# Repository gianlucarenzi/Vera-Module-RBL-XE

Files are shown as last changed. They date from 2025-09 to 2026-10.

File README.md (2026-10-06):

# VERA Module RBL-XE

<div align="center">






*🌐 English | [🌐 Italiano](#vera-module-rbl-xe-italiano)*

</div>

---

<div style="background: #ffffff; border-radius: 16px; padding: 24px; margin: 24px 0; box-shadow: 0 4px 12px rgba(0,0,0,0.1); border: 1px solid #e0e0e0;">

## 📋 Table of Contents

- [🔍 Overview](#-overview)
- [✨ Features](#-features)
- [⚙️ Technical Specifications](#️-technical-specifications)
- [🔧 Hardware Components](#-hardware-components)
- [🖼️ Board Preview](#️-board-preview)
- [📐 PCB Layers](#-pcb-layers)
- [🔌 Connectors & Interfaces](#-connectors--interfaces)
- [⚡ Power Requirements](#-power-requirements)
- [🔨 Assembly Instructions](#-assembly-instructions)
- [📦 Bill of Materials](#-bill-of-materials)
- [💻 Programming & Configuration](#-programming--configuration)
- [📁 Project Structure](#-project-structure)
- [🤝 Contributing](#-contributing)
- [📄 License](#-license)

</div>

---

<div style="background: #ffffff; border-radius: 16px; padding: 24px; margin: 24px 0; box-shadow: 0 4px 12px rgba(0,0,0,0.1); border: 1px solid #e0e0e0;">

## 🔍 Overview

The **VERA Module RBL-XE** is a sophisticated FPGA-based audio and video 
expansion card designed specifically for **ATARI XE** computers. 
This module brings modern graphics and audio capabilities to classic ATARI systems 
through the **PBI (Parallel Bus Interface)** protocol connectors.

### What is VERA?

**VERA** (Video Enhanced Retro Adapter) is originally designed for the 
Commander X16 computer but has been adapted for ATARI systems. It provides:

- **Advanced Graphics**: Multiple video layers, sprites, and high-resolution modes
- **Enhanced Audio**: Multi-channel digital audio with PCM and PSG capabilities  
- **Modern Connectivity**: VGA output, SD card storage, and USB programming
- **Retro Compatibility**: Integration with ATARI software with simple drivers

</div>

---

<div style="background: #ffffff; border-radius: 16px; padding: 24px; margin: 24px 0; box-shadow: 0 4px 12px rgba(0,0,0,0.1); border: 1px solid #e0e0e0;">

## ✨ Features

### 🎨 Graphics Capabilities

#### Video Output
- **VGA Output**: 640x480 @ 60Hz with analog RGB signals
- **Multiple Layers**: Background, foreground, and sprite layers
- **Color Depth**: 256 colors from a palette of 4096
- **Sprites**: Hardware-accelerated sprite engine
- **Scrolling**: Smooth horizontal and vertical scrolling

#### Audio Features
- **Digital Audio**: High-quality PCM audio output
- **Multi-channel**: Stereo audio
- **Audio Codec**: WM8524 for professional audio quality
- **3.5mm Jack**: Standard audio output connector

### 🔗 System Integration

#### ATARI Compatibility
- **PBI Interface**: Direct connection to ATARI XE systems
- **Memory Mapping**: $D1XX-$DFXX address space
- **Bus Decoder**: Full software address decoding in ESP32 — A0–A15 sampled every PHI2 cycle, no external hardware decoder required
- **Power Management**: Efficient 5V to 3.3V/1.2V conversion

#### Storage & Programming
- **SD Card Slot**: Micro SD for data storage and ROM loading
- **SPI Flash**: 16Mbit W25Q16 for FPGA configuration
- **USB Programming**: CH340 USB-to-serial for easy updates
- **SPI**: Direct FPGA programming interface

</div>

---

<div style="background: #ffffff; border-radius: 16px; padding: 24px; margin: 24px 0; box-shadow: 0 4px 12px rgba(0,0,0,0.1); border: 1px solid #e0e0e0;">

## ⚙️ Technical Specifications

### Core Specifications

| Component | Specification |
|---|---|
| **FPGA** | Lattice ICE40UP5K-SG48ITR |
| **Microcontroller** | ESP32-S3FN8 |
| **Flash Memory** | W25Q16JVSNIQ (16Mbit) |
| **Audio Codec** | WM8524CGEDT |
| **USB Interface** | CH340T |
| **Power Regulators** | AMS1117-3.3V, AMS1117-1.2V, L7805 |
| **Crystal (VERA board)** | 25 MHz ECS-2033-250-BN (ICE40UP5K reference clock) |
| **Crystal (ESP32-S3)** | 40 MHz external — required; XTAL\_P (QFN56 pin 56) / XTAL\_N (pin 55) |
| **PCB Layers** | 4-layer (Signal/Power/GND/Signal) |
| **Board Size** | TBD mm x TBD mm |

### Electrical Characteristics

| Parameter | Min | Typ | Max | Unit |
|---|-----|-----|-----|---|
| **Supply Voltage** | 4.5 | 5.0 | 5.5 | V |
| **Current Consumption** | - | 800 | 1200 | mA |
| **Operating Temperature** | -10 | 25 | 70 | °C |
| **VGA Output Impedance** | - | 75 | - | Ω |
| **Audio Output Level** | - | 2.0 | - | Vrms |

</div>

---

<div style="background: #ffffff; border-radius: 16px; padding: 24px; margin: 24px 0; box-shadow: 0 4px 12px rgba(0,0,0,0.1); border: 1px solid #e0e0e0;">

## 🔧 Hardware Components

### Main Processing Units

#### FPGA - ICE40UP5K
- **Logic Elements**: 5,280 LUTs
- **Memory**: 120 Kbit BRAM, 1 Mbit SPRAM
- **I/O Pins**: 39 user I/O
- **Package**: QFN-48 (7x7mm)
- **Programming**: SPI configuration

#### ESP32-S3FN8
- **CPU**: Dual-core Xtensa LX7 @ 240 MHz
- **Memory**: 8 MB in-package Quad SPI flash, 512 KB SRAM
- **Connectivity**: Wi-Fi 802.11 b/g/n, Bluetooth 5 LE
- **GPIO**: 45 total (38 usable), all bidirectional
- **Package**: QFN-56 (7×7 mm)
- **Crystal**: requires an external **40 MHz crystal** on dedicated analog pins XTAL\_P (QFN56 pin 56) and XTAL\_N (pin 55) — mandatory for PLL startup; see PIN-MAPPING.md § 5
- **Role**: Full software 6502-bus controller — reads A0–A15, PHI2, R/W every cycle and drives EXTSEL\_N, DEV\_SEL\_N, MPD in real time; handles PBI ($D1xx) and CCTL ($D5xx) in a single unified firmware
- **Timing**: hot loop on Core 1 at max FreeRTOS priority; control signals asserted via **Dedicated GPIO** Xtensa TIE instructions (`ee.get_gpio_in` / `ee.wr_mask_gpio_out`, 1 CPU cycle) within the 279 ns PHI2-high window of the 1.79 MHz 6502 clock

### Interface Components

#### Audio System
- **Codec**: WM8524CGEDT (24-bit, 192kHz)
- **Interface**: From FPGA digital audio bus
- **Output**: 3.5mm stereo jack
- **SNR**: >100dB

#### Video System
- **Output**: 15-pin VGA connector
- **Resolution**: 640x480 @ 60Hz
- **Colors**: 8-bit RGB (256 colors)
- **Sync**: Separate H/V sync signals

</div>

---

<div style="background: #ffffff; border-radius: 16px; padding: 24px; margin: 24px 0; box-shadow: 0 4px 12px rgba(0,0,0,0.1); border: 1px solid #e0e0e0;">

## 🖼️ Board Preview

### 3D Renderings

#### Top View
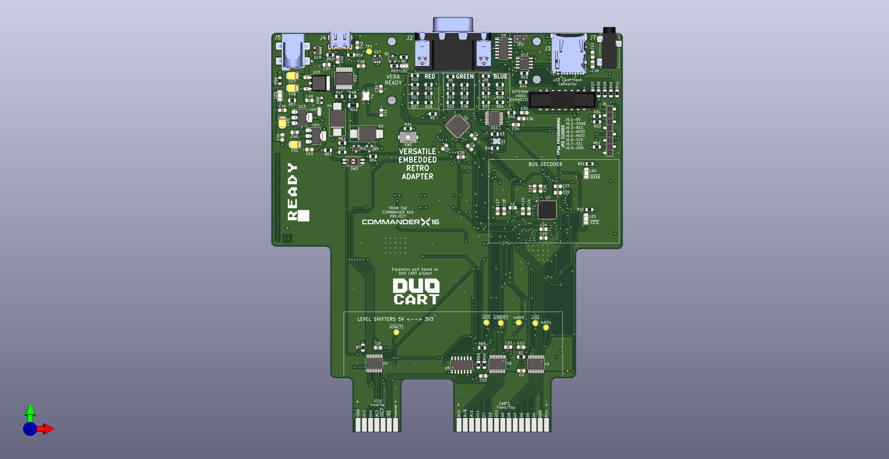
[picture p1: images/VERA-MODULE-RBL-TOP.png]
VERA Module Top

*Top side showing main components and connectors*

#### Bottom View  
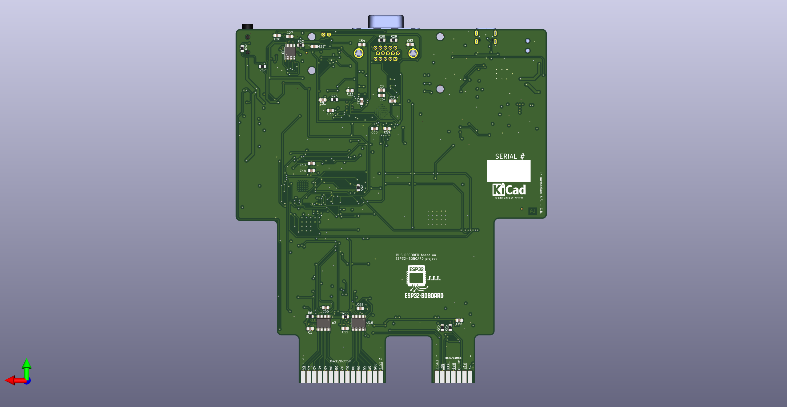
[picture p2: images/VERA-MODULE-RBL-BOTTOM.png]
VERA Module Bottom

*Bottom side with additional components*

#### Cartridge Adapter
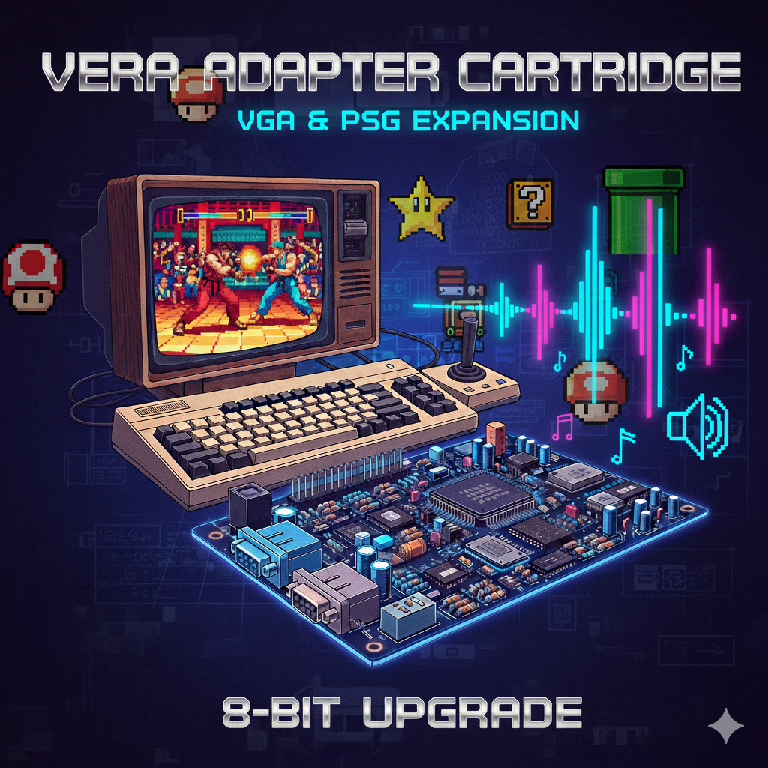
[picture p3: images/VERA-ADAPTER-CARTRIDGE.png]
VERA Cartridge Adapter

*Optional cartridge interface adapter*

### Board Dimensions

- **Length**: TBD mm
- **Width**: TBD mm  
- **Thickness**: 1.6mm (4-layer PCB)
- **Mounting**: Compatible with ATARI XE CART + ECI slots
- **Connectors**: Flat for space efficiency. It needs a custom 3D printed case

</div>

---

<div style="background: #ffffff; border-radius: 16px; padding: 24px; margin: 24px 0; box-shadow: 0 4px 12px rgba(0,0,0,0.1); border: 1px solid #e0e0e0;">

## 📐 PCB Layers

### Layer Stack-up

#### Layer 1 - Top Copper (F.Cu)
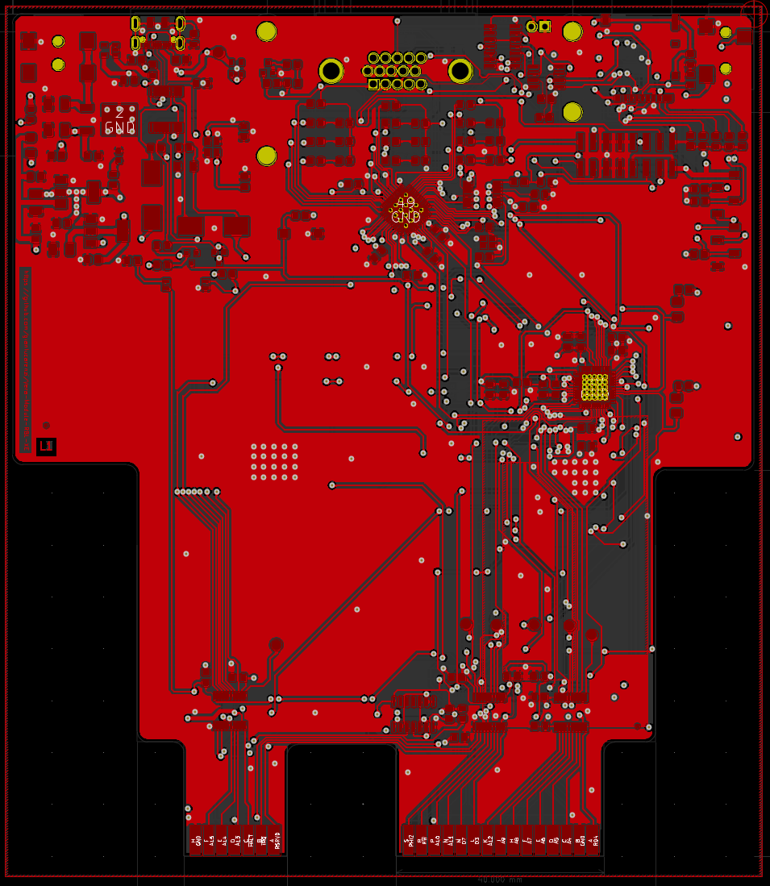
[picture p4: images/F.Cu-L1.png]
Top Copper Layer

*Component placement and signal routing*

#### Layer 2 - Power Plane (POWER)
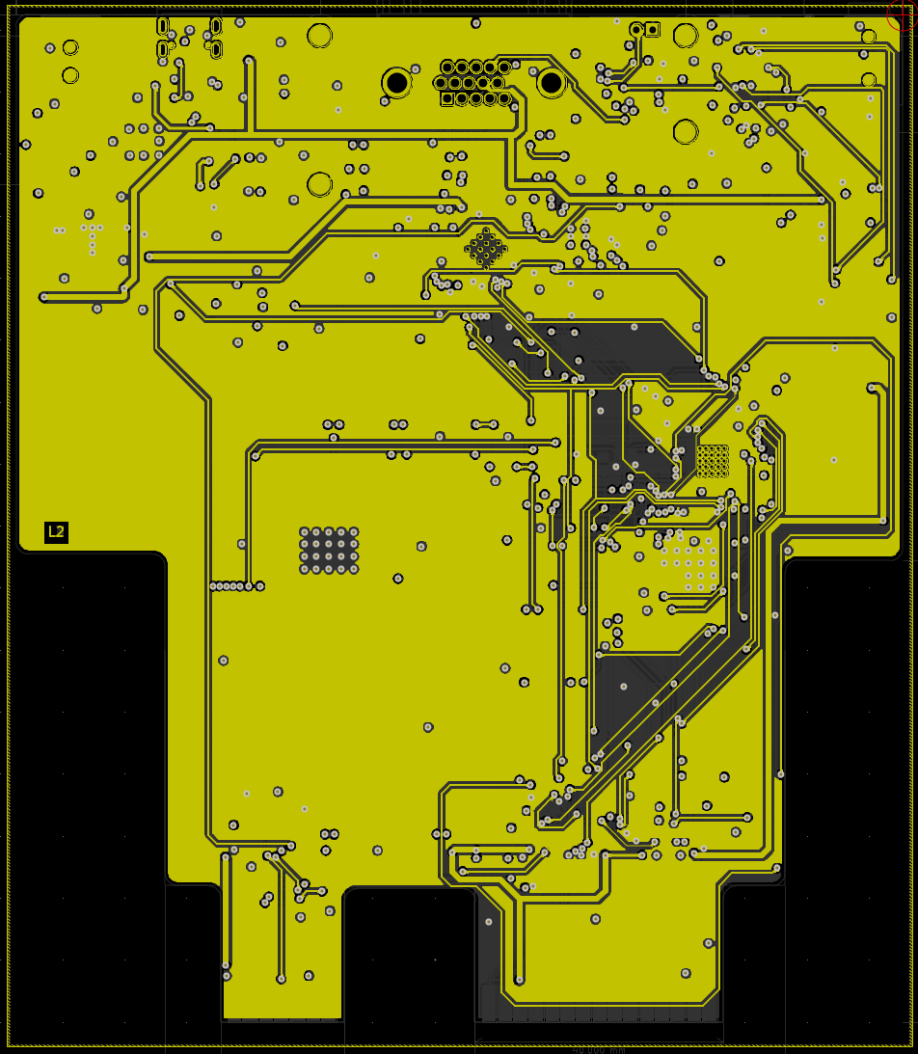
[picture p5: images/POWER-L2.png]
Power Layer

*5V, 3.3V, and 1.2V power distribution*

#### Layer 3 - Ground Plane (GND)
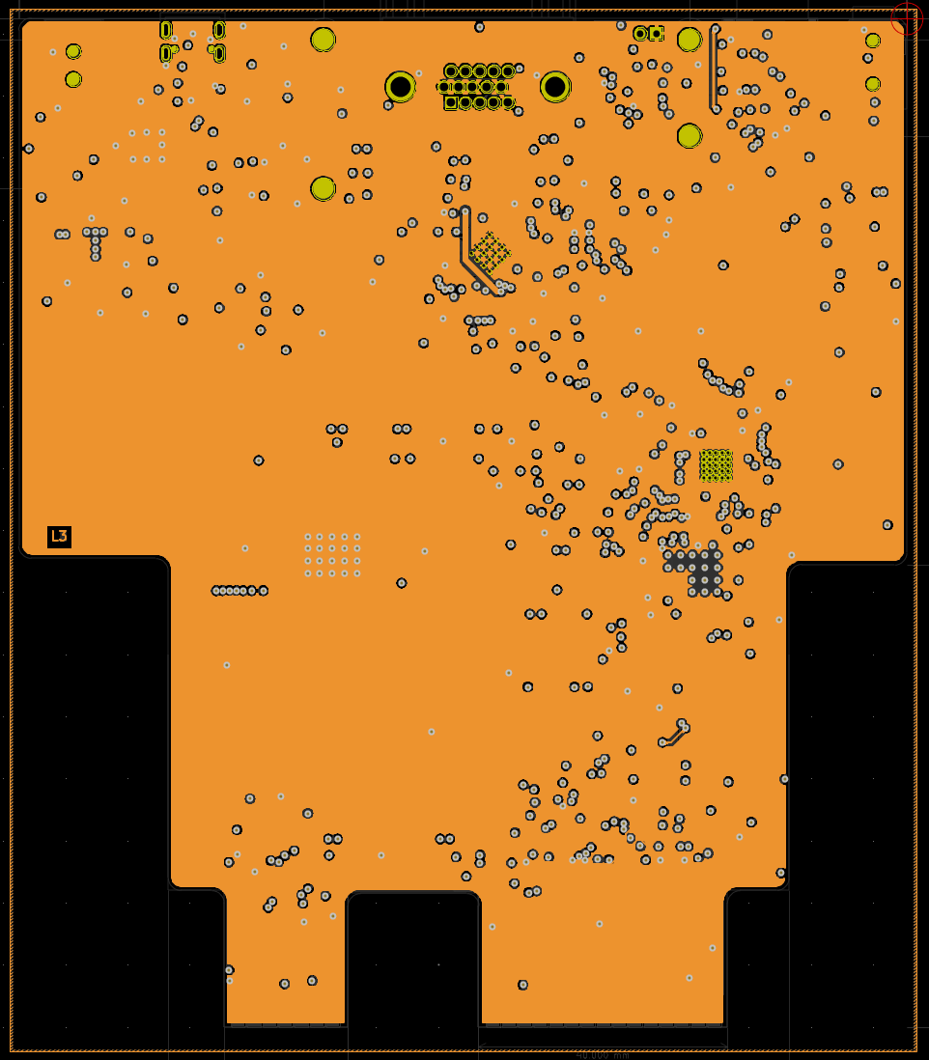
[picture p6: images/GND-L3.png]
Ground Layer

*Solid ground plane for signal integrity*

#### Layer 4 - Bottom Copper (B.Cu)
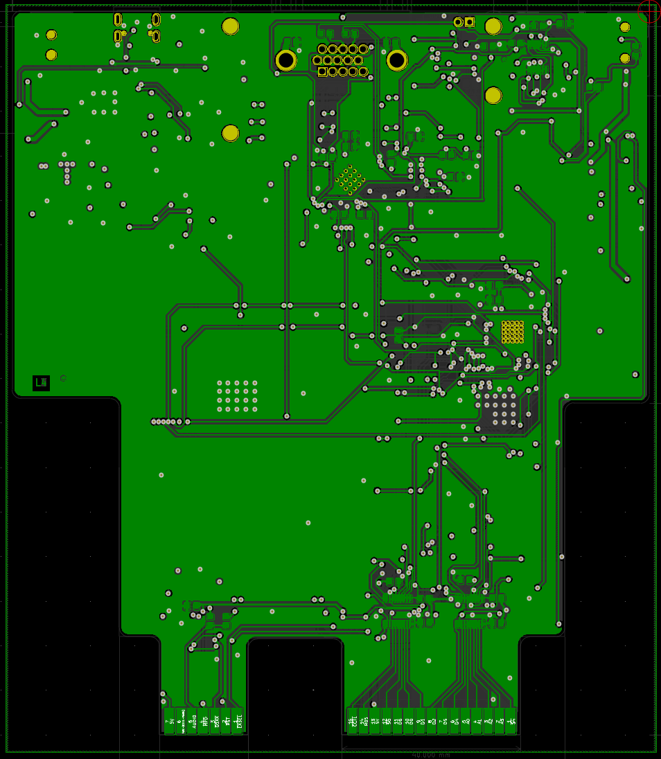
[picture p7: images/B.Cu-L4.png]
Bottom Copper Layer

*Additional signal routing and components*

</div>

---

<div style="background: #ffffff; border-radius: 16px; padding: 24px; margin: 24px 0; box-shadow: 0 4px 12px rgba(0,0,0,0.1); border: 1px solid #e0e0e0;">

## 🔌 Connectors & Interfaces

### External Connections

#### ATARI XE Interface
- **Cartridge Connector**: Classic Cartridge Edge Connector 30 pin 
- **ECI Slot**: Enhanced Cartridge Interface 14 pin 
- **Address Range**: $D1XX-$DFXX
- **Signals**: Data bus, address bus, control signals

#### Video Output (J2)
| Pin | Signal | Description |
|-----|---|---|
| 1-3 | RGB | Red, Green, Blue analog signals |
| 13-14 | H/V Sync | Horizontal/Vertical sync |
| 6-10 | GND | Ground connections |
| 11-12 | Audio L/R | Stereo audio output |

#### Storage Interfaces
- **SD Card Slot (J3)**: Micro SD card interface
- **SPI Flash**: On-board 16Mbit storage
- **USB Port (J4)**: Programming and data transfer

### Programming Interfaces

#### ICEPROG Connector (J6)
| Pin | Signal | Function |
|-----|---|---|
| 1 | 5V | Power supply |
| 2 | FPGA_CDONE/PULL-UP | FPGA Programmed |
| 3 | FPGA_RESET | FPGA Reset |
| 4 | MISO | SPI data in |
| 5 | MOSI | SPI data out |
| 6 | SCK | SPI clock |
| 7 | SS | SPI select |
| 8 | GND | Ground |

#### Reset & Control
- **Reset Button (SW1)**: ESP32 system reset
- **DIP Switch (SW2)**: Configuration options
- **Status LEDs**: Power, programming, activity indicators

</div>

---

<div style="background: #ffffff; border-radius: 16px; padding: 24px; margin: 24px 0; box-shadow: 0 4px 12px rgba(0,0,0,0.1); border: 1px solid #e0e0e0;">

## ⚡ Power Requirements

### Power Distribution

#### Power Rails
| Rail | Voltage | Current | Components |
|---|---|---|---|
| **5V** | 5.0V ± 5% | 200mA | Input from ATARI, USB |
| **3.3V** | 3.3V ± 3% | 400mA | ESP32, logic, interfaces |
| **1.2V** | 1.2V ± 3% | 300mA | FPGA core voltage |

#### Power Sources
1. **ATARI PBI**: Primary 5V supply from computer
2. **USB**: Alternative 5V for programming/testing
3. **External**: Optional external 5V supply (J5)

#### Power Protection
- **Schottky Diodes**: Reverse polarity protection
- **Ferrite Beads**: EMI filtering
- **Decoupling**: Extensive capacitor network
- **Current Limiting**: Overcurrent protection

</div>

---

<div style="background: #ffffff; border-radius: 16px; padding: 24px; margin: 24px 0; box-shadow: 0 4px 12px rgba(0,0,0,0.1); border: 1px solid #e0e0e0;">

## 🔨 Assembly Instructions

### Component Assembly

#### Assembly Order
1. **SMD Components**: Start with smallest components (0603, 0805)
2. **ICs**: Place all integrated circuits
3. **Connectors**: Install all external connectors
4. **Through-hole**: Add any remaining THT components
5. **Testing**: Verify power rails before first power-on

#### Special Considerations
- **FPGA**: Use proper ESD precautions
- **BGA Components**: Requires professional assembly
- **Thermal Management**: Ensure adequate cooling
- **Impedance Control**: Maintain 50Ω for high-speed signals

### Testing & Validation

#### Power-On Tests
1. **Visual Inspection**: Check for shorts, proper orientation
2. **Power Rails**: Verify all voltages within tolerance
3. **Clock Signals**: Confirm oscillator operation
4. **Communication**: Test SPI, I2C, UART interfaces

#### Functional Tests
1. **FPGA Programming**: Load test bitstream
2. **Video Output**: Verify VGA signal generation
3. **Audio Output**: Test audio codec functionality
4. **ATARI Interface**: Confirm PBI communication protocol

</div>

---

<div style="background: #ffffff; border-radius: 16px; padding: 24px; margin: 24px 0; box-shadow: 0 4px 12px rgba(0,0,0,0.1); border: 1px solid #e0e0e0;">

## 📦 Bill of Materials

### Component Categories

#### Major Components
- **1x** ICE40UP5K-SG48ITR FPGA
- **1x** ESP32-S3FN8 Microcontroller  
- **1x** W25Q16JVSNIQ SPI Flash
- **1x** WM8524CGEDT Audio Codec
- **1x** CH340T USB Interface

#### Passive Components
- **23x** 1µF Capacitors (1206)
- **20x** 100nF Capacitors (1206)
- **6x** 10µF Capacitors (1206)
- **Various** Resistors (0805/1206)
- **1x** 25 MHz Crystal Oscillator (VERA board — ICE40UP5K reference clock)
- **1x** 40 MHz Crystal + 2×10 pF load capacitors (ESP32-S3 — mandatory)

#### Connectors
- **1x** 15-pin VGA Connector
- **1x** Micro SD Card Slot
- **1x** USB Type-C Connector
- **1x** 3.5mm Audio Jack
- **1x** 8-pin Programming Header

### Cost Analysis

| Category | Estimated Cost | Percentage |
|---|---|---|
| **FPGA** | $15-20 | 35% |
| **ESP32** | $8-12 | 20% |
| **Connectors** | $5-8 | 15% |
| **Passives** | $3-5 | 10% |
| **PCB** | $8-12 | 20% |
| **Total** | **$39-57** | **100%** |

*Costs are estimates for small quantity production*

</div>

---

<div style="background: #ffffff; border-radius: 16px; padding: 24px; margin: 24px 0; box-shadow: 0 4px 12px rgba(0,0,0,0.1); border: 1px solid #e0e0e0;">

## 💻 Programming & Configuration

### FPGA Programming

#### Programming Methods
1. **USB/Serial**: Using FTDI 232H adapter interface with iceprog
2. **SPI Direct**: Direct SPI flash programming

#### Programming Steps
```bash
# Install icestorm toolchain
sudo apt install fpga-icestorm

# Program FPGA via USB (The FPGA bitstream is not provided!)
iceprog vera_module.bin

# Verify programming
iceprog -c
```

#### Development Tools
- **IceStorm**: Open-source FPGA toolchain
- **Yosys**: Verilog synthesis
- **NextPNR**: Place and route
- **KiCad**: PCB design and layout

### ESP32 Configuration

#### ESP32 Firmware
The ESP32-S3FN8 (Core 1 hot loop) handles:
- **Startup sync**: ARESET and CRESET asserted LOW immediately in `setup()` (before `Serial.begin`). `MonitorTask` releases CRESET, polls CDONE until the ICE40UP5K bitstream is loaded (< 100 ms typical, 5 s timeout), then releases ARESET — Atari starts with bus and FPGA already ready
- **Bus Decoding**: Full software decode of A0–A15 sampled on every PHI2 rising edge — no page ambiguity
- **Dedicated GPIO**: Control signals (EXTSEL\_N, DEV\_SEL\_N, MPD) asserted in a single Xtensa TIE instruction (`ee.wr_mask_gpio_out`, 1 CPU cycle) within the 279 ns PHI2-high window
- **Data Bus Drive** *(PBI mode only)*: D0–D7 driven via `GPIO.out` for ROM ($D800–$DFFF) and RAM ($D600–$D7FF) reads; FPGA drives the bus in CCTL mode
- **Debugging**: UART0 on GPIO43 (TX) / GPIO44 (RX), 115200 baud

The operating mode is selected at compile time via `VERA_BOARD_IS_PBI` in `main.cpp`:

| `VERA_BOARD_IS_PBI` | Mode | Active ranges | Selection latch |
|---|---|---|---|
| `1` (default) | PBI | $D100–$D1FF, $D600–$D7FF, $D800–$DFFF | write `0x80` to $D1FF |
| `0` | CCTL | $D500–$D5FF | write `0x80` to $D5FF |

The **RAMbo 256 KB** emulator is always compiled in and enabled at runtime via **GPIO 3**
(`PIN_RAMBO_EN`, QFN56 pin 8) — no recompilation needed:

| GPIO 3 at boot | Effect |
|---|---|
| Pull-up 10 kΩ → VCC (HIGH) | RAMbo enabled — 256 KB bank-switched at $4000–$7FFF; PORTB ($D301) bit 4 selects active/inactive |
| Pull-down 10 kΩ → GND (LOW) | RAMbo disabled — $4000–$7FFF not intercepted |

Works in both PBI and CCTL mode. The hot loop snoops both **PBCTL** (`$D303`) and
**PORTB** (`$D301`): writes to `$D301` update the bank-selection register **only when**
PBCTL bit 2 = 1 (output register selected). When bit 2 = 0, `$D301` addresses the PIA
6520 DDR and the write is ignored for bank-switching purposes. `PORTB` initialises to
`0xFF` (RAME = 1, RAMbo inactive); `PBCTL` to `0x00` (bit 2 = 0, DDR exposed).

**Passive snooping vs. active driving — no conflict with the physical 6520.** The real
6520 PIA chip remains fully active on the Atari motherboard and responds to `$D301`/`$D303`
normally. The ESP32 does **not** replace the 6520 — it only snoops those bus cycles
(observes without driving). It only actively drives the data bus and asserts EXTSEL\_N
for the `$4000–$7FFF` window, where the 6520 is not mapped. PBCTL tracking is necessary
precisely because the snooping is passive: from the bus, a DDR write and an Output Register
write to `$D301` are **indistinguishable** — PBCTL state is the only way to tell them apart.

#### Programming ESP32
The firmware is built with **PlatformIO** (install via `pip install platformio`):
```bash
# Build firmware (edit VERA_BOARD_IS_PBI in main.cpp before building)
pio run -e esp32s3fn8

# Flash firmware — connect UART adapter to GPIO43/44
pio run -e esp32s3fn8 --target upload
```

> **Note**: USB CDC is disabled because GPIO 19 (USB D−) and GPIO 20 (USB D+) are reused
> as address lines A7 and A8. Use an external UART adapter on GPIO 43/44.

</div>

---

<div style="background: #ffffff; border-radius: 16px; padding: 24px; margin: 24px 0; box-shadow: 0 4px 12px rgba(0,0,0,0.1); border: 1px solid #e0e0e0;">

## 📁 Project Structure

### Repository Organization

```
Vera-Module-RBL-XE/
├── 📄 README.md                    # This documentation
├── 📄 PIN-MAPPING.md               # ESP32-S3 / level-shifter pin mapping
├── 📄 VERA-ATARI-HW-REQUIREMENTS.md # Hardware requirements & bring-up plan (from driver/emulator work)
├── 📄 LICENSE                      # GPL v3 license
├── ⚙️ VERA-MODULE-RBL.pro         # KiCad project file
├── 📄 VERA-MODULE-RBL.sch         # Main schematic
├── 🔧 VERA-MODULE-RBL.kicad_pcb   # PCB layout
├── 📄 VERA-MODULE-RBL.csv         # Bill of materials
├── 🐍 jlcpcb-check-bom.py        # BOM processing script
├── 📁 images/                      # Board images and renders
│   ├── 🖼️ VERA-MODULE-RBL-TOP.png
│   ├── 🖼️ VERA-MODULE-RBL-BOTTOM.png
│   ├── 🖼️ F.Cu-L1.png            # PCB layer images
│   ├── 🖼️ POWER-L2.png
│   ├── 🖼️ GND-L3.png
│   └── 🖼️ B.Cu-L4.png
├── 📁 production/                  # Manufacturing files
│   ├── 📄 *.gbl, *.gtl            # Gerber files
│   ├── 📄 *.drl                   # Drill files
│   └── 📄 *.gbrjob                # Job files
├── 📁 ibom/                       # Interactive BOM
│   └── 🌐 ibom.html
└── 📁 schematics/                 # Individual schematics
    ├── 📄 vera-fpga.sch           # FPGA module
    ├── 📄 busdecoder.sch          # Bus decoder
    ├── 📄 cartridgeInterface.sch   # Cartridge interface
    ├── 📄 vera-fpga-flash.sch     # Flash memory
    └── 📄 powersupply.sch         # Power management
```

### Hardware notes (read before bring-up)

- [`VERA-ATARI-HW-REQUIREMENTS.md`](VERA-ATARI-HW-REQUIREMENTS.md) — what the VERA FPGA
  requires from the bus, open points on this board (U19 output enable, WR hold time,
  push-pull IRQ), the gating logic for the data-bus transceiver output enable,
  reset/configuration sequence and the bring-up test plan.

### Design Files

#### KiCad Files
- **Schematic**: Multi-sheet hierarchical design
- **PCB Layout**: 4-layer board with controlled impedance
- **3D Models**: Custom component models
- **Footprints**: Custom connector footprints

#### Manufacturing Files
- **Gerber Files**: Industry-standard PCB fabrication
- **Drill Files**: NC drill and via specifications  
- **Pick & Place**: SMT assembly coordinates
- **BOM**: Component specifications with LCSC part numbers

</div>

---

<div style="background: #ffffff; border-radius: 16px; padding: 24px; margin: 24px 0; box-shadow: 0 4px 12px rgba(0,0,0,0.1); border: 1px solid #e0e0e0;">

## 🤝 Contributing

### Development Guidelines

#### Contributing Process
1. **Fork** the repository
2. **Create** a feature branch
3. **Make** your changes
4. **Test** thoroughly
5. **Submit** a pull request

#### Contribution Areas
- **Hardware Design**: PCB layout improvements
- **Firmware**: ESP32 and FPGA code
- **Documentation**: User guides and tutorials
- **Testing**: Validation and verification
- **Software**: Host applications and tools

#### Design Goals
- **Compatibility**: Maintain ATARI XE compatibility
- **Performance**: Optimize for speed and efficiency
- **Reliability**: Ensure robust operation
- **Manufacturability**: Design for production
- **Cost**: Balance features with affordability

</div>

---

<div style="background: #ffffff; border-radius: 16px; padding: 24px; margin: 24px 0; box-shadow: 0 4px 12px rgba(0,0,0,0.1); border: 1px solid #e0e0e0;">

## 📄 License

This project is licensed under the **GNU General Public License v3.0**.

### License Details

#### Permissions
- ✅ Commercial use
- ✅ Modification
- ✅ Distribution
- ✅ Patent use
- ✅ Private use

#### Limitations
- ❌ Liability
- ❌ Warranty

#### Conditions
- 📄 License and copyright notice
- 📄 State changes
- 📄 Disclose source
- 📄 Same license

For the complete license text, see the [LICENSE](LICENSE) file.

</div>

---

<div style="background: linear-gradient(135deg, #1976d2, #42a5f5); color: white; border-radius: 16px; padding: 32px; margin: 32px 0; box-shadow: 0 8px 24px rgba(25,118,210,0.3); text-align: center;">

## 💙 Support the Project

If you find this project useful, please consider:

🌟 **Starring** the repository  
🐛 **Reporting** issues  
🔧 **Contributing** improvements  
📢 **Sharing** with the community  

---

**Made with ❤️ by RetroBit Lab**

*Bringing modern capabilities to classic computers*

</div>

---

# VERA Module RBL-XE (Italiano)

<div align="center">

*[🌐 English](#vera-module-rbl-xe) | 🌐 Italiano*

</div>

---

<div style="background: #ffffff; border-radius: 16px; padding: 24px; margin: 24px 0; box-shadow: 0 4px 12px rgba(0,0,0,0.1); border: 1px solid #e0e0e0;">

## 📋 Indice

- [🔍 Panoramica](#-panoramica)
- [✨ Caratteristiche](#-caratteristiche)
- [⚙️ Specifiche Tecniche](#️-specifiche-tecniche)
- [🔧 Componenti Hardware](#-componenti-hardware)
- [🖼️ Anteprima Scheda](#️-anteprima-scheda)
- [📐 Layer PCB](#-layer-pcb)
- [🔌 Connettori e Interfacce](#-connettori-e-interfacce)
- [⚡ Requisiti di Alimentazione](#-requisiti-di-alimentazione)
- [🔨 Istruzioni di Assemblaggio](#-istruzioni-di-assemblaggio)
- [📦 Distinta Materiali](#-distinta-materiali)
- [💻 Programmazione e Configurazione](#-programmazione-e-configurazione)
- [📁 Struttura Progetto](#-struttura-progetto)
- [🤝 Contribuire](#-contribuire)
- [📄 Licenza](#-licenza-1)

</div>

---

<div style="background: #ffffff; border-radius: 16px; padding: 24px; margin: 24px 0; box-shadow: 0 4px 12px rgba(0,0,0,0.1); border: 1px solid #e0e0e0;">

## 🔍 Panoramica

Il **VERA Module RBL-XE** è una sofisticata scheda di espansione audio e video 
basata su FPGA, progettata specificamente per i computer **ATARI XE**. 
Questo modulo porta capacità grafiche e audio moderne ai sistemi ATARI classici 
attraverso i connettori cartuccia ed ECI per il supporto del protocollo **PBI (Parallel Bus Interface)**.

### Cos'è VERA?

**VERA** (Video Enhanced Retro Adapter) è originariamente progettato per il 
computer Commander X16 ma è stato adattato per i sistemi ATARI. Fornisce:

- **Grafica Avanzata**: Livelli video multipli, sprite e modalità ad alta risoluzione
- **Audio Migliorato**: Audio digitale multicanale con capacità PCM e PSG
- **Connettività Moderna**: Uscita VGA, storage su scheda SD e programmazione USB
- **Compatibilità Retro**: Integrazione con il software ATARI classico tramite semplici drivers

</div>

---

<div style="background: #ffffff; border-radius: 16px; padding: 24px; margin: 24px 0; box-shadow: 0 4px 12px rgba(0,0,0,0.1); border: 1px solid #e0e0e0;">

## ✨ Caratteristiche

### 🎨 Capacità Grafiche

#### Uscita Video
- **Uscita VGA**: 640x480 @ 60Hz con segnali RGB analogici
- **Livelli Multipli**: Livelli di sfondo, primo piano e sprite
- **Profondità Colore**: 256 colori da una palette di 4096
- **Sprite**: Motore sprite accelerato hardware
- **Scrolling**: Scorrimento orizzontale e verticale fluido

#### Caratteristiche Audio
- **Audio Digitale**: Uscita audio PCM di alta qualità
- **Multicanale**: Audio stereo
- **Codec Audio**: WM8524 per qualità audio professionale
- **Jack 3.5mm**: Connettore uscita audio standard

### 🔗 Integrazione Sistema

#### Compatibilità ATARI
- **Interfaccia PBI**: Connessione diretta ai sistemi ATARI XE/XL
- **Mappatura Memoria**: Spazio indirizzi $D1XX-$DFXX
- **Decodificatore Bus**: Decodifica software completa degli indirizzi nell'ESP32 — A0–A15 campionati ad ogni ciclo PHI2, nessun hardware decoder esterno richiesto
- **Gestione Alimentazione**: Conversione efficiente da 5V a 3.3V/1.2V

#### Storage e Programmazione
- **Slot Scheda SD**: Micro SD per storage dati e caricamento ROM
- **Flash SPI**: 16Mbit W25Q16 per configurazione FPGA
- **Programmazione USB**: CH340 USB-to-serial per aggiornamenti facili
- **SPI**: Interfaccia programmazione FPGA diretta

</div>

---

<div style="background: #ffffff; border-radius: 16px; padding: 24px; margin: 24px 0; box-shadow: 0 4px 12px rgba(0,0,0,0.1); border: 1px solid #e0e0e0;">

## ⚙️ Specifiche Tecniche

### Specifiche Principali

| Componente | Specifica |
|---|---|
| **FPGA** | Lattice ICE40UP5K-SG48ITR |
| **Microcontrollore** | ESP32-S3FN8 |
| **Memoria Flash** | W25Q16JVSNIQ (16Mbit) |
| **Codec Audio** | WM8524CGEDT |
| **Interfaccia USB** | CH340T |
| **Regolatori Alimentazione** | AMS1117-3.3V, AMS1117-1.2V, L7805 |
| **Cristallo (scheda VERA)** | 25 MHz ECS-2033-250-BN (clock di riferimento ICE40UP5K) |
| **Cristallo (ESP32-S3)** | 40 MHz esterno — obbligatorio; XTAL\_P (QFN56 pin 56) / XTAL\_N (pin 55) |
| **Layer PCB** | 4 layer (Segnale/Alimentazione/GND/Segnale) |
| **Dimensioni Scheda** | TBD mm x TBD mm |

### Caratteristiche Elettriche

| Parametro | Min | Tip | Max | Unità |
|---|-----|-----|-----|---|
| **Tensione Alimentazione** | 4.5 | 5.0 | 5.5 | V |
| **Consumo Corrente** | - | 800 | 1200 | mA |
| **Temperatura Operativa** | -10 | 25 | 70 | °C |
| **Impedenza Uscita VGA** | - | 75 | - | Ω |
| **Livello Uscita Audio** | - | 2.0 | - | Vrms |

</div>

---

<div style="background: #ffffff; border-radius: 16px; padding: 24px; margin: 24px 0; box-shadow: 0 4px 12px rgba(0,0,0,0.1); border: 1px solid #e0e0e0;">

## 🔧 Componenti Hardware

### Unità di Elaborazione Principali

#### FPGA - ICE40UP5K
- **Elementi Logici**: 5,280 LUT
- **Memoria**: 120 Kbit BRAM, 1 Mbit SPRAM
- **Pin I/O**: 39 I/O utente
- **Package**: QFN-48 (7x7mm)
- **Programmazione**: Configurazione SPI

#### ESP32-S3FN8
- **CPU**: Dual-core Xtensa LX7 @ 240 MHz
- **Memoria**: 8 MB flash Quad SPI integrata, 512 KB SRAM
- **Connettività**: Wi-Fi 802.11 b/g/n, Bluetooth 5 LE
- **GPIO**: 45 totali (38 usabili), tutti bidirezionali
- **Package**: QFN-56 (7×7 mm)
- **Quarzo**: richiede un **quarzo esterno 40 MHz** sui pin analogici dedicati XTAL\_P (QFN56 pin 56) e XTAL\_N (pin 55) — obbligatorio per il PLL di avvio; vedere PIN-MAPPING.md § 5
- **Ruolo**: Controllore bus 6502 completamente software — campiona A0–A15, PHI2, R/W ad ogni ciclo e pilota EXTSEL\_N, DEV\_SEL\_N, MPD tramite istruzioni **Dedicated GPIO** Xtensa TIE (1 ciclo CPU) nella finestra PHI2-high di 279 ns; gestisce PBI ($D1xx) e CCTL ($D5xx) con un unico firmware unificato

### Componenti Interfaccia

#### Sistema Audio
- **Codec**: WM8524CGEDT (24-bit, 192kHz)
- **Interfaccia**: Audio digitale dalla FPGA con bus dedicato
- **Uscita**: Jack stereo 3.5mm
- **SNR**: >100dB

#### Sistema Video
- **Uscita**: Connettore VGA 15-pin
- **Risoluzione**: 640x480 @ 60Hz
- **Colori**: RGB 8-bit (256 colori)
- **Sync**: Segnali H/V sync separati

</div>

---

<div style="background: #ffffff; border-radius: 16px; padding: 24px; margin: 24px 0; box-shadow: 0 4px 12px rgba(0,0,0,0.1); border: 1px solid #e0e0e0;">

## 🖼️ Anteprima Scheda

### Rendering 3D

#### Vista Superiore
VERA Module Top
*Lato superiore mostrando componenti principali e connettori*

#### Vista Inferiore
VERA Module Bottom
*Lato inferiore con componenti aggiuntivi*

#### Adattatore Cartuccia
VERA Cartridge Adapter
*Adattatore interfaccia cartuccia opzionale*

### Dimensioni Scheda

- **Lunghezza**: TBD mm
- **Larghezza**: TBD mm  
- **Spessore**: 1.6mm (PCB 4-layer)
- **Montaggio**: Compatibile con slot ATARI XE CART + ECI
- **Connettori**: Piatti per efficienza spazio. Necessita di case stampato in 3D

</div>

---

<div style="background: #ffffff; border-radius: 16px; padding: 24px; margin: 24px 0; box-shadow: 0 4px 12px rgba(0,0,0,0.1); border: 1px solid #e0e0e0;">

## 📐 Layer PCB

### Stack-up Layer

#### Layer 1 - Rame Superiore (F.Cu)
Top Copper Layer
*Posizionamento componenti e routing segnali*

#### Layer 2 - Piano Alimentazione (POWER)
Power Layer
*Distribuzione alimentazione 5V, 3.3V e 1.2V*

#### Layer 3 - Piano Massa (GND)
Ground Layer
*Piano massa solido per integrità segnale*

#### Layer 4 - Rame Inferiore (B.Cu)
Bottom Copper Layer
*Routing segnali aggiuntivo e componenti*

</div>

---

<div style="background: #ffffff; border-radius: 16px; padding: 24px; margin: 24px 0; box-shadow: 0 4px 12px rgba(0,0,0,0.1); border: 1px solid #e0e0e0;">

## 🔌 Connettori e Interfacce

### Connessioni Esterne

#### Interfaccia ATARI
- **Connettore PBI**: Connettore edge 50-pin
- **Slot ECI**: Enhanced Cartridge Interface
- **Range Indirizzi**: $D1XX-$DFXX
- **Segnali**: Bus dati, bus indirizzi, segnali controllo

#### Uscita Video (J2)
| Pin | Segnale | Descrizione |
|-----|---|---|
| 1-3 | RGB | Segnali analogici Rosso, Verde, Blu |
| 13-14 | H/V Sync | Sync orizzontale/verticale |
| 6-10 | GND | Connessioni massa |
| 11-12 | Audio L/R | Uscita audio stereo |

#### Interfacce Storage
- **Slot Scheda SD (J3)**: Interfaccia scheda Micro SD
- **Flash SPI**: Storage on-board 16Mbit
- **Porta USB (J4)**: Programmazione e trasferimento dati

### Interfacce Programmazione

#### Connettore ICEPROG (J6)
| Pin | Segnale | Funzione |
|-----|---|---|
| 1 | 5V | Alimentazione |
| 2 | FPGA_CDONE/PULL-UP | FPGA Programmata |
| 3 | FPGA_RESET | FPGA Reset |
| 4 | MISO | Dati SPI in ingresso |
| 5 | MOSI | Dati SPI in uscita |
| 6 | SCK | Clock SPI |
| 7 | SS | Selezione SPI |
| 8 | GND | Ground |

#### Reset e Controllo
- **Pulsante Reset (SW1)**: Reset sistema ESP32
- **DIP Switch (SW2)**: Opzioni configurazione
- **LED di Stato**: Indicatori alimentazione, programmazione, attività

</div>

---

<div style="background: #ffffff; border-radius: 16px; padding: 24px; margin: 24px 0; box-shadow: 0 4px 12px rgba(0,0,0,0.1); border: 1px solid #e0e0e0;">

## ⚡ Requisiti di Alimentazione

### Distribuzione Alimentazione

#### Rail Alimentazione
| Rail | Tensione | Corrente | Componenti |
|---|---|---|---|
| **5V** | 5.0V ± 5% | 200mA | Ingresso da ATARI, USB |
| **3.3V** | 3.3V ± 3% | 400mA | ESP32, logica, interfacce |
| **1.2V** | 1.2V ± 3% | 300mA | Tensione core FPGA |

#### Sorgenti Alimentazione
1. **PBI ATARI**: Alimentazione 5V primaria dal computer
2. **USB**: 5V alternativo per programmazione/test
3. **Esterno**: Alimentazione 5V esterna opzionale (J5)

#### Protezione Alimentazione
- **Diodi Schottky**: Protezione polarità inversa
- **Perle di Ferrite**: Filtraggio EMI
- **Disaccoppiamento**: Rete estesa di condensatori
- **Limitazione Corrente**: Protezione sovracorrente

</div>

---

<div style="background: #ffffff; border-radius: 16px; padding: 24px; margin: 24px 0; box-shadow: 0 4px 12px rgba(0,0,0,0.1); border: 1px solid #e0e0e0;">

## 🔨 Istruzioni di Assemblaggio

### Assemblaggio Componenti

#### Ordine Assemblaggio
1. **Componenti SMD**: Iniziare con componenti più piccoli (0603, 0805)
2. **IC**: Posizionare tutti i circuiti integrati
3. **Connettori**: Installare tutti i connettori esterni
4. **Through-hole**: Aggiungere eventuali componenti THT rimanenti
5. **Test**: Verificare rail alimentazione prima della prima accensione

#### Considerazioni Speciali
- **FPGA**: Usare precauzioni ESD appropriate
- **Componenti BGA**: Richiede assemblaggio professionale
- **Gestione Termica**: Assicurare raffreddamento adeguato
- **Controllo Impedenza**: Mantenere 50Ω per segnali alta velocità

### Test e Validazione

#### Test Accensione
1. **Ispezione Visiva**: Controllare cortocircuiti, orientamento corretto
2. **Rail Alimentazione**: Verificare tutte le tensioni entro tolleranza
3. **Segnali Clock**: Confermare funzionamento oscillatore
4. **Comunicazione**: Testare interfacce SPI, I2C, UART

#### Test Funzionali
1. **Programmazione FPGA**: Caricare bitstream di test
2. **Uscita Video**: Verificare generazione segnale VGA
3. **Uscita Audio**: Testare funzionalità codec audio
4. **Interfaccia ATARI**: Confermare comunicazione con protocollo PBI

</div>

---

<div style="background: #ffffff; border-radius: 16px; padding: 24px; margin: 24px 0; box-shadow: 0 4px 12px rgba(0,0,0,0.1); border: 1px solid #e0e0e0;">

## 📦 Distinta Materiali

### Categorie Componenti

#### Componenti Principali
- **1x** ICE40UP5K-SG48ITR FPGA
- **1x** ESP32-S3FN8 Microcontrollore
- **1x** W25Q16JVSNIQ Flash SPI
- **1x** WM8524CGEDT Codec Audio
- **1x** CH340T Interfaccia USB

#### Componenti Passivi
- **23x** Condensatori 1µF (1206)
- **20x** Condensatori 100nF (1206)
- **6x** Condensatori 10µF (1206)
- **Vari** Resistori (0805/1206)
- **1x** Oscillatore Cristallo 25 MHz (scheda VERA — clock di riferimento ICE40UP5K)
- **1x** Quarzo 40 MHz + 2×10 pF condensatori di carico (ESP32-S3 — obbligatorio)

#### Connettori
- **1x** Connettore VGA 15-pin
- **1x** Slot Scheda Micro SD
- **1x** Connettore USB Type-C
- **1x** Jack Audio 3.5mm
- **1x** Header Programmazione 8-pin

### Analisi Costi

| Categoria | Costo Stimato | Percentuale |
|---|---|---|
| **FPGA** | $15-20 | 35% |
| **ESP32** | $8-12 | 20% |
| **Connettori** | $5-8 | 15% |
| **Passivi** | $3-5 | 10% |
| **PCB** | $8-12 | 20% |
| **Totale** | **$39-57** | **100%** |

*I costi sono stime per produzione piccole quantità*

</div>

---

<div style="background: #ffffff; border-radius: 16px; padding: 24px; margin: 24px 0; box-shadow: 0 4px 12px rgba(0,0,0,0.1); border: 1px solid #e0e0e0;">

## 💻 Programmazione e Configurazione

### Programmazione FPGA

#### Metodi Programmazione
1. **USB/Seriale**: Usando interfaccia FTDI 232H per SPI USB con iceprog
2. **SPI Diretto**: Programmazione flash SPI diretta

#### Passi Programmazione
```bash
# Installare toolchain icestorm
sudo apt install fpga-icestorm

# Programmare FPGA via USB (Il bitstream FPGA non e' fornito!)
iceprog vera_module.bin

# Verificare programmazione
iceprog -c
```

#### Strumenti Sviluppo
- **IceStorm**: Toolchain FPGA open-source
- **Yosys**: Sintesi Verilog
- **NextPNR**: Place and route
- **KiCad**: Design e layout PCB

### Configurazione ESP32

#### Firmware ESP32
L'ESP32-S3FN8 (hot loop sul Core 1) gestisce:
- **Sincronizzazione startup**: ARESET e CRESET abbassati subito in `setup()` (prima di `Serial.begin`). `MonitorTask` rilascia CRESET, attende CDONE = HIGH (bitstream ICE40UP5K caricato, tipicamente < 100 ms, timeout 5 s), poi rilascia ARESET — l'Atari parte con bus e FPGA già operativi
- **Decodifica Bus**: Decodifica software completa di A0–A15 campionati ad ogni fronte di salita di PHI2 — nessuna ambiguità di pagina, nessun hardware decoder esterno
- **Dedicated GPIO**: I segnali di controllo (EXTSEL\_N, DEV\_SEL\_N, MPD) vengono affermati in una singola istruzione Xtensa TIE (`ee.wr_mask_gpio_out`, 1 ciclo CPU) nella finestra PHI2-high di 279 ns
- **Bus Dati** *(solo modalità PBI)*: D0–D7 pilotati via `GPIO.out` per letture ROM ($D800–$DFFF) e RAM ($D600–$D7FF); in modalità CCTL è la FPGA a guidare il bus
- **Debug**: UART0 su GPIO43 (TX) / GPIO44 (RX), 115200 baud

La modalità operativa è scelta a **tempo di compilazione** tramite `VERA_BOARD_IS_PBI` in `main.cpp`:

| `VERA_BOARD_IS_PBI` | Modalità | Range attivi | Latch selezione |
|---|---|---|---|
| `1` (default) | PBI  | $D100–$D1FF, $D600–$D7FF, $D800–$DFFF | write `0x80` su $D1FF |
| `0` | CCTL | $D500–$D5FF | write `0x80` su $D5FF |

L'emulatore **RAMbo 256 KB** è sempre compilato nel firmware e abilitato a runtime tramite
**GPIO 3** (`PIN_RAMBO_EN`, QFN56 pin 8) — nessuna ricompilazione necessaria:

| GPIO 3 al boot | Effetto |
|---|---|
| Pull-up 10 kΩ → VCC (HIGH) | RAMbo abilitato — 256 KB bank-switched a $4000–$7FFF; bit 4 di PORTB ($D301) seleziona attivo/inattivo |
| Pull-down 10 kΩ → GND (LOW) | RAMbo disabilitato — $4000–$7FFF non intercettato |

Funziona in entrambe le modalità PBI e CCTL. Il hot loop snoopa sia **PBCTL** (`$D303`)
sia **PORTB** (`$D301`): le write a `$D301` aggiornano il registro di selezione banco
**solo se** PBCTL bit 2 = 1 (Output Register selezionato). Quando bit 2 = 0, `$D301`
indirizza il DDR della PIA 6520 e la write viene ignorata. `PORTB` si inizializza a
`0xFF` (RAME = 1, RAMbo inattivo); `PBCTL` a `0x00` (bit 2 = 0, DDR esposto).

**Snooping passivo vs. pilotaggio attivo — nessun conflitto col 6520 fisico.** Il chip
6520 PIA rimane pienamente attivo sulla scheda madre dell'Atari e risponde a `$D301`/`$D303`
normalmente. L'ESP32 **non sostituisce** il 6520: osserva passivamente quei cicli bus senza
mai pilotare il bus dati per quegli indirizzi. Pilota attivamente D0–D7 e asserisce
EXTSEL\_N solo per la finestra `$4000–$7FFF`, dove il 6520 non è mappato. Il tracciamento
di PBCTL è necessario proprio perché lo snooping è passivo: dal bus, una write al DDR e una
write all'Output Register su `$D301` sono **indistinguibili** — lo stato di PBCTL è l'unico
modo per differenziarle.

#### Programmazione ESP32
Il firmware viene compilato con **PlatformIO** (installare con `pip install platformio`):
```bash
# Compila firmware (modificare VERA_BOARD_IS_PBI in main.cpp prima di compilare)
pio run -e esp32s3fn8

# Carica firmware — adattatore UART su GPIO43/44
pio run -e esp32s3fn8 --target upload
```

> **Nota**: USB CDC è disabilitato perché GPIO 19 (USB D−) e GPIO 20 (USB D+) sono
> riutilizzati come linee indirizzo A7 e A8. Usare un adattatore UART esterno su GPIO 43/44.

</div>

---

<div style="background: #ffffff; border-radius: 16px; padding: 24px; margin: 24px 0; box-shadow: 0 4px 12px rgba(0,0,0,0.1); border: 1px solid #e0e0e0;">

## 📁 Struttura Progetto

### Organizzazione Repository

```
Vera-Module-RBL-XE/
├── 📄 README.md                    # Questa documentazione
├── 📄 LICENSE                      # Licenza GPL v3
├── ⚙️ VERA-MODULE-RBL.pro         # File progetto KiCad
├── 📄 VERA-MODULE-RBL.sch         # Schema principale
├── 🔧 VERA-MODULE-RBL.kicad_pcb   # Layout PCB
├── 📄 VERA-MODULE-RBL.csv         # Distinta materiali
├── 🐍 jlcpcb-check-bom.py        # Script elaborazione BOM
├── 📁 images/                      # Immagini scheda e render
│   ├── 🖼️ VERA-MODULE-RBL-TOP.png
│   ├── 🖼️ VERA-MODULE-RBL-BOTTOM.png
│   ├── 🖼️ F.Cu-L1.png            # Immagini layer PCB
│   ├── 🖼️ POWER-L2.png
│   ├── 🖼️ GND-L3.png
│   └── 🖼️ B.Cu-L4.png
├── 📁 production/                  # File produzione
│   ├── 📄 *.gbl, *.gtl            # File Gerber
│   ├── 📄 *.drl                   # File drill
│   └── 📄 *.gbrjob                # File job
├── 📁 ibom/                       # BOM interattiva
│   └── 🌐 ibom.html
└── 📁 schematics/                 # Schemi individuali
    ├── 📄 vera-fpga.sch           # Modulo FPGA
    ├── 📄 busdecoder.sch          # Decodificatore bus
    ├── 📄 cartridgeInterface.sch   # Interfaccia cartuccia
    ├── 📄 vera-fpga-flash.sch     # Memoria flash
    └── 📄 powersupply.sch         # Gestione alimentazione
```

### File Design

#### File KiCad
- **Schema**: Design gerarchico multi-foglio
- **Layout PCB**: Scheda 4-layer con impedenza controllata
- **Modelli 3D**: Modelli componenti personalizzati
- **Footprint**: Footprint connettori personalizzati

#### File Produzione
- **File Gerber**: Fabbricazione PCB standard industria
- **File Drill**: Specifiche drill NC e via
- **Pick & Place**: Coordinate assemblaggio SMT
- **BOM**: Specifiche componenti con codici LCSC

</div>

---

<div style="background: #ffffff; border-radius: 16px; padding: 24px; margin: 24px 0; box-shadow: 0 4px 12px rgba(0,0,0,0.1); border: 1px solid #e0e0e0;">

## 🤝 Contribuire

### Linee Guida Sviluppo

#### Processo Contribuzione
1. **Fork** del repository
2. **Creare** un branch feature
3. **Apportare** le modifiche
4. **Testare** accuratamente
5. **Inviare** una pull request

#### Aree Contribuzione
- **Design Hardware**: Miglioramenti layout PCB
- **Firmware**: Codice ESP32 e FPGA
- **Documentazione**: Guide utente e tutorial
- **Test**: Validazione e verifica
- **Software**: Applicazioni host e strumenti

#### Obiettivi Design
- **Compatibilità**: Mantenere compatibilità ATARI XE/XL
- **Performance**: Ottimizzare per velocità ed efficienza
- **Affidabilità**: Assicurare funzionamento robusto
- **Producibilità**: Design per produzione
- **Costo**: Bilanciare caratteristiche con convenienza

</div>

---

<div style="background: #ffffff; border-radius: 16px; padding: 24px; margin: 24px 0; box-shadow: 0 4px 12px rgba(0,0,0,0.1); border: 1px solid #e0e0e0;">

## 📄 Licenza

Questo progetto è licenziato sotto la **GNU General Public License v3.0**.

### Dettagli Licenza

#### Permessi
- ✅ Uso commerciale
- ✅ Modifica
- ✅ Distribuzione
- ✅ Uso brevetti
- ✅ Uso privato

#### Limitazioni
- ❌ Responsabilità
- ❌ Garanzia

#### Condizioni
- 📄 Avviso licenza e copyright
- 📄 Dichiarare modifiche
- 📄 Rivelare sorgente
- 📄 Stessa licenza

Per il testo completo della licenza, vedere il file [LICENSE](LICENSE).

</div>

---

<div style="background: linear-gradient(135deg, #1976d2, #42a5f5); color: white; border-radius: 16px; padding: 32px; margin: 32px 0; box-shadow: 0 8px 24px rgba(25,118,210,0.3); text-align: center;">

## 💙 Supporta il Progetto

Se trovi utile questo progetto, considera di:

🌟 **Mettere una stella** al repository  
🐛 **Segnalare** problemi  
🔧 **Contribuire** miglioramenti  
📢 **Condividere** con la community  

---

**Realizzato con ❤️ da RetroBit Lab**

*Portando capacità moderne ai computer classici*

</div>

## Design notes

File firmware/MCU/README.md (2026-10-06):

# Vera-Module-RBL-XE — Firmware MCU

## 1. Introduzione

Firmware per il microcontrollore **ESP32-S3FN8** (QFN-56, 8 MB flash integrata,
dual-core Xtensa LX7 @ 240 MHz) montato sul modulo Vera-Module-RBL-XE.

> **Requisito hardware:** il chip richiede un **quarzo esterno 40 MHz** collegato
> ai pin dedicati **XTAL\_P** (QFN56 pin 54) e **XTAL\_N** (QFN56 pin 53).
> Senza di esso il chip non si avvia. Vedere `PIN-MAPPING.md` § 5 per il
> circuito consigliato (condensatori di carico, resistenza serie, layout PCB).

Il modulo si collega al computer **ATARI XE** tramite il connettore **PBI**
(Parallel Bus Interface) oppure tramite il segnale **CCTL** (Cartridge Control).
La modalità operativa è selezionata a **tempo di compilazione** tramite la macro
`VERA_BOARD_IS_PBI` in `main.cpp`: `1` per PBI (default), `0` per CCTL.
L'emulatore RAMbo 256 KB è sempre compilato nel firmware e abilitato a **runtime**
tramite il pin hardware `PIN_RAMBO_EN` (GPIO 3, QFN56 pin 8): pull-up 10 kΩ verso
VCC = RAMbo presente, pull-down 10 kΩ verso GND = assente. Funziona
indipendentemente dalla modalità PBI/CCTL.
Il bus indirizzi A0–A15 è decodificato completamente via software in entrambe
le modalità.

---

## 2. Architettura del Firmware

### Sequenza di startup (prima del hot loop)

`setup()` abbassa **ARESET** e **CRESET** immediatamente dopo il reclaim dei pin
JTAG — prima ancora di `Serial.begin` — garantendo che Atari e FPGA VERA rimangano
in reset per tutta la durata dell'inizializzazione ESP32.

`MonitorTask` ha priorità massima su Core 1 e preempta `setup()` appena viene
creato. Prima di entrare nel hot loop esegue la sequenza di sincronizzazione:

1. **CRESET → HIGH** (`GPIO.out1_w1ts`): la FPGA VERA esce dal reset e inizia il
   caricamento del bitstream dalla flash SPI on-board.
2. **Poll CDONE** (GPIO 39): attesa con `vTaskDelay(1)` finché il pin va HIGH —
   ICE40UP5K tipicamente < 100 ms. Timeout 5 s con log di errore.
3. **Attesa `VERA_POST_CDONE_DELAY_US`** (default 1000 µs): copre il power-on reset
   interno della VERA, che parte solo dopo `CDONE`.
4. **ARESET → HIGH** (`GPIO.out1_w1ts`): l'Atari esce dal reset. Da questo momento
   il bus è live e il hot loop deve rispondere ad ogni ciclo PHI2.

### Hot loop (Core 1, priorità massima FreeRTOS)

Il task `MonitorTask()` gira sul Core 1 con priorità `configMAX_PRIORITIES - 1`.
Ad ogni ciclo di clock del 6502 (PHI2 @ 1,79 MHz, finestra utile ≈ 279 ns a
240 MHz di CPU):

1. Attende il fronte di salita di PHI2 tramite **Dedicated GPIO in**
   (`ee.get_gpio_in`, 1 ciclo CPU anziché ~6 cicli via APB).
2. Legge il bus indirizzi A0–A15 e la linea R/W dai registri `GPIO.in` /
   `GPIO.in1.val` (due letture APB sequenziali).
3. Decodifica l'indirizzo via software (`decode_addr()`) e determina il range
   attivo in base alla modalità selezionata.
4. Afferma in modo atomico i segnali di controllo attivi-LOW tramite
   **Dedicated GPIO out** (`ee.wr_mask_gpio_out`, 1 ciclo CPU — tutti i segnali
   in un'unica istruzione TIE).
5. **Solo PBI:** se l'accesso è in lettura verso la ROM ($D800–$DFFF) o la RAM
   ($D600–$D7FF), guida il bus dati D0–D7 con `bus_drive()` (2 scritture APB).
   In CCTL mode l'ESP32 non tocca mai il bus dati — è la FPGA a rispondere.
6. Attende il fronte di discesa di PHI2, rilascia il bus e de-afferma i
   segnali di controllo con un'altra `ee.wr_mask_gpio_out`.

### Dedicated GPIO (modulo ESP32-S3)

Il modulo Dedicated GPIO dell'ESP32-S3 assegna fino a 8 canali in ingresso e
8 in uscita per core. L'accesso avviene tramite le istruzioni Xtensa TIE:

| Istruzione TIE | Helper C (IDF ≤ 5.0) | Latenza |
|---|---|---|
| `ee.get_gpio_in` | `cpu_ll_read_dedic_gpio_in()` | 1 ciclo |
| `ee.wr_mask_gpio_out` | `cpu_ll_write_dedic_gpio_mask(mask, val)` | 1 ciclo |

I canali configurati nel firmware:

| Bundle  | Canale | GPIO | Segnale | Nota |
|---|---|---|---|---|
| Input | bit 0  | GPIO 1 (pin 6) | PHI2 | Clock 6502 |
| Output  | bit 0  | GPIO 40 (pin 45)| DEV\_SEL\_N | Chip-select VERA |
| Output  | bit 1  | GPIO 41 (pin 47)| EXTSEL\_N | Disabilita MMU ATARI  |
| Output  | bit 2  | GPIO 42 (pin 48)| MPD | Disabilita Math Pack  |

I pin GPIO 39–42 erano originariamente riservati a JTAG; vengono liberati in
`setup()` tramite `gpio_reset_pin()` prima della creazione del bundle.

### Mappatura del bus (riepilogo)

| Segnale | GPIO | QFN-56 pin | Note |
|---|---|---|---|
| PHI2 | 1 | 6 | Input dedicated |
| R/W | 2 | 7 | Input |
| D0–D7 | 4–11 | 9–16 | Bus dati bidirezionale |
| A0–A9 | 12–21 | 17–27 | GPIO 19=USB D−, 20=USB D+ (USB disabilitato) |
| A10 | 35 | 40 | Address bit 10 (via U3) |
| A11 | 36 | 41 | Address bit 11 (via U3) |
| A12 | 33 | 38 | Address bit 12 (via U4) |
| A13 | 34 | 39 | Address bit 13 (via U4) |
| A14 | 45 | 51 | Address bit 14 (via U4) |
| A15 | 46 | 52 | Address bit 15 (via U4) |
| ARESET | 37 | 42 | System reset ATARI (output) |
| BOOT0 | 0 | 5 | Pulsante BOOT / auto-reset (non usato dal firmware) |
| CRESET | 38 | 43 | Chip reset VERA (output) |
| CDONE | 39 | 44 | VERA programmata (input) |
| RAMBO\_EN | 3 | 8 | RAMbo hardware enable (input, pull esterno 10 kΩ) |
| DEV\_SEL\_N  | 40 | 45 | Chip-select VERA (output, dedicated) |
| EXTSEL\_N | 41 | 47 | Disabilita MMU (output, dedicated)|
| MPD | 42 | 48 | Disabilita Math Pack (dedicated)  |
| Debug TX | 43 | 49 | UART0 TX (Serial) |
| Debug RX | 44 | 50 | UART0 RX (Serial) |

`decode_addr()` restituisce un indirizzo **16 bit** completo: nessuna ambiguità di
pagina. I bit A12–A15 sono catturati nella stessa lettura `GPIO.in1.val` già
eseguita per A10–A11 — zero cicli APB aggiuntivi nel hot loop.

Per la mappatura completa GPIO→QFN-56 e lo schema level shifter U4 vedere
`PIN-MAPPING.md` nella root.

---

## 3. Struttura dei File

```
firmware/MCU/
├── platformio.ini               # Ambienti: esp32s3fn8, esp32s3fn8-cctl
├── pre_build_6502.py            # Script pre-build PlatformIO: esegue make in 6502/
├── include/
│   ├── pbi-driver.h             # Strutture dati e costanti del protocollo PBI
│   └── vera_pbi_handler.h       # ROM 6502 compilata come array C (generato da make)
├── src/
│   └── main.cpp                 # Sorgente principale del firmware ESP32
└── 6502/
    ├── Makefile                 # Compila il driver e genera vera_pbi_handler.h
    ├── pbi-driver.ld            # Script linker (indirizzo base $D800, 2 KB)
    ├── inc/
    │   ├── vera_common.inc      # Simboli condivisi VERA/PBI (registri, costanti)
    │   └── pbi-driver.h        # Header interfaccia driver
    └── src/
        └── vera_pbi_handler.s   # Driver ROM PBI per la scheda FPGA VERA (ca65)
```

---

## 4. Modalità di Build

Ambienti PlatformIO disponibili (`platformio.ini`):

| Ambiente | Modalità | Note |
|---|---|---|
| `esp32s3fn8` | PBI (`$D1FF`) | produzione, scheda senza modifiche |
| `esp32s3fn8-cctl` | CCTL (`$D5FF`) | slot cartuccia |

Opzioni di compilazione (`-D`):

| Macro | Default | Effetto |
|---|---|---|
| `VERA_BOARD_IS_PBI` | 1 | 1 = PBI, 0 = CCTL (impostata dall'ambiente) |
| `VERA_TRACE_REGS` | 0 | log di ogni accesso ai registri VERA. **Solo debug**: costa ~1 µs nel loop del bus e può lasciare `DEV_SEL_N` asserito nel ciclo seguente |

La modalità PBI/CCTL è scelta tramite la macro in `main.cpp`:

```cpp
#define VERA_BOARD_IS_PBI 0x01   /* 1 = PBI (default), 0 = CCTL */
```

L'abilitazione del RAMbo non richiede ricompilazione: è determinata dal livello
del pin **GPIO 3** (`PIN_RAMBO_EN`, QFN56 pin 8) letto una volta in `setup()`.

| GPIO 3 al boot | Effetto |
|---|---|
| Pull-up 10 kΩ → VCC (HIGH) | `rambo_hw_enabled = true` — RAMbo attivo, segue bit 4 di PORTB |
| Pull-down 10 kΩ → GND (LOW) | `rambo_hw_enabled = false` — $4000–$7FFF non intercettato |

### Modalità PBI (`VERA_BOARD_IS_PBI = 1`)

> **Registri sempre presenti.** I registri VERA (`$D100–$D11F`) rispondono anche con il latch a
> 0: l'OS deseleziona la scheda (`$D1FF` = 0) subito dopo l'`INIT` e il driver non la
> riseleziona mai (selezionarla mappa la ROM e disattiva il Math Pack). Solo `MPD`, `EXTSEL_N`
> per `$D600–$DFFF` e il servizio della ROM/RAM PBI dipendono dalla selezione.

| Range | Segnali affermati | Dati bus |
|---|---|---|
| $D100–$D11F | EXTSEL\_N + DEV\_SEL\_N (**sempre**, indipendente dal latch) | VERA FPGA risponde |
| $D120–$D1FE | EXTSEL\_N (se selezionato) | non decodificato |
| $D1FF | latch VCS — **scrittura**: D7 = 1 seleziona, D7 = 0 deseleziona (si usa solo il proprio bit). **Lettura**: non pilotata (l'identificazione IRQ via `$D1FF` non è realizzabile con `U19`, vedere `VERA-ATARI-HW-REQUIREMENTS.md` §2.4) | — |
| $D600–$D7FF | EXTSEL\_N (se selezionato) | ESP32 → `ram_pbi[]` |
| $D800–$DFFF | MPD (se selezionato) | ESP32 → `pbi_driver[]` |

`build_drive_lut()` precalcola al boot le bitmask per D0–D7, rendendo
`bus_drive()` una sola scrittura APB a `GPIO.out`. Viene chiamata in PBI mode, e
anche in CCTL mode se RAMbo è abilitato via `PIN_RAMBO_EN` (le letture RAMbo richiedono `bus_drive()`).

### Modalità CCTL (`VERA_BOARD_IS_PBI = 0`)

| Range | Segnali affermati | Dati bus |
|---|---|---|
| $D500–$D5FE | DEV\_SEL\_N (se selezionato) | VERA FPGA risponde |
| $D5FF | latch CCTL — write `0x80` per selezionare | — |

L'ESP32 non guida D0–D7 per i propri registri in CCTL mode; nessuna RAM
(`ram_pbi`) né ROM (`pbi_driver`) esposta al 6502. Se RAMbo è abilitato via
`PIN_RAMBO_EN`, `bus_drive()` viene comunque usata per la finestra RAMbo $4000–$7FFF.

### Emulatore RAMbo 256 KB (`PIN_RAMBO_EN`)

L'ESP32 emula una scheda **RAMbo 256 KB** bank-switched a $4000–$7FFF.
Funziona sia in PBI mode sia in CCTL mode — è indipendente da `VERA_BOARD_IS_PBI`.
Il codice è sempre compilato nel firmware; l'abilitazione è hardware tramite
`PIN_RAMBO_EN` (GPIO 3, QFN56 pin 8), letto una sola volta in `setup()`.
Il meccanismo è identico all'hardware originale. La PIA 6520 dell'Atari espone due
registri sovrapposti a `$D301` — Output Register e Data Direction Register (DDR) — la
scelta dipende da **PBCTL** (`$D303`) bit 2 (CRB-2):

| PBCTL bit 2 | Registro accessibile a $D301 |
|---|---|
| **0** | Data Direction Register (DDR) — write **ignorate** ai fini del bank-switching |
| **1** | Output Register = **PORTB** — write **catturate** come selezione banco |

| PORTB bit | Nome | Significato |
|---|---|---|
| 4 = **0** | **RAME** | RAMbo **attivo** — finestra $4000–$7FFF → banco selezionato; EXTSEL\_N asserito |
| 4 = **1** | RAME | RAMbo disabilitato — RAM interna Atari risponde normalmente |
| 6,5,3,2 | B3:B0 | Selezione banco (0–15): `bank = ((portb>>2)&0x03)\|((portb>>3)&0x0C)` |

Tabella dei 16 valori PORTB ($D301):

| Banco | PORTB (hex) | PORTB (bin) | Bit attivi |
|---|---|---|---|
| 0  | $83 | 10000011 | — |
| 1  | $87 | 10000111 | bit 2 |
| 2  | $8B | 10001011 | bit 3 |
| 3  | $8F | 10001111 | bit 2,3 |
| 4  | $A3 | 10100011 | bit 5 |
| 5  | $A7 | 10100111 | bit 2,5 |
| 6  | $AB | 10101011 | bit 3,5 |
| 7  | $AF | 10101111 | bit 2,3,5 |
| 8  | $C3 | 11000011 | bit 6 |
| 9  | $C7 | 11000111 | bit 2,6 |
| 10 | $CB | 11001011 | bit 3,6 |
| 11 | $CF | 11001111 | bit 2,3,6 |
| 12 | $E3 | 11100011 | bit 5,6 |
| 13 | $E7 | 11100111 | bit 2,5,6 |
| 14 | $EB | 11101011 | bit 3,5,6 |
| 15 | $EF | 11101111 | bit 2,3,5,6 |

Il firmware nel hot loop:
1. **Snoopa `$D303`** (PBCTL) ad ogni write e aggiorna `PBCTL`.
2. **Snoopa `$D301`** (PORTB) solo se `PBCTL` bit 2 = 1 — altrimenti è un write DDR e viene ignorato.
3. Quando `rambo_active` (RAME = 0 e hardware presente) e l'indirizzo è in $4000–$7FFF:
   - Asserisce **EXTSEL\_N** per silenziare la RAM interna dell'Atari.
   - **Lettura**: guida D0–D7 con il byte dal banco in `extended_rambo_256k`.
   - **Scrittura**: memorizza il dato nel banco corrispondente.

#### Snooping passivo vs. pilotaggio attivo — nessun conflitto col 6520 fisico

Il chip **6520 PIA è fisicamente presente** sulla scheda madre dell'Atari e risponde a `$D301`/`$D303` esattamente come farebbe senza il modulo. Il firmware **non emula** il 6520: lo **snoopa**.

| Range | Chi risponde | Ruolo dell'ESP32 |
|---|---|---|
| `$D301` / `$D303` | 6520 PIA (hardware reale) | Solo snooping passivo — non pilota mai D0–D7 |
| `$4000–$7FFF` (RAMbo window) | ESP32 | Attivo: asserisce EXTSEL\_N, pilota D0–D7 |

Quando il 6502 scrive a `$D301` o `$D303`, il 6520 riceve e processa normalmente la transazione; l'ESP32 legge gli stessi dati sul bus e aggiorna le proprie shadow copy (`PORTB`, `PBCTL`). Non c'è mai contesa sul bus perché l'ESP32 non tenta mai di guidare D0–D7 per quegli indirizzi.

Il motivo per cui il firmware deve tracciare PBCTL è proprio questo: essendo un osservatore passivo, non può interrogare il 6520 per sapere quale registro è esposto a `$D301`. Dal bus, una write DDR e una write all'Output Register sono **indistinguibili** — stesse linee, stesso ciclo. Solo tenendo traccia di quanto scritto a `$D303` è possibile qualificare correttamente le write a `$D301`.

```
CPU scrive $FF → $D301 con PBCTL=0x00:
  ├── 6520: aggiorna il DDR (tutti pin output)  ← hardware reale
  └── ESP32: PBCTL & 0x04 = 0 → ignora          ← snooping qualificato

CPU scrive $83 → $D301 con PBCTL=0x34:
  ├── 6520: aggiorna l'Output Register, porta Port B = $83  ← hardware reale
  └── ESP32: PBCTL & 0x04 = 1 → PORTB = $83, banco 0       ← catturato
```

Sequenza tipica di init del sistema operativo Atari:

| Step | Write | Effetto |
|---|---|---|
| 1 | `$00` → `$D303` | PBCTL bit 2 = 0 → DDR selezionato a $D301 |
| 2 | `$FF` → `$D301` | Write DDR (tutti output) — **ignorata** dal firmware |
| 3 | `$34` → `$D303` | PBCTL bit 2 = 1 → Output Register selezionato a $D301 |
| 4 | `$NN` → `$D301` | Selezione banco — **catturata** e salvata in `PORTB` |

`PORTB` è inizializzato a `0xFF` (RAME = 1 → RAMbo disabilitato);
`PBCTL` a `0x00` (bit 2 = 0 → DDR esposto a $D301).

### Area RAM PBI

`ram_pbi[512]` — esposta a $D600–$D7FF in PBI mode — è l'area di
scambio dati tra ESP32 e 6502.

`extended_rambo_256k[256 KB]` — in IRAM BSS (zero Flash cost) — sempre presente
nel firmware; attivato a runtime solo se `PIN_RAMBO_EN` è HIGH al boot.

### Pre-build automatico del driver 6502

`platformio.ini` dichiara `extra_scripts = pre:pre_build_6502.py`. Lo script
viene eseguito da PlatformIO **prima di qualsiasi compilazione**, garantendo che
`include/vera_pbi_handler.h` sia sempre aggiornato rispetto ai sorgenti 6502.
Il `make` è incrementale: se i sorgenti non sono cambiati non rigenera nulla.

---

## 5. Compilazione e Flashing

È necessario avere **PlatformIO Core** installato (`pip install platformio`).

```bash
# Compila (firmware unificato PBI + CCTL)
pio run -e esp32s3fn8

# Carica il firmware — UART0: GPIO43=TX, GPIO44=RX
pio run -e esp32s3fn8 --target upload

# Monitor seriale (115200 baud)
pio device monitor
```

> **Nota:** USB CDC è disabilitato (`ARDUINO_USB_CDC_ON_BOOT=0`) perché
> GPIO 19 (USB D−) e GPIO 20 (USB D+) sono riutilizzati come linee indirizzo
> A7 e A8. Usare un adattatore UART esterno collegato ai pin GPIO 43/44.

---

## 6. Driver 6502 per ATARI

Il driver ROM risiede in `6502/src/vera_pbi_handler.s` ed è scritto in
assembly 6502 per la toolchain **ca65/ld65** (suite `cc65`). Occupa
$D800–$DFFF (2 KB) quando la scheda è selezionata tramite il latch PBI $D1FF.

Il `Makefile` nella directory `6502/`:
1. Assembla `vera_pbi_handler.s` (con `vera_common.inc` come dipendenza)
2. Linka il binario a $D800 tramite `pbi-driver.ld`
3. Converte il `.bin` in un array C `vera_pbi_handler[]` e lo copia in
   `../include/vera_pbi_handler.h`, pronto per essere incluso nel firmware ESP32

```bash
cd 6502
make

# Pulizia degli artefatti intermedi
make clean
```

> **Dipendenze**: `ca65`, `ld65` (pacchetto `cc65`) e `hexdump` devono essere
> nel `PATH`.

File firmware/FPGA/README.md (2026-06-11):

# FPGA Firmware — iCE40UP5K

6502 bus controller for the VERA RBL-XE module (Rev 4).  Implements PBI RAM,
PBI ROM (BRAM), RAMbo 256 KB bank-switched memory via external SRAM, and all
associated control signals.  A VHDL boolean generic (`VERA_IS_PBI`) produces
two separate bitstreams: **PBI mode** (latch `$D1FF`, PBI RAM/ROM in BRAM) and
**CCTL mode** (latch `$D5FF`, D[7]=1 selects, 0 EBR — Yosys eliminates dead
code).

## Memory map

| Range | Size | Function | Implementation |
|---|---|---|---|
| `$4000–$7FFF` | 16 KB window | RAMbo (bank-switched, 256 KB total) | External SRAM |
| `$D1FF` | 1 B | VERA_CS latch (write only) | Register |
| `$D301` | 1 B | PIA PORTB snoop (bank select) | Register |
| `$D303` | 1 B | PIA PBCTL snoop (RAMbo enable) | Register |
| `$D600–$D7FF` | 512 B | PBI RAM | BRAM (1 EBR block) |
| `$D800–$DFFF` | 2 KB | PBI ROM (6502 driver) | BRAM (4 EBR blocks) |

**BRAM usage (PBI mode)**: 5 of 30 EBR blocks on the iCE40UP5K.
**BRAM usage (CCTL mode)**: 0 EBR — no PBI RAM/ROM (`$D5FF` latch uses a register only).

> In CCTL mode the VERA_CS latch address changes to `$D5FF`: write `$80`
> (D[7]=1) to select VERA, write `$00` to deselect.

## Hardware

### FPGA
**Lattice iCE40UP5K-SG48** (QFN-48, 39 user I/O, 5280 LUTs, 120 Kbit BRAM,
1 Mbit SPRAM).

### External SRAM — RAMbo 256 KB
Any **512K×8 asynchronous SRAM**, 55 ns or faster, 5 V tolerant.
Recommended: **AS6C4008-55SIN** (Alliance Memory, SOP-32).

| SRAM pin | Connection |
|---|---|
| A[13:0] | 6502 A[13:0] — **direct PCB net**, no FPGA I/O pin used |
| A[17:14] | FPGA `SRAM_A_BANK[3:0]` (bank register) |
| A18 | **GND** (use lower 256 KB of the 512 KB chip) |
| DQ[7:0] | 6502 D[7:0] — **direct PCB net**, shared with FPGA D[7:0] |
| CE# | FPGA `SRAM_CE_N` |
| OE# | FPGA `SRAM_OE_N` |
| WE# | FPGA `SRAM_WE_N` |

This wiring uses only **7 new FPGA pins** for the full 256 KB RAMbo.
The total design occupies all 39 user I/O pins of the SG48 package.

### SPI flash (FPGA configuration)
Any **SPI NOR flash** compatible with the iCE40 boot protocol, e.g.
Winbond W25Q16 (2 MB) or W25Q32 (4 MB).

The flash is shared between the FPGA (reads bitstream at power-up) and the
programmer (writes the bitstream).  During programming the FPGA is held in
reset via `CRESET_B`.

### Programmer hardware
Any of the following work with `openFPGALoader` or `iceprog`:

| Hardware | Interface | Tool |
|---|---|---|
| FTDI FT232H breakout | SPI bitbang | `iceprog`, `openFPGALoader` |
| FTDI FT2232H breakout | MPSSE SPI | `iceprog`, `openFPGALoader` |
| Tigard | JTAG/SPI | `openFPGALoader` |
| Raspberry Pi (GPIO) | SPI bitbang | `openFPGALoader` |
| dirtyJTAG (STM32F103) | JTAG | `openFPGALoader` |

Programmer SPI wiring to SPI flash and FPGA:

```
Programmer    iCE40UP5K     W25Qxx flash
MOSI  ──────── SPI_SI ────── DI
MISO  ──────── SPI_SO ────── DO
SCK   ──────── SPI_SCK ───── CLK
CS#   ─────────────────────── CS#
CRST# ──────── CRESET_B
CDONE ──────── CDONE
```

### Reset sequencer — 74LVC1G08

A single **74LVC1G08** (SOT-23-5, 2-input AND gate) sequences the
power-on boot without any MCU or firmware.

**Boot sequence:**

| Phase | FPGA\_CDONE | VERA\_CDONE | VERA\_RESET# | ATARI\_RESET# |
|---|---|---|---|---|
| Power-on / FPGA loading | 0 | 0 | 0 (reset) | 0 (reset) |
| FPGA ready, VERA loading | 1 | 0 | 1 (free) | 0 (reset) |
| System ready | 1 | 1 | 1 (free) | 1 (free) |

Logic equations:
- `VERA_RESET#  = FPGA_CDONE`
- `ATARI_RESET# = FPGA_CDONE AND VERA_CDONE`

Circuit:

```
VCC --[4k7]--+-------- FPGA_CDONE (open-drain)
             |
             +--[33R]- VERA_RESET#
             |
             +-- A -\
                     +--- 74LVC1G08 ---[33R]--- ATARI_RESET#
             +-- B -/
             |
VCC --[4k7]--+-------- VERA_CDONE (open-drain)
```

The natural SPI flash loading times provide all delays
(~50–100 ms for the FPGA, ~200–500 ms for VERA). No RC timer needed.

**Why 74LVC and not 74HC?** The 74LVC family has 5V-tolerant inputs at
3.3V VCC. The CDONE signals are at 3.3V; the Atari RESET line is 5V TTL.
The 74LVC 3.3V output is a valid HIGH for 5V TTL (V_IH = 2.0V).

BOM: 1× 74LVC1G08 SOT-23-5, 2× 4.7kΩ 0402 (CDONE pullups),
2× 33Ω 0402 (RESET series) — under 0.30 EUR total.

---

## Toolchain

### FPGA toolchain

The recommended way to set up the toolchain is using the **OSS CAD Suite**, as the packages available in Debian 11 repositories are outdated and do not include the necessary GHDL plugin for Yosys.

#### Installing OSS CAD Suite (Recommended for Debian 11)

1. Download the latest Linux x64 archive from [OSS CAD Suite Releases](https://github.com/YosysHQ/oss-cad-suite-build/releases/latest).
2. Extract the archive (e.g., to `$HOME/oss-cad-suite`).
3. Add the bin directory to your PATH:

```bash
export PATH="$HOME/oss-cad-suite/bin:$PATH"
```

This suite includes `yosys`, `nextpnr-ice40`, `icepack`, `iceprog`, and `ghdl` with the `ghdl-yosys-plugin` already integrated.

#### Alternative: Manual installation via apt (Debian 12+)

```bash
# Debian / Ubuntu
sudo apt install fpga-icestorm nextpnr-ice40 yosys ghdl
```

The `ghdl-yosys-plugin` is required for VHDL synthesis and is usually not
packaged — build it from source:

```bash
git clone https://github.com/ghdl/ghdl-yosys-plugin
cd ghdl-yosys-plugin && make && sudo make install
```

### Flash programming tools

On modern distributions (e.g. Debian 12+), `openFPGALoader` can be installed via package manager:

```bash
sudo apt install openFPGALoader
```

On older distributions like **Debian 11 (Bullseye)**, it must be built from source:

```bash
# Install dependencies
sudo apt install git cmake make g++ pkg-config libusb-1.0-0-dev \
                 libhidapi-dev libgpiod-dev libusbmuxd-dev

# Build and install
git clone https://github.com/trabucayre/openfpgaloader
cd openfpgaloader && mkdir build && cd build
cmake .. -DCMAKE_INSTALL_PREFIX=$HOME
make -j$(nproc)
make install
```

`iceprog` is already included in `fpga-icestorm`.

### Tool roles

| Tool | Input | Output | Purpose |
|---|---|---|---|
| `ghdl` | VHDL sources | RTLIL | VHDL elaboration (via Yosys plugin) |
| `yosys` | RTLIL | `.json` netlist | Synthesis for iCE40 |
| `nextpnr-ice40` | `.json` + `.pcf` | `.asc` | Place & route |
| `icepack` | `.asc` | `.bin` | Pack ASCII bitstream into binary |
| `openFPGALoader` / `iceprog` | `.bin` | SPI flash | Write bitstream to board |

---

## Build

### 1. Build the 6502 ROM driver and generate the VHDL package

The PBI ROM (`$D800–$DFFF`) is pre-loaded into BRAM at synthesis time.
Its content comes from the assembled 6502 driver binary.

```bash
cd firmware/MCU/6502
make            # assembles vera_pbi_handler.s and generates:
                #   vera_pbi_handler.bin
                #   ../include/vera_pbi_handler.h
                #   ../../FPGA/pbi_rom_pkg.vhd   <-- VHDL ROM package
```

To regenerate only the VHDL package (when the binary already exists):

```bash
make fpga-rom
```

### 2. Synthesise, place & route, pack bitstream

Two bitstreams are built from the same VHDL via the `VERA_IS_PBI` generic:

```bash
cd firmware/FPGA
make pbi    # builds C6502_Interface_PBI.bin  (PBI connector, $D1xx)
make cctl   # builds C6502_Interface_CCTL.bin (cartridge port, $D5xx)
make        # builds both (default)
```

PBI build step-by-step:

```bash
# Synthesis: VHDL -> JSON netlist  (VERA_IS_PBI=true)
yosys -m ghdl -p \
    "ghdl --std=08 -gVERA_IS_PBI=true \
          custom_types.vhd pbi_rom_pkg.vhd C6502_Interface.vhd \
          -e C6502_Interface; \
     synth_ice40 -top C6502_Interface -json C6502_Interface_PBI.json"

# Place & route: JSON + PCF -> ASCII bitstream
nextpnr-ice40 --up5k --package sg48 \
    --json C6502_Interface_PBI.json \
    --pcf board-pin-mapping.pcf \
    --asc C6502_Interface_PBI.asc

# Pack binary bitstream  <-- this is what gets flashed
icepack C6502_Interface_PBI.asc C6502_Interface_PBI.bin
```

CCTL follows the same three steps with `-gVERA_IS_PBI=false` and `_CCTL` filename suffix.

### 3. Flash the bitstream

```bash
# openFPGALoader (recommended)
make flash-pbi      # equivalent to: openFPGALoader -b ice40_generic C6502_Interface_PBI.bin
make flash-cctl     # equivalent to: openFPGALoader -b ice40_generic C6502_Interface_CCTL.bin

# iceprog (FTDI FT2232H)
make flash-pbi-iceprog    # equivalent to: iceprog C6502_Interface_PBI.bin
make flash-cctl-iceprog   # equivalent to: iceprog C6502_Interface_CCTL.bin
```

### 4. Clean

```bash
make clean      # removes .json, .asc, .bin and LaTeX intermediates
```

### Measured synthesis results

| Resource | PBI | CCTL | Available |
|---|-----|---|---|
| ICESTORM\_LC | 87 | 1 | 5280 |
| EBR (BRAM) | 5 | 0 | 30 |
| User I/O | 39 | 39 | 39 |
| Fmax (CLK) | **62.72 MHz** | — | target 25 MHz |
| Bitstream size | ~104 KB | ~104 KB | — |

In CCTL mode Yosys eliminates all PBI RAM/ROM dead code (0 EBR, 1 LC).

---

## Pin assignment

Edit `board-pin-mapping.pcf` to match your schematic before running
`nextpnr-ice40`.  All pin numbers in the file are **placeholders**.

The CLK signal must be assigned to a **Global Buffer (GB) input** pin.
Valid GB pins on the iCE40UP5K SG48 package: 20, 28, 31, 38, 41, 43, 48.

**Valid user I/O pin numbers for SG48** (39 total):
```
2 3 4 6 9 10 11 12 13 14 15 16 17 18 19 20 21
23 25 26 27 28 31 32 34 35 36 37 38 39
40 41 42 43 44 45 46 47 48
```
Pins 1, 5, 7, 8, 22, 24, 29, 30, 33 are power/ground or reserved —
nextpnr rejects them with an error.

**I/O budget:** the design uses all 39 available pins.  The mode (PBI vs CCTL)
is compiled into the bitstream via `VERA_IS_PBI`, freeing pins 27–28 for
dedicated hardware functions: `PBI_ID_SEL` and `RAMBO_EN`.

### Pin table

| Signal | Dir | PCF pin\* | Description |
|---|-----|---|---|
| `CLK` | In | 35 | 25 MHz system clock — must be on a GB pin |
| `A[0]` | In | 40 | 6502 address bit 0 |
| `A[1]` | In | 41 | 6502 address bit 1 |
| `A[2]` | In | 42 | 6502 address bit 2 |
| `A[3]` | In | 43 | 6502 address bit 3 |
| `A[4]` | In | 44 | 6502 address bit 4 |
| `A[5]` | In | 45 | 6502 address bit 5 |
| `A[6]` | In | 46 | 6502 address bit 6 |
| `A[7]` | In | 47 | 6502 address bit 7 |
| `A[8]` | In | 48 | 6502 address bit 8 |
| `A[9]` | In | 6 | 6502 address bit 9 |
| `A[10]` | In | 2 | 6502 address bit 10 |
| `A[11]` | In | 3 | 6502 address bit 11 |
| `A[12]` | In | 4 | 6502 address bit 12 |
| `A[13]` | In | 26 | 6502 address bit 13 — also wired to SRAM A[13] on PCB |
| `A[14]` | In | 9 | 6502 address bit 14 |
| `A[15]` | In | 10 | 6502 address bit 15 |
| `D[0]` | InOut | 11 | 6502 data bit 0 — shared net with SRAM DQ[0] |
| `D[1]` | InOut | 12 | 6502 data bit 1 — shared net with SRAM DQ[1] |
| `D[2]` | InOut | 13 | 6502 data bit 2 — shared net with SRAM DQ[2] |
| `D[3]` | InOut | 14 | 6502 data bit 3 — shared net with SRAM DQ[3] |
| `D[4]` | InOut | 15 | 6502 data bit 4 — shared net with SRAM DQ[4] |
| `D[5]` | InOut | 16 | 6502 data bit 5 — shared net with SRAM DQ[5] |
| `D[6]` | InOut | 17 | 6502 data bit 6 — shared net with SRAM DQ[6] |
| `D[7]` | InOut | 18 | 6502 data bit 7 — shared net with SRAM DQ[7] |
| `PHI2` | In | 34 | 6502 phase-2 clock — synchronised internally, not used as FPGA clock |
| `RNW` | In | 36 | Read/Not-Write: high = read, low = write |
| `VERA_CS` | Out | 32 | VERA chip-select latch (active low) |
| `MPD` | Out | 31 | Machine Program Data — blocks Atari from driving D bus for `$D800–$DFFF` reads |
| `EXTSEL` | Out | 37 | External Select — blocks Atari internal RAM for PBI RAM and RAMbo accesses |
| `PBI_ID_SEL` | In | 27 | Hardware jumper to one of D[0..7]; sampled at `$D1FF` write (PBI mode only); `1` selects VERA, `0` deselects. Ignored in CCTL build. |
| `RAMBO_EN` | In | 28 | Pullup (VCC) = RAMbo enabled (follows PBCTL[2]); pulldown (GND) = RAMbo disabled hardware override |
| `SRAM_A_BANK[0]` | Out | 19 | SRAM A[14] — bank bit 0 = PORTB[2] |
| `SRAM_A_BANK[1]` | Out | 20 | SRAM A[15] — bank bit 1 = PORTB[3] |
| `SRAM_A_BANK[2]` | Out | 21 | SRAM A[16] — bank bit 2 = PORTB[5] |
| `SRAM_A_BANK[3]` | Out | 38 | SRAM A[17] — bank bit 3 = PORTB[6] |
| `SRAM_CE_N` | Out | 23 | SRAM chip enable (active low) |
| `SRAM_OE_N` | Out | 39 | SRAM output enable (active low) — read cycles only |
| `SRAM_WE_N` | Out | 25 | SRAM write enable (active low) — write cycles only |

\* Placeholder numbers — replace with actual schematic pad numbers.

---

## Source files

| File | Description |
|---|---|
| `C6502_Interface.vhd` | Top-level entity (Rev 4); `VERA_IS_PBI` generic selects PBI or CCTL mode |
| `custom_types.vhd` | BRAM array type definitions |
| `pbi_rom_pkg.vhd` | PBI ROM contents as VHDL constant (**auto-generated**) |
| `gen_pbi_rom_pkg.py` | Script: converts `.bin` → `pbi_rom_pkg.vhd` |
| `board-pin-mapping.pcf` | Pin constraints for iCE40UP5K SG48 (edit before use) |
| `Makefile` | Build and flash targets |

---

## RAMbo bank formula

The FPGA snoops writes to the Atari PIA registers to track the active bank:

```
PORTB  at $D301  — bank bits
PBCTL  at $D303  — bit 2 enables RAMbo

bank[1:0] = PORTB[3:2]
bank[3:2] = PORTB[6:5]
→ SRAM A[17:14] = { PORTB[6], PORTB[5], PORTB[3], PORTB[2] }
```

RAMbo is active only when `RAMBO_EN` (pin 28, hardware pullup to VCC)
**and** `PBCTL[2] = 1` (software enable via Atari OS).

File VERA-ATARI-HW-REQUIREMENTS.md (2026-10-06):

# VERA RBL-XE — Requisiti e verifiche hardware (dal lavoro su driver ed emulatore)

Documento di passaggio dal progetto software (`VERA_ATARI_PBI`: handler PBI, driver
`VERA.SYS`, test, emulatore `atari800`) al progetto della scheda reale.
Data: 2026-10-06.

## 0. Fonti e limiti

| Fonte | Cosa ho usato |
|---|---|
| HDL VERA 47.0.2 (`VERA_ATARI_PBI/fpga-vera/47.0.2/.../fpga/source/top.v`) | protocollo del bus, reset, IRQ, mappa registri |
| `VERA_ATARI_PBI` (`vera_pbi_handler.s`, `vera_common.inc`, `vera-tests/`) | cosa il software si aspetta dall'hardware |
| `atari800/src/pbi_verax16.c`, `pbi.c` | modello di riferimento (ora allineato all'HDL) |
| Questo repo: `PIN-MAPPING.md`, `firmware/MCU/README.md`, netlist `VERA-MODULE-RBL.net` (2026-09-01) | stato della scheda |

**Limiti.** I punti della sezione 2 sono ricavati dalla *netlist*: nessuna simulazione elettrica
e nessuna misura. La netlist è del 2026-09-01 e l'ultimo commit del repo ("deleted all tracks and
imported from schematics") può averla resa non allineata. Ogni punto marcato **VERIFICA** va
controllato sullo schema aggiornato, sui datasheet e con l'oscilloscopio.

Il software è stato provato solo in emulazione. La scheda reale non è mai stata vista dal
driver.

---

## 1. Cosa fa la VERA sul bus (dall'HDL 48.0.1)

Firmware di riferimento: **48.0.1** (`VERA_ATARI_PBI/fpga-vera/48.0.1`). Rispetto alla 47.0.2 l'HDL
cambia solo in tre punti: l'indirizzo di scrittura è catturato direttamente all'inizio di WR (prima
passava da un registro intermedio), i byte di versione restituiscono anche minor e build, e le onde
sawtooth/triangle del PSG sono in XOR con `~pulsewidth`. I requisiti per la scheda non cambiano.

Questi sono i vincoli che l'hardware deve rispettare, indipendentemente dal progetto.

| Aspetto | Comportamento reale (`top.v`) | Conseguenza per la scheda |
|---|---|---|
| Strobe | `bus_read = !cs_n && wr_n && !rd_n`, `bus_write = !cs_n && !wr_n` | servono RD_n e WR_n **distinti**; `rd_n` è ignorato se `wr_n` è basso |
| Scrittura | l'indirizzo è campionato sul fronte di **salita** di `bus_write` (inizio); il **dato** sul fronte di **discesa** (`negedge bus_write`, cioè fine scrittura) | il dato deve restare stabile fino **dopo** la salita di WR_n / CS_n (hold) |
| Lettura | `extbus_d` pilotato solo mentre `bus_read`; effetti collaterali (autoincremento, prefetch) sul fronte di discesa di `bus_read`, dopo 3 cicli di `clk25` (~120 ns) | un'attivazione di RD_n = un evento di lettura. Cicli doppi (RMW, dummy read) li duplicano |
| Reset | solo POR interno (`por_cnt_r`, 128 cicli di `clk25`); **nessun pin di reset** | il RESET Atari non resetta la VERA |
| CTRL bit 7 (`$D105`) | `fpga_reconfigure` → ricarica l'intero bitstream: VRAM persa, bus morto ~100 ms | scrittura distruttiva; vedi §3 |
| IRQ | `extbus_irq_n = (irq_status & irq_enable) == 0`: **push-pull**, a livello | non può pilotare direttamente una linea IRQ condivisa |
| Registri FX | in sola scrittura (la lettura di `$D109-$D10C` con DCSEL≥2 restituisce i byte di identità del firmware, `'V',48,0,1` sulla 48.0.1, tranne FX_CTRL e POLY_FILL_L/H) | niente read-back di FX |

---

## 2. Verifiche e modifiche sulla scheda attuale

Priorità: **A** = da risolvere prima del primo test sul bus, **B** = da risolvere prima del
rilascio, **C** = da decidere.

### 2.1 [A] Il bus dati può fare contesa su letture non destinate alla scheda — VERIFICA

Dalla netlist:
- `U19` (74LVC4245, bus dati): `~OE_` (pin 22) è collegato **solo** a `NOT(PHI2)` (`U23` pin 3→4);
  `DIR` (pin 2) è `NOT(R/W)` (`U23` pin 1→2).
- Quindi `U19` è abilitato in **ogni** ciclo con PHI2 alto, qualunque sia l'indirizzo.

In un ciclo di lettura (R/W = 1) `DIR` = 0, cioè verso l'Atari (nella netlist `VCCA` è a 5 V,
quindi il lato A di `U19` è quello Atari e il lato B quello 3,3 V della scheda). In un ciclo di
lettura di **altra** memoria (RAM, ROM OS, cartuccia) `U19` pilota comunque il bus dati
dell'Atari dal lato scheda, dove i GPIO dell'ESP32 e le uscite dell'FPGA sono Hi-Z e non
pilotati. Un 74LVC4245 non ha bus-hold, quindi la contesa con RAM/ROM sul bus è probabile,
con possibili errori di lettura in tutto il sistema.

Richiesta: `~OE_` di `U19` deve essere attivo **solo** quando la scheda risponde in lettura
(registri VERA, RAM `$D600-$D7FF`, ROM `$D800-$DFFF`, finestra RAMbo), oppure in scrittura
(Atari→scheda, dove `U19` pilota solo il lato scheda). **Non** va collegato a `CDONE`: quello
segnala solo la configurazione dell'FPGA ed è già usato per rilasciare `ARESET`. Il gating è
ciclo per ciclo.

I segnali che indicano "la scheda risponde" esistono già: il firmware abbassa `DEV_SEL_N` (registri
VERA), `EXTSEL_N` (RAM `$D6xx`, RAMbo) e `MPD` (ROM `$D800`) quando la scheda risponde, e li rialza a
fine ciclo. Quindi:

```
~OE_ = NOT( PHI2 AND ( NOT R/W   OR   ~DEV_SEL_N OR ~EXTSEL_N OR ~MPD ) )
```

Con porte a 3,3 V:

```
A    = AND3(DEV_SEL_N, EXTSEL_N, MPD)    ; 1 quando nessuno risponde
B    = NAND(R/W, A)                       ; 1 se scrittura oppure la scheda risponde
~OE_ = NAND(PHI2, B)                      ; verso U19 pin 22 (al posto di NOT(PHI2))
```

Parti: un `74LVC11` (AND a tre ingressi) e due NAND. Una NAND è la quarta porta libera di `U5`
(pin 12 e 13, oggi a GND) se `U5` diventa un 74LVC00 come richiesto in §2.2; l'altra può essere un
`74LVC1G00`. `NOT R/W` esiste già (`U23` pin 2, che pilota `DIR`); `DIR` resta invariato.
Il pin 22 non deve più essere collegato a `U23` pin 4.

Da controllare:
- **Tempi.** `DEV_SEL_N`, `EXTSEL_N` e `MPD` vengono asseriti dall'ESP32 dopo la salita di PHI2
  (latenza del firmware più i ritardi di porta): `~OE_` si abbassa in ritardo. Il dato in
  lettura deve comunque essere valido alla CPU prima della discesa di PHI2 meno il suo tempo di
  setup. Da misurare con l'oscilloscopio.
- **`$D1FF` in lettura non abilita `U19`** (nessun segnale di risposta è asserito): è voluto, vedere §2.4.
- **Scritture.** `U19` resta abilitato in ogni scrittura: l'ESP32 deve vedere tutte le scritture
  (`$D301`, `$D303`, latch `$D1FF`, finestra RAMbo).

### 2.2 [A] Hold del dato sul fronte di salita di WR_n — VERIFICA

- `~mWE` e `~mRE` sono generati da `U5` (74HC00): `~mRE = NAND(PHI2, R/W)`,
  `~mWE = NAND(PHI2, NOT R/W)` (la negazione è un'altra porta NAND di `U5`).
- La VERA campiona il dato in scrittura alla **salita di WR_n**, cioè circa un ritardo di
  porta dopo la discesa di PHI2.
- Lo stesso evento (discesa di PHI2) disabilita `U19` tramite `U23` (inverter HCT04) e il
  buffer: il dato verso la VERA può diventare non valido più o meno nello stesso istante in cui
  WR_n sale. In più il 6502C mantiene il dato per un tempo minimo dopo PHI2 (verificare il valore sul
  datasheet SALLY/6502C).

Richieste:
1. Usare una porta più veloce di 74HC00 a 3,3 V (per esempio 74LVC00 / 74AHC00).
2. Rendere il rilascio di `U19` **più lento** della salita di WR_n (per esempio ritardare `~OE_`),
   oppure usare un solo percorso di ritardo per strobe e dato, così che il margine di hold sia
   positivo.
3. Verificare con analizzatore logico/oscilloscopio: dato stabile ≥ 5 ns dopo la salita di
   `~mWE` e `~mVCS0` al pin FPGA.

### 2.3 [A] Linea IRQ push-pull verso il bus Atari — VERIFICA

- `~mVIRQ` (FPGA, pin 32) va a `U16` pin 18 → `~IRQ` (`U16` pin 6) → `ECI1` pin B. C'è un
  pull-up `R65` sulla rete `~mVIRQ`.
- L'uscita VERA è push-pull (§1). Il bus Atari ha una linea IRQ **open-collector** condivisa
  con POKEY, PIA e altri device: un'uscita push-pull in alto contro un altro device che tira
  in basso crea contesa.

Richiesta: tra FPGA e ECI usare uno stadio open-drain/open-collector con uscita tollerante a
5 V. Una linea IRQ open-collector è un OR cablato: ogni device può solo **tirarla in basso**,
mai in alto; il livello alto lo dà l'unico pull-up sul computer. Aggiungere un proprio stadio
open-drain dà esattamente questo comportamento con POKEY, PIA e gli altri device.

**Soluzione consigliata (un componente).** `74LVC1G07` (buffer non invertente open-drain, SOT-23-5
o SC-70-5), alimentato a 3,3 V:

```
 3V3 ──┬── Vcc (pin 5)
       └── 100 nF ── GND
 ~mVIRQ (FPGA, 3,3 V, attivo basso) ──► A (pin 2)      GND (pin 3)
 Y (pin 4, open-drain) ──► ECI1 pin B (~IRQ, 5 V)   [nessun pull-up proprio verso 5 V]
```

- Uscita bassa quando l'FPGA chiede IRQ, alta impedenza altrimenti: non invertente, quindi la
  polarità resta quella di `~mVIRQ` (basso = IRQ).
- L'uscita open-drain dell'LVC1G07 tollera 5,5 V (Ioff), quindi il pull-up da 5 V sul computer non
  la danneggia, anche con la scheda spenta.
- VOL tipico < 0,4 V a qualche mA: la corrente tipica del pull-up IRQ Atari (circa 1-1,5 mA con
  3,3-4,7 kΩ, **verificare sul computer di prova**) è ampiamente entro i limiti.
- **Modifica sulla scheda attuale:** (1) staccare `U16` pin 6 dalla rete `~IRQ` (altrimenti resta
  l'uscita push-pull in parallelo); (2) collegare `Y` a `ECI1` pin B; (3) lasciare l'ingresso di
  `U16` pin 18 collegato a `~mVIRQ` (innocuo, uscita non utilizzata). `R65` (10 kΩ sul lato
  3,3 V) può restare come pull-up dell'ingresso dello stadio.

**Alternative.** (a) `BSS138`/`2N7002` con gate pilotato da `NOT(~mVIRQ)`, per esempio da un
`74LVC1G04`: due componenti; (b) diodo Schottky (BAT54) con anodo su `~IRQ` e catodo su
`~mVIRQ`: funziona come OR cablato, ma il livello basso risulta VOL(FPGA) + Vf (circa 0,6-0,7 V)
vicino al limite TTL di 0,8 V, quindi sconsigliato.

**Gestione dell'IRQ.** Con lo stadio open-drain basta un gancio software sul vettore IRQ (vedere §2.4):
non serve nessun collegamento aggiuntivo all'ESP32.

**Cosa NON fare.** Non lasciare l'uscita push-pull verso il bus, non aggiungere un pull-up a
5 V sulla scheda (la linea ha già il suo) e non usare un 74LVC4245 per questo segnale: non ha
uscite open-drain.

### 2.4 [A] Identificazione dell'IRQ: via software, non tramite `$D1FF`

**Perché non tramite `$D1FF`.** Il PBI prevede che ogni device pilota il proprio bit (la VERA: D7) in
lettura di `$D1FF`, con gli altri bit Hi-Z, e che l'OS legga `$D1FF & PDIMSK` per scegliere la ROM da
chiamare. Con la scheda attuale non è realizzabile:
- `U19` è un 74LVC4245: abilita **tutti e otto** i canali o nessuno. Pilotare solo D7 dal lato ESP32
  lascerebbe D0-D6 del lato scheda non pilotati, e `U19` li porterebbe sul bus Atari a un livello
  casuale, in contesa con i bit di eventuali altri device PBI. Con la regola di §2.1 `U19` non viene
  nemmeno abilitato per `$D1FF`.
- Tutti i GPIO dell'ESP32 sono assegnati (`PIN-MAPPING.md` §7): `~mVIRQ` non arriva all'ESP32, salvo
  un filo su GPIO0 (rete `BOOT0`, pin di strapping), che richiederebbe comunque un buffer tri-state
  separato per D7. Per questo il filo `~mVIRQ`→GPIO0 e l'opzione firmware `VERA_HAS_VIRQ_SENSE` sono
  stati **eliminati** (il documento `HW-MOD-GPIO0-VIRQ.md` non esiste più).

**Soluzione adottata: gancio software sul vettore IRQ.** I registri VERA sono sempre leggibili
(§2.5b). Un programma che usa gli IRQ della VERA aggancia `VIMIRQ` (`$0216`): legge `ISR` e `IEN`,
se `ISR & IEN` ha bit attivi conferma VSYNC/LINE/SPRCOL scrivendo 1 in `ISR` e maschera AFLOW in
`IEN`, altrimenti passa il controllo al gestore precedente. Serve solo lo stadio open-drain di §2.3 sulla
linea IRQ. L'OS **non** viene più usato per smistare l'IRQ: `PDIMSK` (`$0249`) resta a 0 e
`IRQVECTOR` della ROM PBI (`$D808`) non verrà chiamato.

Stato: **scritto e provato in emulatore**. Il gancio è in `VERA_ATARI_PBI/vera-tests/vera_irq.s`
(interfaccia C in `vera_irq.h`: `vera_irq_install`, `vera_irq_enable`, `vera_irq_disable`,
`vera_irq_take`, `vera_irq_set_line`, `vera_irq_set_callback`, `vera_irq_remove`). Il test
`TESTIRQ.COM` verifica VSYNC (circa 59,94 Hz anche con Atari PAL), LINE, il mascheramento di AFLOW,
la catena verso l'OS e la rimozione: 13 PASS, 0 FAIL in NTSC e in PAL. Sulla scheda reale va
provato dopo il montaggio dello stadio open-drain. Guida d'uso: `VERA_ATARI_PBI/Documentation/VERA-IRQ.md`.

### 2.5 [B] Scrittura `$D1FF`: solo il proprio bit — **corretto nel firmware**

Il latch di selezione deve usare solo **D7** (bit del device): con D7 = 1 la scheda si seleziona,
con D7 = 0 si deseleziona, qualunque sia il valore degli altri bit. L'emulatore si comporta
così (`byte & mask`) e ora anche `main.cpp` (`(data & PBI_DEV_ID) != 0`, prima `== 0x80`), sia in
modalità PBI sia CCTL.

### 2.5b [A] I registri VERA devono rispondere anche con il latch a 0 — **corretto nel firmware**

Il firmware asseriva `DEV_SEL_N` per `$D100-$D11F` **solo con la scheda selezionata** (latch
`$D1FF` = `0x80`). Ma l'OS deseleziona la scheda (`$D1FF` = 0) subito dopo l'`INIT`, e il driver
non la riseleziona mai: selezionarla mappa la ROM e disattiva il Math Pack (`MPD`), cosa che rompe
la virgola mobile del BASIC. Risultato: dopo il boot i registri VERA non sarebbero più
raggiungibili (il banner di boot compare perché l'`INIT` gira a scheda selezionata).

Ora `DEV_SEL_N` ed `EXTSEL_N` vengono asseriti per `$D100-$D11F` **sempre** (come
nell'emulatore e come presuppone il software); `MPD` e `EXTSEL_N` per `$D600-$DFFF` restano
legati alla selezione.

### 2.5c [A] Il log dei registri nel loop del bus faceva perdere cicli — **corretto nel firmware**

Per ogni accesso ai registri VERA il loop chiamava `log_send()` (`xQueueSend` + `esp_timer_get_time`,
circa 1 µs) mentre `DEV_SEL_N` era ancora asserito. Con un ciclo 6502 di 558 ns si poteva
superare la fine di PHI2: `DEV_SEL_N` restava basso nel ciclo successivo (accessi spuri alla
VERA con l'indirizzo sbagliato) oppure si perdeva il ciclo seguente. Ora il log dei registri è
compilato solo con `-DVERA_TRACE_REGS=1` (debug, mai in produzione); resta attivo il log dei
cambi di latch (rari).

### 2.6 [B] Header ROM PBI — **ROM allineata**

La ROM `vera_pbi_handler.rom` (2 KB, assemblata da `vera_pbi_handler.s`) ha l'header:
`$D803 = $80`, `$D80B = $91`, `$D80C = 'V'`, vettori `$D805` (SIO, restituisce C=0 = non
gestito) e `$D808` (IRQ). Il contenuto deve essere esattamente quello servito dalla scheda a
`$D800-$DFFF`. La copia in `firmware/MCU/6502/src/vera_pbi_handler.s` (+ `inc/vera_common.inc`) è stata
sostituita con l'handler corrente di `VERA_ATARI_PBI` e rigenerata con `make -C 6502`
(`vera_pbi_handler.bin`, `include/vera_pbi_handler.h`, `FPGA/pbi_rom_pkg.vhd`): il binario è identico
a `vera_pbi_handler.rom` di `VERA_ATARI_PBI`. Contiene il nuovo `IRQVECTOR` e l'attesa lunga di
`WAIT_VERA`.

---

## 3. Reset e configurazione FPGA

| # | Requisito | Stato nel firmware attuale |
|---|---|---|
| 1 | Tenere l'Atari in reset (`ARESET` basso) fino a CONFIG_DONE della VERA | **già così**: `ARESET`, `CRESET` bassi in `setup()`; `CRESET` alto, attesa `CDONE`, poi `ARESET` alto |
| 2 | Il blocco vale **solo al power-on** | la sequenza è eseguita una volta: **non** deve essere rieseguita se `CDONE` scende dopo una riconfigurazione (CTRL bit 7) |
| 3 | Ritardo dopo `CDONE` prima di rilasciare `ARESET` (~1 ms) | **fatto**: `delayMicroseconds(VERA_POST_CDONE_DELAY_US)`, default 1000 µs (la VERA ha un POR interno di 128 cicli di `clk25`, ~5 µs, più `reset_sync`) |
| 4 | `ARESET` open-drain con pull-up | il tasto RESET Atari deve continuare a funzionare; mai pilotare la linea in alto |
| 5 | Timeout se `CDONE` non arriva (oggi 5 s, solo log) | decidere: rilasciare comunque `ARESET`? Il software ha un timeout di ~0,7 s in `WAIT_VERA`: prosegue senza VERA ed emette **tre beep** dall'altoparlante della console (un colore sullo schermo ANTIC non resta: l'OS reimposta i colori dopo l'`INIT` PBI) |
| 6 | Scrittura di `$80` in CTRL (`$D105`) | **protezione consigliata**: far mascherare al firmware/glue il bit 7 delle scritture a `$D105`, perché la riconfigurazione distrugge VRAM e blocca il bus ~100 ms. In alternativa il software non deve mai scriverlo (i test già non lo fanno). **Non implementato nel firmware ESP32**: il dato è valido solo a metà di PHI2, quindi `DEV_SEL_N` andrebbe asserito in ritardo solo per `$D105`; ritirarlo dopo la lettura non basta, perché la VERA registra la scrittura alla fine di `bus_write` comunque. Senza hardware per misurarlo, un errore di temporizzazione farebbe perdere scritture legittime a CTRL (cambi di DCSEL): rischio peggiore del problema |

Durante una riconfigurazione il bus VERA non è pilotato: le letture danno valori casuali.
L'emulatore la simula con 100 ms di bus morto (`-verax16-config-ms`, 0 = RESET tenuto fino a
CDONE).

---

## 4. Livelli, alimentazioni e temporizzazioni

- **Livelli.** VERA, ESP32 e FPGA sono a 3,3 V; il bus Atari è a 5 V TTL. Tutti i segnali verso
  l'Atari passano da 74LVC4245. Controllare che le uscite 3,3 V rispettino VIH dei ricevitori
  sul bus (TTL ≥ 2,0 V) e che gli ingressi sul lato 5 V non superino i limiti dell'FPGA.
- **Alimentazioni.** Nella netlist `U16` e `U19` hanno `VCCA` (pin 1) a **5 V**, mentre
  `PIN-MAPPING.md` descrive il lato A come 3,3 V (ESP32). Le due descrizioni non coincidono:
  verificare il lato corretto per ogni chip (per `U16` e `U19` il lato A risulta quello
  dell'Atari).
- **Tempo di risposta in lettura.** In lettura la VERA risponde da registri e dati già pronti
  (prefetch): alla scheda basta il tempo di propagazione attraverso `U4/U3`, FPGA e `U19`
  (circa 30-50 ns stimati, da misurare). Per la ROM/RAM `$D600-$DFFF` servite dall'ESP32 il
  margine è molto più stretto (fetch di istruzioni: tutti i cicli): il firmware ha ~279 ns per
  ciclo, vedi `Vera_Module_Analisys.ITA.tex`.
- **Frequenza di quadro.** La VERA gira a 59,94 Hz fisso, asincrona rispetto al VBI Atari. Non
  è un problema hardware, ma il software non può assumere sincronismo fra i due.

---

## 5. Regole software da rispettare con l'hardware reale

Il driver e i test già le seguono, ma valgono per qualunque programma futuro:

1. **Mai** `inc`, `dec`, `asl`, `lsr`, `rol`, `ror` su `$D100-$D11F`: le istruzioni RMW fanno
   due accessi e duplicano l'evento (autoincremento due volte su `DATA0/DATA1`).
2. **Mai** indirizzamento indicizzato su `$D100-$D11F` (una dummy read al cambio di pagina
   colpisce `DATA0/DATA1`), né `sta abs,x` / `sta (zp),y` con base nella pagina `$D1`.
3. Non scrivere `$80` in `$D105` (riconfigurazione dell'FPGA).
4. Non leggere i registri FX: sono in sola scrittura (restituiscono i byte di identità del firmware, `'V',48,0,1` sulla 48.0.1).
5. Niente sincronismo supposto con il VBI Atari.
6. Gli IRQ della VERA si gestiscono agganciando `VIMIRQ` (`$0216`), non via `$D1FF`/`PDIMSK` (§2.4).
7. Dopo il reset Atari la VERA mantiene tutto lo stato: l'handler `INIT` ne riscrive solo una
   parte. Un programma che lascia FX o IEN attivi lascia lo stato anche al riavvio.

---

## 6. Piano di bring-up consigliato

1. **Senza Atari**: alimentare la scheda, verificare `CDONE`, la sequenza `CRESET`→`ARESET`
   (tempi) e i livelli sul bus con `ARESET` scollegato.
2. **Con l'Atari, scheda scollegata dal bus dati** (`U19` disabilitato): verificare che
   l'Atari parta normalmente con `ARESET` rilasciato dalla scheda.
3. **Con `U19` abilitato**: controllare con l'oscilloscopio che non ci sia contesa nelle letture
   di RAM/ROM (§2.1) e il margine di hold sulle scritture (§2.2).
4. **Rilevamento**: dal DOS, `vera_detect()` (CTRL=`$7E`, `$D109`=`'V'`, `$D10A`=47) via
   un programma minimo; poi `$D1FF`/ROM (`$D803=$80`, `$D80B=$91`).
5. **Test funzionali** in questo ordine: da `disk3-standalone.atr` `TESTFX.COM` (atteso
   **PASS: 36, FAIL: 0**, e la riga `VERA firmware 48.0.1`); da `disk2-veratests-*.atr` `TEST8.COM`, `TESTGS8.COM`, `TESTMAZ8.COM`,
   `TESTMTX8.COM` (ESC per uscire); da `disk3-standalone.atr` `TESTPLR.COM`; poi `RUNCPM.COM`
   (`disk1-runcpm.atr`) con FujiNet.
6. **IRQ** solo quando §2.3 (stadio open-drain) è montato: `TESTIRQ.COM` da `disk3-standalone.atr` (atteso PASS 13, FAIL 0).
7. Ogni anomalia va riprodotta in emulatore con `-verax16-config-ms` (0 e 100) per separare
   problemi software da problemi di scheda.

---

## 7. Punti aperti da decidere

- Architettura: la documentazione descrive **due** soluzioni per RAM/ROM PBI: servite
  dall'ESP32 (`PIN-MAPPING.md`, `firmware/MCU`) oppure dalla BRAM di un'FPGA di interfaccia
  (`firmware/FPGA`, `C6502_Interface.vhd`). Va stabilita quale è quella attuale e allineata la
  documentazione.
- Presenza o meno di una decodifica hardware (`addressdecoder.sch`: 74LVC138, `~dD1XX`,
  `~dROMSEL`, `~dRAMSEL`) accanto alla decodifica software dell'ESP32.
- Compatibilità ECI del 130XE: confermare che l'ECI porti `MPD`, `EXTSEL`, `IRQ` e `D1XX`, e che
  l'OS XE esegua la scansione PBI (`$D1FF`, `$D803`, `$D80B`) come l'OS XL.

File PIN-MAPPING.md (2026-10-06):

# Pin Mapping: VERA Module RBL-XE (ESP32-S3FN8)

Target MCU: **ESP32-S3FN8** — QFN56 package, 45 GPIOs, 8 MB in-package Quad SPI flash,
512 KB SRAM, dual-core Xtensa LX7 @ 240 MHz.

> **Documenti collegati:** requisiti e verifiche hardware emersi dal lavoro su driver ed emulatore
> in [`VERA-ATARI-HW-REQUIREMENTS.md`](VERA-ATARI-HW-REQUIREMENTS.md).
>
> **Nota sui riferimenti:** nella netlist (2026-09-01) `U6` è il transceiver Atari→scheda
> (PHI2, R/W, D1XX, S4, S5, CCTL, REFRESH) e `U16` quello scheda→Atari (EXTSEL, MPD, RESET,
> HALT, RD4, RD5, IRQ). Le versioni precedenti di questo file li avevano scambiati.

---

## ⚠ Critical Boot-Time Warnings

| GPIO | QFN56 pin | Signal | Risk |
|---|---|---|---|
| **GPIO 0** | 5 | BOOT0 | Strapping pin (boot mode) — **non è NC**: rete `BOOT0` con `R33` 4,7 kΩ → 3V3, pulsante `SW3`, `C61` 100 nF e `R54` 220 Ω verso `Q4` (auto-reset del programmatore). LOW al reset = modalità download. |
| **GPIO 3** | 8 | RAMBO\_EN | Strapping pin (JTAG source, no internal pull) — usato come **RAMbo hardware enable**: pull-up 10 kΩ → VCC = RAMbo presente; pull-down 10 kΩ → GND = assente. Letto una volta in `setup()`. |
| **GPIO 26–32** | 28, 30–35 | — | Hard-wired to in-package Quad SPI flash (FN8 variant). **Never connect externally**. |
| **GPIO 45** | 51 | A14 | Strapping pin (VDD_SPI select) — internal weak pull-down (~5 kΩ). Connesso ad A14 via 74LVC4245APW_118 U3. Al power-on il 6502 è in reset → A14 alta impedenza → U3 flotta → pull-down → **LOW → VDD_SPI da LDO interno (~1.8 V)**. Sicuro per variante FN8 (flash on-package). |
| **GPIO 46** | 52 | A15 | Strapping pin (ROM messages on UART0) — internal weak pull-down (~5 kΩ). Connesso ad A15 via 74LVC4245APW_118 U3. Stesso scenario di GPIO 45 → **LOW → messaggi ROM disabilitati** (corretto per produzione). |

> **JTAG pins reclaimed (GPIO 39–42):** il firmware chiama `gpio_reset_pin()` su GPIO 39, 40,
> 41, 42 per de-registrarli dal controller JTAG e utilizzarli come GPIO normali.

> **GPIO 19–20 (pin 25–26, USB D−/D+):** USB CDC disabilitato nel firmware
> (`ARDUINO_USB_CDC_ON_BOOT=0`). Questi pin sono usati come A7 e A8 sul bus indirizzi.

> **GPIO 15–16 (pin 21–22, XTAL\_32K\_P/N):** nessun quarzo da 32 kHz presente.
> Utilizzati come normali GPIO (A3 e A4 sul bus indirizzi).

---

## 1. Data Bus D0–D7  (bidirectional, Bank 0 bits 4–11)

Tutti via level shifter **74LVC4245APW_118 U19** (B side = Atari 5 V, A side = ESP32 3.3 V) —
unico canale realmente **bidirezionale** del progetto: la direzione (pin DIR) è commutata
dinamicamente da due invertitori **SN74HCT04DR U23**, pilotati da R/W\_ e PHI2, invece
dell'auto-sensing analogico del vecchio TXS0108E. Vedere § 6.

| Atari signal | GPIO | QFN56 pin | IO MUX | Bank-0 bit | Notes |
|---|---|---|---|---|---|
| D0 | 4  | 9  | GPIO4  | 4  | 60 µs LOW glitch al power-up |
| D1 | 5  | 10 | GPIO5  | 5  | |
| D2 | 6  | 11 | GPIO6  | 6  | |
| D3 | 7  | 12 | GPIO7  | 7  | |
| D4 | 8  | 13 | GPIO8  | 8  | |
| D5 | 9  | 14 | GPIO9  | 9  | |
| D6 | 10 | 15 | GPIO10 | 10 | |
| D7 | 11 | 16 | GPIO11 | 11 | |

Firmware bitmask: `DBUS_MASK = 0x00000FF0`
Firmware data decode: `data = (GPIO.in >> 4) & 0xFF`

---

## 2. Address Bus A0–A15

### A0–A7 (Bank 0, GPIO 12–19, via 74LVC4245APW_118 U4)

| Atari signal | GPIO | QFN56 pin | IO MUX | Bank-0 bit | Notes |
|---|---|---|---|---|---|
| A0 | 12 | 17 | GPIO12 | 12 | |
| A1 | 13 | 18 | GPIO13 | 13 | |
| A2 | 14 | 19 | GPIO14 | 14 | |
| A3 | 15 | 21 | XTAL\_32K\_P  | 15 | Pad RTC usato come GPIO; pin 20 = VDD3P3\_RTC |
| A4 | 16 | 22 | XTAL\_32K\_N  | 16 | Pad RTC usato come GPIO |
| A5 | 17 | 23 | GPIO17 | 17 | |
| A6 | 18 | 24 | GPIO18 | 18 | |
| A7 | 19 | 25 | USB\_D− | 19 | USB disabilitato; pin condiviso con USB D− |

### A8–A15 (Bank 0/1, GPIO 20–21, 35–36, 33–34, 45–46, via 74LVC4245APW_118 U3)

> **Hardware:** un solo chip **U3** (8 canali) copre l'intero bus indirizzi alto A8–A15,
> unificando quello che nella revisione TXS0108E era diviso su due package separati.
> GPIO 33/34 (pin 38–39) e GPIO 45/46 (pin 51–52) restano su lati opposti del QFN56.
> **Routing PCB:** applicare *length matching* — tutte le tracce di A12–A15 portate alla
> lunghezza della traccia più lunga (A14 o A15) tramite serpentine, per eliminare lo skew
> di propagazione tra i quattro bit.

| Atari signal | GPIO | QFN56 pin | IO MUX | Bank bit | Notes |
|---|---|---|---|---|---|
| A8  | 20 | 26 | USB\_D+ | Bank 0 bit 20 | USB disabilitato; pin condiviso con USB D+ |
| A9  | 21 | 27 | GPIO21  | Bank 0 bit 21 | |
| A10 | 35 | 40 | GPIO35  | Bank 1 bit 3  | |
| A11 | 36 | 41 | GPIO36  | Bank 1 bit 4  | |
| A12 | 33 | 38 | GPIO33  | Bank 1 bit 1  | Ex-spare CONN / libre |
| A13 | 34 | 39 | GPIO34  | Bank 1 bit 2  | Ex-spare CONN / libre |
| A14 | 45 | 51 | GPIO45  | Bank 1 bit 13 | Strapping pin (VDD_SPI); pull-down → LOW al boot (sicuro FN8) |
| A15 | 46 | 52 | GPIO46  | Bank 1 bit 14 | Strapping pin (ROM msgs); pull-down → LOW al boot (corretto) |

### Firmware: decode indirizzo completo (16 bit)

```c
/* decode_addr(g_lo, g_hi) — restituisce A0-A15 (16 bit): */
uint16_t a = (g_lo >> 12) & 0x3FF;               /* A0-A9  — Bank 0 bits 12-21 */
a |= ((g_hi >> (35 - 32)) & 1u) << 10;           /* A10    — Bank 1 bit  3     */
a |= ((g_hi >> (36 - 32)) & 1u) << 11;           /* A11    — Bank 1 bit  4     */
a |= ((g_hi >> (33 - 32)) & 1u) << 12;           /* A12    — Bank 1 bit  1     */
a |= ((g_hi >> (34 - 32)) & 1u) << 13;           /* A13    — Bank 1 bit  2     */
a |= ((g_hi >> (45 - 32)) & 1u) << 14;           /* A14    — Bank 1 bit 13     */
a |= ((g_hi >> (46 - 32)) & 1u) << 15;           /* A15    — Bank 1 bit 14     */
```

La modalità operativa è selezionata a compile time tramite `VERA_BOARD_IS_PBI` in `main.cpp`:

| `VERA_BOARD_IS_PBI` | Modalità | Range attivi | Latch selezione |
|---|---|---|---|
| `1` (default) | **PBI**  | $D100–$D1FF, $D600–$D7FF, $D800–$DFFF | write `0x80` → $D1FF |
| `0` | **CCTL** | $D500–$D5FF | write `0x80` → $D5FF |

```c
/* Confronti indirizzi — PBI mode (VERA_BOARD_IS_PBI = 1): */
/* VERA regs  $D100-$D11F   32 B  →  EXTSEL_N + DEV_SEL_N (se selezionato) */
/* PBI latch  $D1FF              →  write 0x80 = seleziona scheda           */
/* RAM        $D600-$D7FF  512 B  →  ram_pbi[addr & 0x1FF]  (ESP32 drive)   */
/* ROM        $D800-$DFFF 2048 B  →  pbi_driver[addr & 0x7FF] (ESP32 drive) */

/* Confronti indirizzi — CCTL mode (VERA_BOARD_IS_PBI = 0): */
/* CCTL range $D500-$D5FE       →  DEV_SEL_N (se selezionato, FPGA drive)  */
/* CCTL latch $D5FF             →  write 0x80 = seleziona scheda            */
```

---

## 3. Control Signals

Il firmware decodifica tutti gli indirizzi **interamente in software**: non esistono segnali
decodificati hardware (D1XX\_N, ROM\_SEL\_N, RAM\_SEL\_N) come ingressi ESP32.
L'ESP32 legge A0–A15, PHI2, R/W\_ ogni ciclo e asserisce i segnali di uscita di conseguenza
tramite il **Dedicated GPIO** (istruzioni TIE Xtensa `ee.get_gpio_in` / `ee.wr_mask_gpio_out`).
Con A0–A15 completi il decode è esatto: nessuna ambiguità di pagina.

> **Perché non i chip-select hardware:** sull'ESP32-S3FN8 non ci sono GPIO liberi da
> dedicare a ingressi per i chip-select hardware disponibili sui connettori Atari
> (`/D1XX`, `/S4`, `/S5`, `/CCTL` — vedere § 7, tutti i GPIO non riservati sono già
> assegnati). Inoltre l'emulazione RAMbo 256 KB richiede comunque di leggere l'intero
> bus indirizzi A0–A15 (per decodificare la finestra $4000–$7FFF) e di intercettare le
> scritture su PORTB ($D301), quindi anche con GPIO disponibili i chip-select hardware
> non risparmierebbero pin sul bus indirizzi: la decodifica software è l'unica strada.

La modalità operativa (PBI o CCTL) è selezionata a compile time con `VERA_BOARD_IS_PBI`
(vedere sezione 2). In PBI mode tutti e tre i segnali (EXTSEL\_N, DEV\_SEL\_N, MPD) sono
attivi; in CCTL mode solo DEV\_SEL\_N è usato. Il RAMbo 256 KB è abilitato a runtime
tramite `RAMBO_EN` (GPIO 3, vedere sezione 2).

| Signal | GPIO | QFN56 pin | IO MUX | Direction | Active | Level shift | Description |
|---|---|---|---|---|---|---|---|
| PHI2 | 1 | 6 | GPIO1 | Input | HIGH | via U6 | Clock fase 2 CPU 6502 — 1.79 MHz |
| R/W\_ | 2 | 7 | GPIO2 | Input | HIGH=read | via U6 | Read / Not-Write |
| RAMBO\_EN | 3 | 8 | GPIO3 | Input | HIGH | **direct** | RAMbo 256 KB enable — pull-up 10 kΩ→VCC = presente; pull-down 10 kΩ→GND = assente. Letto in `setup()`. |
| EXTSEL\_N | 41 | 47 | MTDI | **Output** | LOW | via U16 | Disabilita MMU/Freddie per $D1xx, $D6xx e finestra RAMbo $4000–$7FFF. **Solo PBI mode** per VERA; RAMbo in entrambe le modalità. Ex-JTAG, reclaimed. |
| DEV\_SEL\_N | 40 | 45 | MTDO | **Output** | LOW | **direct** | VERA chip select (3.3 V); PBI: VERA regs $D1xx; CCTL: range $D5xx. Ex-JTAG, reclaimed. |
| MPD | 42 | 48 | MTMS | **Output** | LOW | via U16 | Math Pack Disable — disabilita ROM Atari $D800–$DFFF — **solo PBI mode**. Ex-JTAG, reclaimed. |
| ARESET | 37 | 42 | GPIO37 | **Output** | LOW | via U16 | Atari System Reset — pilota /RESET bus Atari (open-drain + pull-up consigliati). |
| CRESET | 38 | 43 | GPIO38 | **Output** | LOW | **direct** | VERA FPGA Reset — 3.3 V, diretto al chip FPGA. |
| CDONE | 39 | 44 | MTCK | Input | HIGH | **direct** | VERA FPGA configured status — HIGH = configurazione completata. Ex-JTAG, reclaimed. |

### Dedicated GPIO — canali usati

| Pool | Ch | GPIO | QFN56 pin | Segnale |
|---|----|---|---|---|
| Input  | 0 | 1  | 6  | PHI2 |
| Output | 0 | 40 | 45 | DEV\_SEL\_N |
| Output | 1 | 41 | 47 | EXTSEL\_N |
| Output | 2 | 42 | 48 | MPD |

I pool input e output Dedicated GPIO sono **indipendenti** su ESP32-S3: il canale 0 in lettura
e il canale 0 in scrittura puntano a pin fisici diversi.

---

## 4. Debug / Programming

| Function | GPIO | QFN56 pin | IO MUX | Notes |
|---|---|---|---|---|
| UART TX | 43 | 49 | U0TXD | Serial debug output — UART0 hardware pin |
| UART RX | 44 | 50 | U0RXD | Serial debug input  — UART0 hardware pin |

---

## 5. Crystal Oscillator (40 MHz)

The ESP32-S3FN8 requires an external **40 MHz crystal** to generate the
internal PLL reference that drives the CPU at 240 MHz, the Flash interface,
and the UART baud-rate dividers. Without it the chip does not boot.
The pins are **dedicated analog** — not GPIO, not software-configurable.

| QFN56 pin | Signal  | Notes |
|---|---|---|
| 53 | XTAL\_N | Crystal − terminal (oscillator amplifier output) |
| 54 | XTAL\_P | Crystal + terminal (oscillator amplifier input)  |

### Schematic

```
           C1 (10 pF)
XTAL_P (54) ──┤├── GND
      │
    [X1  40 MHz]   ← Rs 0–33 Ω optional, in series with crystal
      │
XTAL_N (53) ──┤├── GND
           C2 (10 pF)
```

| Component | Value | Notes |
|---|---|---|
| X1 — crystal | 40 MHz, SMD 3225 or 2016 | ±10 ppm or better; note C\_L in datasheet |
| C1, C2 — load caps | 10 pF 0402 ±5 % | C\_ext = 2 × C\_L − C\_stray ; C\_stray ≈ 3–5 pF |
| Rs — series resistor | 0–33 Ω (optional) | Limits oscillator drive level; omit if crystal oscillates cleanly |

**PCB layout:**
- Keep XTAL\_P / XTAL\_N traces as short as possible (< 5 mm).
- Place C1 and C2 **at the chip pins**, not near the crystal body.
- Do not route other signals under or parallel to crystal traces.
- Solid ground plane under the entire crystal area.
- Keep away from PHI2 (1.79 MHz), the 240 MHz CPU clock distribution, and D0–D7.

---

## 6. Level Shifting (74LVC4245APW_118 + SN74HCT04DR)

I tre TXS0108E (auto-sensing, 8 canali ciascuno) sono stati sostituiti da **cinque
74LVC4245APW,118** (NXP, dual-supply octal bus transceiver, TSSOP-24, LCSC C6091) più
due unità di un **SN74HCT04DR** (hex inverter) usate solo per generare la direzione
dinamica del bus dati. A differenza del TXS0108E, il 74LVC4245 **non ha auto-sensing**:
richiede che DIR e ~OE\_ siano pilotati esplicitamente.

**Pinout 74LVC4245APW,118 (TSSOP-24):**

| Pin | Nome | Funzione |
|---|---|---|
| 1 | VCCA | Alimentazione lato A — 3.3 V (ESP32-S3) |
| 2 | DIR | Direzione: A→B oppure B→A a seconda del verso cablato |
| 3–10 | A0–A7 | Canali lato A (3.3 V) |
| 11, 12, 13 | GND | Massa |
| 14–21 | B7–B0 | Canali lato B (5 V, ordine invertito rispetto ad A0–A7) |
| 22 | ~OE\_ | Output enable, attivo basso |
| 23, 24 | VCCB | Alimentazione lato B — 5 V (Atari) |

100 nF ceramico su VCCA→GND e VCCB→GND per ciascun chip. Sui bus a **direzione fissa**
(indirizzi, metà dei segnali di controllo) DIR e ~OE\_ sono cablati staticamente al verso
corretto; sul bus dati **bidirezionale** (U19) DIR è invece pilotato dinamicamente.

### U4 — Address bus A0–A7 (fisso, 6502 → MCU)

| Canale | Lato A (3.3 V, ESP32-S3) | Lato B (5 V, Atari) |
|---|---|---|
| A0/B0 | GPIO 12 (pin 17) — A0 | Atari A0 |
| A1/B1 | GPIO 13 (pin 18) — A1 | Atari A1 |
| A2/B2 | GPIO 14 (pin 19) — A2 | Atari A2 |
| A3/B3 | GPIO 15 (pin 21) — A3 | Atari A3 |
| A4/B4 | GPIO 16 (pin 22) — A4 | Atari A4 |
| A5/B5 | GPIO 17 (pin 23) — A5 | Atari A5 |
| A6/B6 | GPIO 18 (pin 24) — A6 | Atari A6 |
| A7/B7 | GPIO 19 (pin 25) — A7 | Atari A7 (pin condiviso USB D−) |

### U3 — Address bus A8–A15 (fisso, 6502 → MCU)

> **Nota PCB:** tutte le tracce A12–A15 sono portate alla lunghezza della
> traccia più lunga (*length matching* con serpentine) per eliminare lo skew.
> Un solo package copre l'intero bus alto, a differenza della vecchia coppia
> di TXS0108E U3/U4.

| Canale | Lato A (3.3 V, ESP32-S3) | Lato B (5 V, Atari) |
|---|---|---|
| A0/B0 | GPIO 20 (pin 26) — A8  | Atari A8 (pin condiviso USB D+) |
| A1/B1 | GPIO 21 (pin 27) — A9  | Atari A9  |
| A2/B2 | GPIO 35 (pin 40) — A10 | Atari A10 |
| A3/B3 | GPIO 36 (pin 41) — A11 | Atari A11 |
| A4/B4 | GPIO 33 (pin 38) — A12 | Atari A12 |
| A5/B5 | GPIO 34 (pin 39) — A13 | Atari A13 |
| A6/B6 | GPIO 45 (pin 51) — A14 | Atari A14 |
| A7/B7 | GPIO 46 (pin 52) — A15 | Atari A15 |

### U6 — Control signals, 6502 → MCU (fisso, input)

| Canale | Lato A (3.3 V, ESP32-S3) | Lato B (5 V, Atari) | Note |
|---|---|---|---|
| — | GPIO 1 (pin 6) — PHI2 | Atari PHI2 | Clock fase 2, 1.79 MHz |
| — | GPIO 2 (pin 7) — R/W\_ | Atari R/W\_ | Read / Not-Write |
| — | — | D1XX\_N, S4\_N, S5\_N, CCTL\_N, REFRESH | Canali liberi, portati a test point — **non collegati a un GPIO in questo progetto** |

### U16 — Control signals, MCU → 6502 (fisso, output)

| Canale | Lato A (3.3 V, ESP32-S3) | Lato B (5 V, Atari) | Note |
|---|---|---|---|
| — | GPIO 41 (pin 47) — EXTSEL\_N | Atari EXTSEL | Output, active LOW |
| — | GPIO 42 (pin 48) — MPD | Atari ECI MPD | Output, active LOW |
| — | GPIO 37 (pin 42) — ARESET | Atari /RESET | Output, active LOW |
| — | — | RD4, RD5, HALT | Canali liberi, portati a test point — **non collegati a un GPIO in questo progetto** |
| — | `~mVIRQ` (FPGA, pin 18 lato 3,3 V) | Atari IRQ (`ECI1` pin B) | Uscita FPGA **push-pull** direttamente sul bus: da sostituire con uno stadio open-drain (74LVC1G07), vedere `VERA-ATARI-HW-REQUIREMENTS.md` §2.3 |

### U19 — Data bus D0–D7 (bidirezionale, direzione dinamica)

DIR è pilotato da due invertitori **SN74HCT04DR U23** a partire da R/W\_ e PHI2 (stessa
logica di un transceiver dati 6502 classico: direzione verso l'Atari durante i cicli di
lettura del 6502, verso l'ESP32 durante i cicli di scrittura), non più dall'auto-sensing
del TXS0108E.

> **`~OE_` (pin 22): da modificare.** Oggi è `NOT(PHI2)` (via `U23`), quindi `U19` pilota il bus Atari in
> ogni lettura, anche di memorie non della scheda. Deve diventare
> `~OE_ = NAND(PHI2, NAND(R/W, AND3(DEV_SEL_N, EXTSEL_N, MPD)))`: attivo in scrittura e nelle
> sole letture a cui la scheda risponde (non va collegato a `CDONE`). Dettaglio, parti e tempi in
> `VERA-ATARI-HW-REQUIREMENTS.md` §2.1. Nella netlist `VCCA` (pin 1) di `U19` è a 5 V: il lato "A" di
> questa tabella (3,3 V) e il lato "B" (5 V) vanno **verificati** sullo schema.

| Canale | Lato A (3.3 V, ESP32-S3) | Lato B (5 V, Atari) |
|---|---|---|
| A0/B0 | GPIO 4  (pin  9) — D0 | Atari D0 |
| A1/B1 | GPIO 5  (pin 10) — D1 | Atari D1 |
| A2/B2 | GPIO 6  (pin 11) — D2 | Atari D2 |
| A3/B3 | GPIO 7  (pin 12) — D3 | Atari D3 |
| A4/B4 | GPIO 8  (pin 13) — D4 | Atari D4 |
| A5/B5 | GPIO 9  (pin 14) — D5 | Atari D5 |
| A6/B6 | GPIO 10 (pin 15) — D6 | Atari D6 |
| A7/B7 | GPIO 11 (pin 16) — D7 | Atari D7 |

**Connessioni dirette (senza level shifter):**

| Signal | GPIO | QFN56 pin | Collegato a |
|---|---|---|---|
| DEV\_SEL\_N | 40 | 45 | VERA FPGA pin /CS (3.3 V) |
| CRESET | 38 | 43 | VERA FPGA pin /RESET (3.3 V) |
| CDONE | 39 | 44 | VERA FPGA pin CDONE (3.3 V) |

---

## 7. GPIO disponibili (ESP32-S3FN8 QFN56)

Pin non assegnati al progetto, esclusi strapping e flash in-package.

| GPIO | QFN56 pin | IO MUX | Note |
|---|---|---|---|
| 22–25 | — | — | Non esistono su ESP32-S3 |

> Tutti i GPIO non riservati sono ora assegnati: GPIO 3 = RAMBO\_EN; GPIO 33, 34, 45, 46 = A12–A15.

**Pin esclusi (non utilizzabili):**

| GPIO / Funzione | QFN56 pin | Motivo |
|---|---|---|
| GPIO 26–32 | 28, 30–35 | Flash in-package — mai connettere esternamente |
| XTAL\_N / XTAL\_P | 53, 54 | Dedicated analog — quarzo 40 MHz. Vedere § 5. |
| VDDA1 / VDDA2 | 55, 56 | Alimentazione analogica — non GPIO, non connettere a segnali digitali |

---

## 8. QFN56 — Pinout completo

Riferimento rapido ESP32-S3FN8 QFN56 (56 pin segnale + pad GND centrale).

| Pin | GPIO / Funzione | Uso in questo progetto |
|-----|---|---|
| 1 | GND | GND |
| 2 | 3V3 | 3.3 V |
| 3 | EN (CHIP\_EN) | Pull-up 10 kΩ a 3.3 V |
| 4 | — | (riservato / NC) |
| 5 | GPIO 0 | BOOT0 (pulsante BOOT / auto-reset, pull-up `R33`) — strapping |
| 6 | GPIO 1 | PHI2 input (via U6) |
| 7 | GPIO 2 | R/W\_ input (via U6) |
| 8 | GPIO 3 | RAMBO\_EN — pull-up 10 kΩ → VCC = RAMbo presente; pull-down 10 kΩ → GND = assente |
| 9 | GPIO 4 | D0 (via U19) |
| 10  | GPIO 5 | D1 (via U19) |
| 11  | GPIO 6 | D2 (via U19) |
| 12  | GPIO 7 | D3 (via U19) |
| 13  | GPIO 8 | D4 (via U19) |
| 14  | GPIO 9 | D5 (via U19) |
| 15  | GPIO 10 | D6 (via U19) |
| 16  | GPIO 11 | D7 (via U19) |
| 17  | GPIO 12 | A0 (via U4) |
| 18  | GPIO 13 | A1 (via U4) |
| 19  | GPIO 14 | A2 (via U4) |
| 20  | VDD3P3\_RTC | Alimentazione RTC — **non GPIO** |
| 21  | GPIO 15 / XTAL\_32K\_P | A3 (via U4) — nessun quarzo 32 kHz |
| 22  | GPIO 16 / XTAL\_32K\_N | A4 (via U4) — nessun quarzo 32 kHz |
| 23  | GPIO 17 | A5 (via U4) |
| 24  | GPIO 18 | A6 (via U4) |
| 25  | GPIO 19 / USB\_D− | A7 (via U4) — USB disabilitato |
| 26  | GPIO 20 / USB\_D+ | A8 (via U3) — USB disabilitato |
| 27  | GPIO 21 | A9 (via U3) |
| 28  | GPIO 26 (FLASH SPICS0) | **Flash in-package — NC esterno** |
| 29  | VDD\_SPI | Alimentazione flash — **non GPIO** |
| 30  | GPIO 27 (FLASH SPIQ)  | **Flash in-package — NC esterno** |
| 31  | GPIO 28 (FLASH SPIWP) | **Flash in-package — NC esterno** |
| 32  | GPIO 29 (FLASH SPICLK)| **Flash in-package — NC esterno** |
| 33  | GPIO 30 (FLASH SPID)  | **Flash in-package — NC esterno** |
| 34  | GPIO 31 (FLASH SPIHD) | **Flash in-package — NC esterno** |
| 35  | GPIO 32 (FLASH SPICS1)| **Flash in-package — NC esterno** |
| 36  | — | (riservato / NC) |
| 37  | — | (riservato / NC) |
| 38  | GPIO 33 | A12 (via U3) |
| 39  | GPIO 34 | A13 (via U3) |
| 40  | GPIO 35 | A10 (via U3) |
| 41  | GPIO 36 | A11 (via U3) |
| 42  | GPIO 37 | ARESET output (via U16) |
| 43  | GPIO 38 | CRESET output (diretto VERA) |
| 44  | GPIO 39 / MTCK | CDONE input (diretto VERA) — ex-JTAG |
| 45  | GPIO 40 / MTDO | DEV\_SEL\_N output (diretto VERA) — ex-JTAG |
| 46  | VDD3P3\_CPU | Alimentazione CPU — **non GPIO** |
| 47  | GPIO 41 / MTDI | EXTSEL\_N output (via U16) — ex-JTAG |
| 48  | GPIO 42 / MTMS | MPD output (via U16) — ex-JTAG |
| 49  | GPIO 43 / U0TXD | UART0 TX — debug seriale |
| 50  | GPIO 44 / U0RXD | UART0 RX — debug seriale |
| 51  | GPIO 45 | A14 (via U3) — strapping VDD\_SPI; pull-down → LOW al boot (FN8 safe) |
| 52  | GPIO 46 | A15 (via U3) — strapping ROM msgs; pull-down → LOW al boot |
| 53  | XTAL\_N | Quarzo principale 40 MHz — dedicated analog |
| 54  | XTAL\_P | Quarzo principale 40 MHz — dedicated analog |
| 55  | VDDA1 | Alimentazione analogica — non GPIO |
| 56  | VDDA2 | Alimentazione analogica — non GPIO |
| EP  | GND (pad centrale) | GND |

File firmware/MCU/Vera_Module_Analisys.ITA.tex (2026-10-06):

\documentclass[12pt, a4paper]{article}

% --- PACHETTI ---
\usepackage[utf8]{inputenc}
\usepackage[T1]{fontenc}
\usepackage{lmodern} % Font più moderno rispetto al default
\usepackage[italian]{babel}
\usepackage{geometry}
\usepackage{graphicx}
\usepackage{amsmath}
\usepackage{amssymb}
\usepackage{xcolor}
\usepackage{hyperref}
\usepackage{listings}
\usepackage{tikz}
\usepackage{tikz-timing}
\usepackage{verbatim} % Aggiunto per commentare blocchi
\usepackage{fancyvrb} % BVerbatim per ASCII art centrata
\usepackage{float}
\usepackage{booktabs}
\usepackage{array}

% --- CONFIGURAZIONE GEOMETRIA PAGINA ---
\geometry{a4paper, top=3cm, bottom=3cm, left=2.5cm, right=2.5cm}

% --- CONFIGURAZIONE HYPERREF ---
\hypersetup{
    colorlinks=true,
    linkcolor=blue!50!black,
    urlcolor=blue!80!black,
    citecolor=green!50!black,
    pdftitle={Analisi Progetto Vera-Module-RBL-XE},
    pdfauthor={RetroBit Lab},
}

% --- CONFIGURAZIONE TIKZ ---
\usetikzlibrary{shapes.geometric, arrows, positioning, chains, shapes.misc}

% --- CONFIGURAZIONE LISTINGS (per il codice) ---
\definecolor{codegreen}{rgb}{0,0.6,0}
\definecolor{codegray}{rgb}{0.5,0.5,0.5}
\definecolor{codepurple}{rgb}{0.58,0,0.82}
\definecolor{backcolour}{rgb}{0.98,0.98,0.98}

\lstdefinestyle{cppstyle}{
    backgroundcolor=\color{backcolour},
    commentstyle=\color{codegreen},
    keywordstyle=\color{magenta},
    numberstyle=\tiny\color{codegray},
    stringstyle=\color{codepurple},
    basicstyle=\footnotesize\ttfamily,
    breakatwhitespace=false,
    breaklines=true,
    captionpos=b,
    keepspaces=true,
    numbers=left,
    numbersep=5pt,
    showspaces=false,
    showstringspaces=false,
    showtabs=false,
    tabsize=2,
    language=C++
}

% --- TITOLO ---
\title{
    \vspace{2cm}
    \hrule
    \vspace{0.5cm}
    {\Huge \bfseries Analisi Tecnica del Firmware}\\
    \vspace{0.2cm}
    {\Large Progetto \textit{Vera-Module-RBL-XE}}\\
    \vspace{0.5cm}
    \hrule
}
\author{Analisi del progetto a cura di RetroBit Lab}
\date{\today}

% --- INIZIO DOCUMENTO ---
\begin{document}

\maketitle
\thispagestyle{empty}

\newpage
\tableofcontents
\thispagestyle{empty}

\newpage
\setcounter{page}{1}

% --- SEZIONE 1: INTRODUZIONE ---
\section{Introduzione}
Questo documento presenta un'analisi tecnica del firmware per il progetto \textit{Vera-Module-RBL-XE}. L'obiettivo del firmware, eseguito su un microcontrollore ESP32, è di interfacciarsi con il bus di un processore 6502 per emulare un dispositivo PBI (Parallel Bus Interface) o CCTL (Cartridge Control Line) per computer ATARI della serie XL/XE.

Il progetto supporta la MCU target ESP32-S3 e due modalità operative, per un totale di due varianti di compilazione distinte. L'analisi si concentra sulla fattibilità temporale (timing) dell'interazione tra la MCU moderna e la CPU vintage, illustrando la logica di funzionamento tramite diagrammi di flusso e temporali.

% --- SEZIONE 2: ARCHITETTURA DEL SISTEMA ---
\section{Architettura del Sistema}
Il sistema si basa sull'interazione di due componenti principali.

\subsection{Componenti Chiave}
\begin{itemize}
    \item {\bfseries CPU 6502 (MOS/SALLY):} Il processore centrale dell'Atari, operante a una frequenza di clock di \textbf{1.7897 MHz} (NTSC).
    \item {\bfseries MCU:} Il microcontrollore moderno responsabile del monitoraggio del bus e dell'emulazione della periferica. Il target è:
    \begin{itemize}
        \item \textbf{ESP32-S3FN8} (QFN56, 7$\times$7\,mm) — Dual-core Xtensa LX7 @ 240\,MHz, 512\,KB SRAM, 8\,MB flash in-package Quad SPI, 45 GPIO bidirezionali.
    \end{itemize}
\end{itemize}

\subsection{Modalità operative (VERA\_BOARD\_IS\_PBI)}
Il firmware supporta due modalità operative, selezionate a compile-time tramite la macro \texttt{VERA\_BOARD\_IS\_PBI} in \texttt{main.cpp}:

\begin{itemize}
    \item \textbf{PBI mode (\texttt{VERA\_BOARD\_IS\_PBI=1}, default):} Il modulo si collega al connettore ECI della serie XL/XE.
    \begin{itemize}
        \item \textbf{VCS latch (\$D1FF):} in scrittura il dispositivo usa solo il \emph{proprio} bit dati (D7): D7\,=\,1 seleziona, D7\,=\,0 deseleziona (\texttt{data \& 0x80}). In lettura \$D1FF non è pilotato: l'identificazione dell'IRQ via \$D1FF non è realizzabile con \texttt{U19} (vedere sezione~\ref{sec:hwverif}).
        \item \textbf{ROM \$D800--\$DFFF (2\,KB, 11 bit A0--A10):} \texttt{MPD} (Math Pack Disable, GPIO42) viene asserito basso per ogni ciclo ROM con device selezionato, disabilitando la ROM Math Pack interna all'Atari.
        \item \textbf{RAM \$D600--\$D7FF (512\,B, 9 bit A0--A8):} buffer IRAM esposto al 6502. \texttt{EXTSEL\_N} viene asserito per-ciclo.
        \item \textbf{Registri VERA \$D100--\$D11F} (32 registri): \texttt{DEV\_SEL\_N} e \texttt{EXTSEL\_N} affermati \emph{sempre}, indipendentemente dal latch; la FPGA VERA guida il bus dati. L'OS deseleziona la scheda (\$D1FF\,=\,0) subito dopo l'\texttt{INIT} e il driver non la riseleziona mai (selezionarla mapperebbe la ROM e disattiverebbe il Math Pack, rompendo la virgola mobile del BASIC): i registri devono quindi restare raggiungibili con il latch a 0.
        \item \textbf{Intervallo \$D120--\$D1FE}: \texttt{EXTSEL\_N} asserito solo con scheda selezionata; nessun dato guidato dall'ESP32 (non implementato nel firmware corrente).
        \item \textbf{EXTSEL\_N (GPIO41):} segnale \emph{per-ciclo} che disabilita MMU/Freddie dell'Atari per accessi D1xx e D6xx. Non è un segnale persistente.
    \end{itemize}
    \item \textbf{CCTL mode (\texttt{VERA\_BOARD\_IS\_PBI=0}):} Il modulo si collega alla porta cartuccia. Il firmware decodifica l'indirizzo completo a 16\,bit e intercetta \$D500--\$D5FF: \texttt{DEV\_SEL\_N} affermato per \$D500--\$D5FE (FPGA guida il bus dati), latch di selezione a \$D5FF (scrittura di \$80 seleziona la scheda).
\end{itemize}

\subsection{Ambiente di build PlatformIO}
Il file \texttt{platformio.ini} definisce tre ambienti:

\begin{center}
\begin{tabular}{lll}
\toprule
\textbf{Ambiente} & \textbf{Modalità} & \textbf{Note} \\
\midrule
\texttt{esp32s3fn8}      & PBI (\$D1FF)  & produzione, scheda senza modifiche \\
\texttt{esp32s3fn8-cctl} & CCTL (\$D5FF) & slot cartuccia \\
\bottomrule
\end{tabular}
\end{center}

Opzioni di compilazione (\texttt{-D}):

\begin{center}
\begin{tabular}{lcp{8cm}}
\toprule
\textbf{Macro} & \textbf{Default} & \textbf{Effetto} \\
\midrule
\texttt{VERA\_BOARD\_IS\_PBI}  & 1 & 1 = PBI, 0 = CCTL (impostata dall'ambiente) \\
\texttt{VERA\_TRACE\_REGS}     & 0 & log di ogni accesso ai registri VERA. \textbf{Solo debug}: costa $\approx$1\,\textmu s nel loop del bus (un ciclo 6502 dura 559\,ns) e può lasciare \texttt{DEV\_SEL\_N} asserito nel ciclo successivo con accessi spuri alla VERA \\
\bottomrule
\end{tabular}
\end{center}

\subsection{Interfacciamento Bus}
L'ESP32 legge il bus indirizzi completo \textbf{A0--A15} e i segnali \texttt{PHI2} e \texttt{R/W\_} direttamente dai propri GPIO ad ogni ciclo di clock. \textbf{Non esiste alcuna logica esterna di pre-decodifica degli indirizzi}: i segnali \texttt{D1XX\_N}, \texttt{ROM\_SEL\_N} e \texttt{RAM\_SEL\_N} del progetto precedente sono stati eliminati. La decodifica è interamente software in \texttt{decode\_addr()}, che restituisce un indirizzo a 16\,bit senza ambiguità di pagina.

\begin{sloppypar}
L'adattamento di livello 5\,V\,$\leftrightarrow$\,3.3\,V è affidato a cinque \textbf{74LVC4245} (lato A = Atari 5\,V, lato B = scheda 3.3\,V; direzione cablata, tranne \texttt{U19}) e a due porte \textbf{SN74HCT04} (\texttt{U23}). I TXS0108E delle revisioni precedenti sono stati eliminati (il 74LVC4245 non ha auto-sensing). Riferimenti secondo la netlist del 2026-09-01; dettaglio in \texttt{PIN-MAPPING.md}:
\end{sloppypar}

\begin{itemize}
    \item {\bfseries U19 — Bus Dati D0--D7 (GPIO\,4--11):} bidirezionale. \texttt{DIR} = NOT R/W\_ e \texttt{\textasciitilde OE\_} = NOT PHI2, entrambi tramite \texttt{U23}. Il firmware abilita le uscite ESP32 con \texttt{GPIO.enable\_w1ts} solo nei cicli che richiedono risposta dell'ESP32 (ROM \$D800--\$DFFF, RAM \$D600--\$D7FF, RAMbo \$4000--\$7FFF). \textbf{\texttt{\textasciitilde OE\_} oggi è NOT(PHI2) e va sostituito con il gating di sezione~\ref{sec:hwverif}.}
    \item {\bfseries U4 — Bus Indirizzi A0--A7 (GPIO\,12--19):} ingressi Atari$\rightarrow$ESP32. GPIO\,19 condivide il pad USB D-; USB CDC è disabilitato nel firmware.
    \item {\bfseries U3 — Bus Indirizzi A8--A15 (GPIO\,20--21, 35--36, 33--34, 45--46):} ingressi. Applicare \emph{length matching} (serpentine alla traccia più lunga) ad A12--A15; GPIO\,33--34 e GPIO\,45--46 sono su lati opposti del QFN56.
    \item {\bfseries U6 — PHI2, R/W\_ (GPIO\,1, 2), più D1XX, S4, S5, CCTL, REFRESH:} ingressi Atari$\rightarrow$scheda. I cinque segnali pre-decodificati sono portati a test point e \emph{non} collegati a GPIO.
    \item {\bfseries U16 — EXTSEL\_N, MPD, ARESET (GPIO\,41, 42, 37), \texttt{\textasciitilde mVIRQ} della FPGA, più HALT, RD4, RD5:} uscite scheda$\rightarrow$Atari. HALT, RD4 e RD5 sono a test point. \textbf{L'IRQ della VERA è attualmente un'uscita push-pull sul bus} (vedere sezione~\ref{sec:hwverif}). I GPIO\,39--42 erano riservati a JTAG: \texttt{setup()} li de-registra con \texttt{gpio\_reset\_pin()} prima di creare il Dedicated GPIO bundle.
    \item {\bfseries U5 (74HC00) — strobe VERA:} \texttt{\textasciitilde mRE} = NAND(PHI2, R/W\_), \texttt{\textasciitilde mWE} = NAND(PHI2, NOT R/W\_) verso la FPGA VERA, che richiede RD\_n e WR\_n distinti.
    \item {\bfseries Connessioni dirette (senza level shifter, 3.3\,V):} \texttt{DEV\_SEL\_N} (GPIO\,40) $\rightarrow$ \texttt{\textasciitilde mVCS0} (VERA /CS); \texttt{CRESET} (GPIO\,38) $\rightarrow$ reset VERA; \texttt{CDONE} (GPIO\,39) $\leftarrow$ VERA CDONE.
\end{itemize}

I segnali \texttt{DEV\_SEL\_N}, \texttt{EXTSEL\_N} e \texttt{MPD} sono raggruppati nel \textbf{Dedicated GPIO output bundle} (Core 1, canali 0--2): vengono asseriti e de-asseriti in un'unica istruzione TIE Xtensa (\texttt{ee.wr\_mask\_gpio\_out}, $\approx$1\,ciclo CPU), anziché con tre scritture APB separate ($\approx$18\,cicli totali). Il segnale \texttt{PHI2} è nel bundle di ingresso (canale 0): il polling avviene via \texttt{ee.get\_gpio\_in} (1\,ciclo CPU).

% --- SEZIONE 3: MAPPING DEI PIN ---
\section{Mapping dei Pin (ESP32-S3FN8, QFN56)}

I pin fisici del package QFN56 sono numerati 1--56 (più il pad GND centrale). La tabella seguente riporta i segnali del progetto con il numero GPIO logico \textbf{e} il numero di pad fisico del QFN56 (da Table~2-1 del datasheet ESP32-S3 v2.2).

\textbf{Nota importante:} il MCU \emph{richiede} un \textbf{quarzo esterno a 40\,MHz} collegato ai pin dedicati analogici \textbf{XTAL\_P} (pin\,54) e \textbf{XTAL\_N} (pin\,53). L'oscillatore RC interno è limitato al dominio RTC e non è in grado di pilotare il PLL della CPU a 240\,MHz; senza quarzo il chip non si avvia. Vedere la sezione~\ref{sec:xtal} per il circuito consigliato.

\begin{center}
\resizebox{\linewidth}{!}{%
\begin{tabular}{lcclll}
\toprule
\textbf{Segnale} & \textbf{GPIO} & \textbf{Pin QFN56} & \textbf{IO MUX} & \textbf{Dir.} & \textbf{Note} \\
\midrule
\multicolumn{6}{l}{\textit{Bus dati D0--D7 — bidirezionale via 74LVC4245 U19 (Bank-0 bit 4--11)}} \\
D0 & 4  &  9 & GPIO4  & I/O & glitch LOW 60\,µs al power-up \\
D1 & 5  & 10 & GPIO5  & I/O & \\
D2 & 6  & 11 & GPIO6  & I/O & \\
D3 & 7  & 12 & GPIO7  & I/O & \\
D4 & 8  & 13 & GPIO8  & I/O & \\
D5 & 9  & 14 & GPIO9  & I/O & \\
D6 & 10 & 15 & GPIO10 & I/O & \\
D7 & 11 & 16 & GPIO11 & I/O & \\
\midrule
\multicolumn{6}{l}{\textit{Bus indirizzi A0--A7 — input via 74LVC4245 U4 (Bank-0 bit 12--19)}} \\
A0 & 12 & 17 & GPIO12       & IN & \\
A1 & 13 & 18 & GPIO13       & IN & \\
A2 & 14 & 19 & GPIO14       & IN & \\
A3 & 15 & 21 & XTAL\_32K\_P & IN & pad RTC usato come GPIO; pin\,20 = VDD3P3\_RTC \\
A4 & 16 & 22 & XTAL\_32K\_N & IN & pad RTC usato come GPIO \\
A5 & 17 & 23 & GPIO17       & IN & \\
A6 & 18 & 24 & GPIO18       & IN & \\
A7 & 19 & 25 & USB\_D$-$    & IN & USB CDC disabilitato \\
\midrule
\multicolumn{6}{l}{\textit{Bus indirizzi A8--A11 (U3) e controllo (U6: PHI2, R/W\_; U16: EXTSEL\_N, MPD, ARESET)}} \\
A8  & 20 & 26 & USB\_D$+$ & IN  & USB CDC disabilitato \\
A9  & 21 & 27 & GPIO21    & IN  & \\
A10 & 35 & 40 & GPIO35    & IN  & Bank-1 bit\,3 \\
A11 & 36 & 41 & GPIO36    & IN  & Bank-1 bit\,4 \\
PHI2     &  1 &  6 & GPIO1  & IN  & Dedicated GPIO input ch\,0; 1.79\,MHz \\
R/W\_    &  2 &  7 & GPIO2  & IN  & HIGH = lettura \\
EXTSEL\_N & 41 & 47 & MTDI  & OUT & Dedicated GPIO output ch\,1; ex-JTAG, reclaimed \\
MPD       & 42 & 48 & MTMS  & OUT & Dedicated GPIO output ch\,2; ex-JTAG, reclaimed \\
ARESET   & 37 & 42 & GPIO37 & OUT & Reset sistema Atari (LOW asserito) \\
\midrule
\multicolumn{6}{l}{\textit{Bus indirizzi A12--A15 — input via 74LVC4245 U3 (Bank-1)}} \\
A12 & 33 & 38 & GPIO33  & IN & Bank-1 bit\,1; length matching con A13--A15 \\
A13 & 34 & 39 & GPIO34  & IN & Bank-1 bit\,2 \\
A14 & 45 & 51 & GPIO45  & IN & Bank-1 bit\,13; pin di strapping, usato come A14 \\
A15 & 46 & 52 & GPIO46  & IN & Bank-1 bit\,14; pin di strapping, usato come A15 \\
\midrule
\multicolumn{6}{l}{\textit{Segnali diretti (senza level shifter, 3.3\,V)}} \\
DEV\_SEL\_N & 40 & 45 & MTDO  & OUT & VERA /CS; Dedicated GPIO output ch\,0; ex-JTAG \\
CRESET     & 38 & 43 & GPIO38 & OUT & VERA /RESET \\
CDONE      & 39 & 44 & MTCK  & IN  & VERA configurata (HIGH = OK); ex-JTAG \\
RAMBO\_EN  &  3 &  8 & GPIO3  & IN  & RAMbo enable: pull-up 10\,k$\Omega$→VCC = presente \\
BOOT0 & 0 & 5 & GPIO0 & IN & pulsante BOOT / auto-reset (rete \texttt{BOOT0}); non usato dal firmware \\
\midrule
\multicolumn{6}{l}{\textit{Debug}} \\
UART TX & 43 & 49 & U0TXD & OUT & Serial debug @ 115200 baud \\
UART RX & 44 & 50 & U0RXD & IN  & non utilizzato in firmware \\
\bottomrule
\end{tabular}%
}
\end{center}

\subsection*{Decodifica indirizzo (16 bit)}

\texttt{decode\_addr()} restituisce l'indirizzo completo A0--A15 (16\,bit), catturato in due letture APB (\texttt{GPIO.in} per A0--A9 e \texttt{GPIO.in1.val} per A10--A15) già eseguite per il campionamento di PHI2. Le maschere di accesso ai buffer IRAM sono:
\[
\text{ROM } \$\text{D800--\$DFFF}: \quad \texttt{pbi\_driver[addr \& 0x7FF]} \quad (2048\,\text{B},\; 11\,\text{bit A0--A10})
\]
\[
\text{RAM } \$\text{D600--\$D7FF}: \quad \texttt{ram\_pbi[addr \& 0x1FF]} \quad (512\,\text{B},\; 9\,\text{bit A0--A8})
\]
\begin{multline*}
\text{RAMbo } \$\text{4000--\$7FFF}: \\
\quad\texttt{extended\_rambo\_256k[(bank} \ll 14) \mid \text{(addr \& 0x3FFF)]}
\quad (256\,\text{KB},\; 16\,\text{banchi})
\end{multline*}

\subsection*{GPIO disponibili}

Con A12--A15 aggiunti e \texttt{RAMBO\_EN} (GPIO\,3), tutti i GPIO utilizzabili sono ora assegnati. Non rimangono GPIO liberi per usi futuri.

\noindent\textbf{Attenzione:} I pin QFN56 28 e 30--35 (GPIO\,26--32) sono collegati internamente alla flash Quad SPI in-package (variante FN8) e non devono mai essere connessi esternamente. GPIO\,45 (pin\,51) e GPIO\,46 (pin\,52) sono pin di strapping del chip: vengono usati come ingressi A14 e A15 (vedere sezione~\ref{sec:strapping}). I pin\,53 (\texttt{XTAL\_N}) e\,54 (\texttt{XTAL\_P}) sono pad analogici dedicati al quarzo 40\,MHz: riservati, non usabili come GPIO (vedere sezione~\ref{sec:xtal}).

\subsection{Pin di strapping — comportamento al boot con bus ATARI connesso}
\label{sec:strapping}

L'ESP32-S3 campiona quattro pin di strapping durante la finestra di reset al power-on,
\emph{prima che qualsiasi codice venga eseguito}. I livelli campionati configurano la
modalità di boot e alcune opzioni di sistema.

\paragraph{Considerazione temporale critica.}
\texttt{PIN\_ARESET} (GPIO\,37) viene configurato come \texttt{OUTPUT} soltanto all'interno
di \texttt{setup()}. Al momento del campionamento dei pin di strapping GPIO\,37 è ancora
in alta impedenza: l'ESP32 \textbf{non ha ancora asserito} la linea di reset dell'Atari.
È la circuiteria di power-on reset dell'Atari stessa (rete RC di MMU/POKEY) che mantiene
il pin \texttt{RESET\#} del 6502 basso, mettendo il bus indirizzi in alta impedenza.
I transceiver 74LVC4245, con gli ingressi lato Atari flottanti, \emph{non} garantiscono
uscite in alta impedenza (non hanno auto-sensing né bus-hold): per A14 e A15 il livello
campionato dipende dal pull-down interno dell'ESP32 contro un nodo non pilotato.
\textbf{Da verificare sulla scheda}; se necessario aggiungere un pull-down da 10\,k$\Omega$
lato ESP32 su GPIO\,45 e GPIO\,46.

\begin{itemize}

  \item \textbf{GPIO\,0 — Pin\,5 \quad|\quad Boot mode \quad|\quad Pull-UP interno
        $\approx$45\,k$\Omega$}\\
    Rete \texttt{BOOT0}: \texttt{R33} 4.7\,k$\Omega$ verso 3V3, pulsante \texttt{SW3}, \texttt{C61}
    100\,nF e \texttt{R54} 220\,$\Omega$ verso \texttt{Q4} (auto-reset del programmatore).
    Non connesso al bus ATARI. Il pull-up mantiene GPIO\,0 HIGH per tutta la
    finestra di campionamento.
    Valore campionato: \textbf{HIGH $\rightarrow$ SPI boot dalla flash integrata}
    (comportamento corretto per il normale funzionamento).
    Il valore LOW avvierebbe la modalità download UART/JTAG, bloccando il sistema.

  \item \textbf{GPIO\,3 — Pin\,8 \quad|\quad JTAG source \quad|\quad Nessun pull interno
        (floating)}\\
    Connesso a \texttt{RAMBO\_EN} tramite resistore esterno 10\,k$\Omega$ verso VCC o GND.
    Il resistore esterno determina il livello prima del campionamento:
    \begin{itemize}
      \item Pull-up (RAMbo presente) $\rightarrow$ \textbf{HIGH} $\rightarrow$ sorgente JTAG
        hardware selezionata (GPIO\,39--42). \emph{Ininfluente:} \texttt{gpio\_reset\_pin()}
        reclaima tutti i pin JTAG in \texttt{setup()} prima della creazione del bundle
        Dedicated GPIO.
      \item Pull-down (RAMbo assente) $\rightarrow$ \textbf{LOW} $\rightarrow$ JTAG via USB
        OTG. \emph{Ininfluente:} \texttt{ARDUINO\_USB\_CDC\_ON\_BOOT=0} disabilita USB CDC;
        GPIO\,19/20 sono riassegnati ad A7/A8.
    \end{itemize}
    Senza il resistore esterno il pin flotta e il valore campionato è indeterminato:
    il resistore da 10\,k$\Omega$ è \textbf{obbligatorio} per un boot deterministico.

  \item \textbf{GPIO\,45 — Pin\,51 \quad|\quad VDD\_SPI voltage \quad|\quad Pull-DOWN
        interno $\approx$5\,k$\Omega$}\\
    Connesso al bit A14 del bus indirizzi ATARI tramite 74LVC4245 U3
    (5\,V\,$\leftrightarrow$\,3.3\,V). Al power-on il \texttt{RESET\#} del 6502 è basso
    $\rightarrow$ il pin A14 lato Atari è in alta impedenza; l'uscita lato ESP32 di U3
    non è pilotata in modo garantito (vedere sopra) e il pull-down interno porta
    GPIO\,45 a LOW.\\
    Valore campionato: \textbf{LOW $\rightarrow$ VDD\_SPI alimentato dal LDO interno
    ($\approx$1.8\,V)}.
    Per la variante FN8 (flash integrata on-package) il rail VDD\_SPI è instradato
    internamente e indipendente dallo strapping; entrambi i valori LOW e HIGH sono
    elettricamente sicuri. Il pull-down è coerente con lo stato idle del bus.\,$\checkmark$

    \noindent\textbf{Rischio residuo:} se un accoppiamento parassita o una salita
    particolarmente rapida del rail 5\,V Atari porta A14 HIGH durante la finestra di
    campionamento, il risultato è VDD\_SPI = 3.3\,V (VDD3P3\_RTC) — anch'esso sicuro
    per FN8.

  \item \textbf{GPIO\,46 — Pin\,52 \quad|\quad ROM messages (UART0) \quad|\quad Pull-DOWN
        interno $\approx$5\,k$\Omega$}\\
    Connesso al bit A15 del bus indirizzi ATARI tramite 74LVC4245 U3. Scenario di
    power-on identico a GPIO\,45: 6502 in reset $\rightarrow$ A15 alta impedenza
    $\rightarrow$ ingresso U3 non pilotato $\rightarrow$ pull-down $\rightarrow$ GPIO\,46 LOW.\\
    Valore campionato: \textbf{LOW $\rightarrow$ messaggi ROM del primo stage su UART0
    disabilitati}. Corretto per la produzione: il firmware inizializza UART0 autonomamente
    tramite \texttt{Serial.begin()} e lo usa esclusivamente per l'output di debug.
    L'abilitazione dei messaggi ROM (HIGH) aggiungerebbe righe di log Espressif prima
    dell'output del firmware — indesiderato ma non dannoso.\,$\checkmark$

\end{itemize}

\subsection{Quarzo oscillatore 40\,MHz (pin\,53--54)}
\label{sec:xtal}

L'ESP32-S3FN8 richiede un quarzo esterno da \textbf{40\,MHz} per generare il riferimento PLL interno che alimenta la CPU a 240\,MHz, l'interfaccia flash e i divisori UART. I pin sono \emph{analogici dedicati}: non configurabili via software, non condivisi con GPIO.

\begin{center}
\begin{tabular}{ccp{8cm}}
\toprule
\textbf{Pin QFN56} & \textbf{Segnale} & \textbf{Note} \\
\midrule
53 & \texttt{XTAL\_N} & Terminale negativo del cristallo (uscita amplificatore oscillatore) \\
54 & \texttt{XTAL\_P} & Terminale positivo del cristallo (ingresso amplificatore oscillatore) \\
\bottomrule
\end{tabular}
\end{center}

\noindent Schema consigliato:
\begin{center}
\begin{BVerbatim}
XTAL_P (54) --[C1 10pF]-- GND
     |
  [X1 40MHz]    <- Rs 0-33 Ohm in serie (opzionale)
     |
XTAL_N (53) --[C2 10pF]-- GND
\end{BVerbatim}
\end{center}

\begin{center}
\resizebox{\linewidth}{!}{%
\begin{tabular}{lll}
\toprule
\textbf{Componente} & \textbf{Valore} & \textbf{Note} \\
\midrule
X1 -- quarzo & 40\,MHz, SMD 3225 o 2016 & $\pm$10\,ppm; verificare $C_L$ dal datasheet \\
C1, C2 -- condensatori di carico & 10\,pF, 0402, $\pm$5\,\% & $C_{ext}=2C_L - C_{stray}$;\; $C_{stray}\approx 3$--5\,pF \\
Rs -- resistenza serie & 0--33\,$\Omega$ (opzionale) & Limita il drive dell'oscillatore \\
\bottomrule
\end{tabular}%
}
\end{center}

\noindent\textbf{Regole di layout PCB:} tracce XTAL\_P/N più corte possibile ($<$5\,mm); condensatori di carico posizionati ai pad del chip, non al corpo del quarzo; piano di massa solido sotto l'area del quarzo; isolamento dalle tracce PHI2, clock CPU 240\,MHz e bus dati D0--D7.

% --- SEZIONE 4: ANALISI DELLE TEMPISTICHE ---
\section{Analisi delle Tempistiche}
Una delle principali preoccupazioni in un progetto di questo tipo è la capacità della MCU di rispondere entro la finestra temporale definita dal ciclo di clock della CPU 6502.

\begin{itemize}
    \item {\bfseries Ciclo Clock 6502 (1.7897 MHz, NTSC):} $T_{6502} = 1 / (1.7897 \times 10^6) \approx 559\,\text{ns}$
    \item {\bfseries Finestra PHI2 alto (half-cycle):} $T_{PHI2\uparrow} \approx 279\,\text{ns}$ — questa è la finestra critica entro cui l'ESP32 deve leggere l'indirizzo, decodificarlo ed eventualmente pilotare il bus dati.
    \item {\bfseries Ciclo Clock ESP32 (240 MHz):} $T_{ESP32} = 1 / (240 \times 10^6) \approx 4.17\,\text{ns}$
\end{itemize}

Il rapporto tra la finestra critica e il ciclo dell'ESP32 è:
\[
\frac{T_{PHI2\uparrow}}{T_{ESP32}} = \frac{279\,\text{ns}}{4.17\,\text{ns}} \approx 67\,\text{cicli ESP32}
\]

Anche considerando solo la semi-finestra di PHI2 alto (il caso peggiore), l'ESP32-S3 dispone di circa \textbf{67 cicli di clock} per completare tutta la catena: lettura di \texttt{GPIO.in} / \texttt{GPIO.in1.val}, decodifica dell'indirizzo, lookup nella LUT, pilotaggio del bus dati. Poiché tutte le funzioni critiche risiedono in IRAM (\texttt{IRAM\_ATTR}) ed operano solo su registri hardware, il percorso critico è tipicamente inferiore a 20 cicli.

\subsection{Accesso diretto ai registri GPIO}
Per eliminare qualsiasi overhead di astrazione, il firmware usa esclusivamente accesso diretto ai registri hardware dell'ESP32:

\begin{itemize}
    \item \texttt{GPIO.in} — legge i 32 GPIO del bank-0 in un'unica istruzione a 32 bit.
    \item \texttt{GPIO.in1.val} — legge i GPIO del bank-1 (GPIO32--48).
    \item \texttt{GPIO.out\_w1ts} / \texttt{GPIO.out\_w1tc} — set/clear atomico dei bit di uscita (write-1-to-set / write-1-to-clear).
    \item \texttt{GPIO.enable\_w1ts} / \texttt{GPIO.enable\_w1tc} — abilitazione/disabilitazione in uscita (tristate) per il bus dati.
\end{itemize}

\subsection{Diagramma Temporale di un Ciclo di Lettura (PBI)}
Il diagramma seguente illustra un tipico ciclo di lettura gestito dall'ESP32 in modalità PBI.

\begin{figure}[h!]
\centering
\begin{tikztimingtable}[timing/slope=0.1, timing/coldist=2pt, xscale=1.2, yscale=1.5]
    PHI2 & L H L H L H L H L H L H \\
    Address Bus & U 2D{Addr} 8D{Addr} 2U \\
    R/W Line & U H H H H H H H H H 2U \\
    Data Bus & Z Z Z Z Z Z 4D{Data} 2Z \\
    \extracode
    \begin{pgfonlayer}{background}
        % Griglia temporale
        \vertlines[help lines, step=1]{0,1,...,12}
        % Annotazioni
        \node[below, font=\tiny, text=blue] at (3,-0.5) {CPU presenta indirizzo};
        \node[below, font=\tiny, text=blue] at (8,-0.5) {ESP32 fornisce dati};
        \node[below, font=\tiny, text=blue] at (11,-0.5) {CPU legge dati};
    \end{pgfonlayer}
\end{tikztimingtable}
\caption{Diagramma temporale di un ciclo di lettura del 6502 gestito dall'ESP32 (modalità PBI).}
\label{fig:timing_diagram}
\end{figure}

% --- SEZIONE 5: CODICE SORGENTE ---
\section{Frammento di Codice Sorgente}
Di seguito è riportato un estratto aggiornato del file \texttt{main.cpp} che mostra le definizioni dei pin e il cuore del \texttt{MonitorTask}. Tutte le funzioni critiche sono marcate \texttt{IRAM\_ATTR} per garantire l'esecuzione dalla RAM interna. L'indirizzo completo A0--A15 è decodificato interamente in software: nessuna logica esterna 74HCT/74LVC.

\begin{lstlisting}[style=cppstyle, caption={Definizioni pin ESP32-S3FN8 (QFN56) -- firmware corrente}, label=code:mcu_select]
/* Bank 0 (GPIO.in) */
#define PIN_PHI2        1    /* GPIO1, pin 6 -- Dedicated GPIO input ch 0  */
#define PIN_RW          2    /* GPIO2, pin 7 -- R/W_, HIGH = read           */
/* D0-D7: GPIO 4-11, bank-0 bit 4-11 */
#define DBUS_MASK       0x00000FF0UL
/* A0-A9: GPIO 12-21, bank-0 bit 12-21 */
#define ABUS_LO_MASK    0x003FF000UL

/* Bank 1 (GPIO.in1.val) */
#define PIN_A10         35   /* GPIO35, pin 40  -- bank-1 bit 3  */
#define PIN_A11         36   /* GPIO36, pin 41  -- bank-1 bit 4  */
#define PIN_A12         33   /* GPIO33, pin 38  -- bank-1 bit 1  */
#define PIN_A13         34   /* GPIO34, pin 39  -- bank-1 bit 2  */
#define PIN_A14         45   /* GPIO45, pin 51  -- bank-1 bit 13 */
#define PIN_A15         46   /* GPIO46, pin 52  -- bank-1 bit 14 */
#define PIN_ARESET      37   /* GPIO37, pin 42  -- system reset  */
#define PIN_CRESET      38   /* GPIO38, pin 43  -- VERA reset    */
#define PIN_CDONE       39   /* GPIO39, pin 44  -- VERA done     */
#define PIN_DEV_SEL_N   40   /* GPIO40, pin 45  -- Dedicated out ch 0 */
#define PIN_EXTSEL_N    41   /* GPIO41, pin 47  -- Dedicated out ch 1 */
#define PIN_MPD         42   /* GPIO42, pin 48  -- Dedicated out ch 2 */
#define PIN_RAMBO_EN     3   /* GPIO3,  pin  8  -- RAMbo enable  */

/* Dedicated GPIO channel masks */
#define DEDIC_IN_PHI2       (1u << 0)
#define DEDIC_OUT_DEVSELN   (1u << 0)
#define DEDIC_OUT_EXTSEL    (1u << 1)
#define DEDIC_OUT_MPD       (1u << 2)
#define DEDIC_OUT_CTRL_MASK 0x07u
#define DEDIC_OUT_CTRL_IDLE 0x07u  /* tutti HIGH = deasserted */

static inline uint16_t IRAM_ATTR decode_addr(uint32_t lo, uint32_t hi)
{
    uint16_t a = (uint16_t)((lo >> 12) & 0x3FFu);         /* A0-A9  */
    a |= (uint16_t)(((hi >> (PIN_A10-32)) & 1u) << 10);   /* A10    */
    a |= (uint16_t)(((hi >> (PIN_A11-32)) & 1u) << 11);   /* A11    */
    a |= (uint16_t)(((hi >> (PIN_A12-32)) & 1u) << 12);   /* A12    */
    a |= (uint16_t)(((hi >> (PIN_A13-32)) & 1u) << 13);   /* A13    */
    a |= (uint16_t)(((hi >> (PIN_A14-32)) & 1u) << 14);   /* A14    */
    a |= (uint16_t)(((hi >> (PIN_A15-32)) & 1u) << 15);   /* A15    */
    return a;
}
\end{lstlisting}

\begin{lstlisting}[style=cppstyle, caption={Nucleo del MonitorTask -- hot loop semplificato (PBI + RAMbo)}, label=code:monitor_task]
static void IRAM_ATTR MonitorTask(void *arg)
{
    /* Bundle Dedicated GPIO: input [PHI2], output [DEV_SEL_N, EXTSEL_N, MPD] */
    /* ... (setup bundle omesso per brevita') ... */
    cpu_ll_write_dedic_gpio_mask(DEDIC_OUT_CTRL_MASK, DEDIC_OUT_CTRL_IDLE);

    bool selected = false;
    bus_release();

    for (;;) {
        /* 1. Attesa fronte di salita PHI2 via TIE (1 ciclo CPU) */
        while (!(cpu_ll_read_dedic_gpio_in() & DEDIC_IN_PHI2));
        uint32_t g_lo = GPIO.in;
        uint32_t g_hi = GPIO.in1.val;

        /* 2. Decodifica indirizzo A0-A15 (16 bit, software puro) */
        bool     is_read = (g_lo & (1UL << PIN_RW)) != 0;
        uint16_t addr    = decode_addr(g_lo, g_hi);
        uint8_t  off8    = (uint8_t)(addr & 0xFFu);

        bool is_d1xx       = (addr >= 0xD100u && addr <= 0xD1FFu);
        bool is_d6xx       = (addr >= 0xD600u && addr <= 0xD7FFu);
        bool is_d8xx       = (addr >= 0xD800u && addr <= 0xDFFFu);
        bool is_vera_range = is_d1xx && (off8 <= 0x1Fu);
        bool is_vcs_latch  = is_d1xx && (off8 == 0xFFu);
        bool is_rambo_win  = (addr >= 0x4000u && addr <= 0x7FFFu);
        bool rambo_active  = rambo_hw_enabled && ((PORTB & 0x10u) == 0u);

        /* 3. Asserzione segnali controllo (1 istruzione TIE) */
        {
            uint8_t ctrl = DEDIC_OUT_CTRL_IDLE;
            /* Registri VERA sempre presenti, anche con latch = 0 */
            if (is_vera_range)
                ctrl &= ~(DEDIC_OUT_DEVSELN | DEDIC_OUT_EXTSEL);
            if (selected) {
                if ((is_d1xx && !is_vcs_latch) || is_d6xx)
                    ctrl &= ~DEDIC_OUT_EXTSEL;
                if (is_d8xx)   ctrl &= ~DEDIC_OUT_MPD;
            }
            if (rambo_active && is_rambo_win)
                ctrl &= ~DEDIC_OUT_EXTSEL;
            cpu_ll_write_dedic_gpio_mask(DEDIC_OUT_CTRL_MASK, ctrl);
        }
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

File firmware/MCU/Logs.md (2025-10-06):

# Performance Optimization Analysis for 6502 Bus Monitor on ESP32

## 1. Overview

This document details a critical performance optimization applied to the `6502_monitor` firmware. The project's goal is to use an ESP32 to monitor and interact with the bus of a 6502 processor running at 1.79 MHz. The optimization addresses a timing issue that prevented the ESP32 from correctly responding to the 6502's memory read cycles.

## 2. The Timing Problem

A 6502 processor running at 1.79 MHz has a clock cycle of approximately 558 nanoseconds. The `PHI2` clock signal is high for roughly half of this period, giving a critical time window of about **279 nanoseconds** for any device on the bus to respond.
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

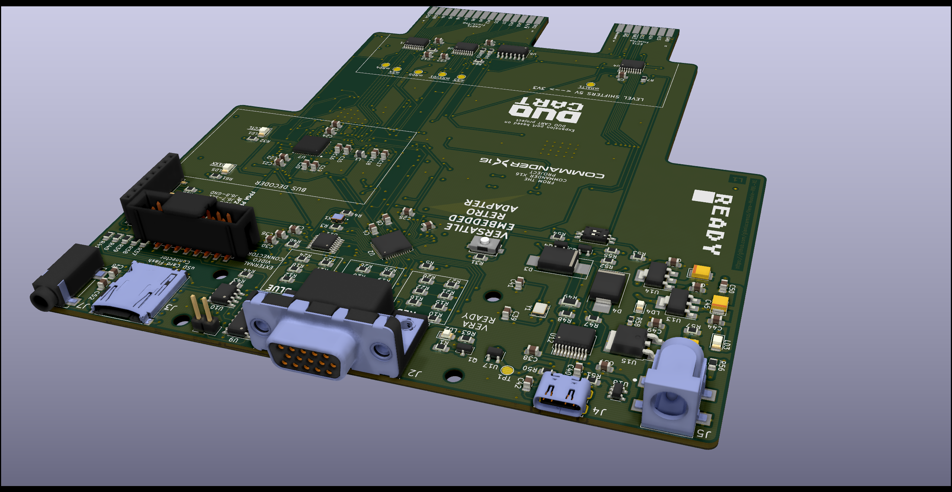
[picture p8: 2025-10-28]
images/VERA-MODULE-RBL.png

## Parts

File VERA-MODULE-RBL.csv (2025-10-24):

Comment | Designator | Footprint | LCSC
10uF | C13,C15,C17,C19,C21,C24 | Capacitor_SMD:C_0805_2012Metric_Pad1.18x1.45mm_HandSolder | C440198
100nF | C14,C16,C18,C20,C22,C23,C25,C27,C28,C29,C38,C40,C42,C44,C46,C49,C50,C52,C53,C54 | Capacitor_SMD:C_0805_2012Metric_Pad1.18x1.45mm_HandSolder | C840116
4.7uF | C26,C34,C35 | Capacitor_SMD:C_0805_2012Metric_Pad1.18x1.45mm_HandSolder | C7393930
2.2uF | C36 | Capacitor_SMD:C_0805_2012Metric_Pad1.18x1.45mm_HandSolder | C7393943
22uF | C37 | Capacitor_SMD:C_0805_2012Metric_Pad1.18x1.45mm_HandSolder | C86817
20pF | C39,C41 | Capacitor_SMD:C_0805_2012Metric_Pad1.18x1.45mm_HandSolder | C376875
1uF | C1,C2,C3,C4,C5,C6,C7,C8,C9,C10,C11,C12,C30,C31,C32,C33,C43,C55,C56,C57,C58,C59,C60 | Capacitor_SMD:C_0805_2012Metric_Pad1.18x1.45mm_HandSolder | C2798196
10uF-35V | C47 | Capacitor_Tantalum_SMD:CP_EIA-3528-12_Kemet-T_Pad1.50x2.35mm_HandSolder | C8017
10uF-20V | C45,C48,C51 | Capacitor_Tantalum_SMD:CP_EIA-3528-12_Kemet-T_Pad1.50x2.35mm_HandSolder | C8017
ATARI-CARTRIDGE | CART1 | RetroBitLab:ATARI-LEFT-CARTRIDGE
DIOSCH20V | D3,D4 | Diode_SMD:D_SMC_Handsoldering | C236151
ECIBUS | ECI1 | RetroBitLab:ATARI-XE-ECI-SLOT
Fiducial | FID1,FID2,FID3,FID4 | Fiducial:Fiducial_0.5mm_Mask1mm
MountingHole | H1,H2,H3,H4 | MountingHole:MountingHole_3.2mm_M3
CONN_SMD_HEADER_BOX_02x08_Odd_Even_2.54mm | J1 | RetroBitLab:PinHeader_BOX_2x08_P2.54mm_Vertical_SMD | C2685064
DS1038-15FBNSiA74-0CC | J2 | RetroBitLab:CONNFLY_DS1038-15FBNSIA74-0CC | C75754
CONN_DM3AT-SF-PEJM5 | J3 | RetroBitLab:HRS_DM3AT-SF-PEJM5 | C114218
DX07S016JA1R1500 | J4 | RetroBitLab:JAE_DX07S016JA1R1500 | C3197885
PJ-002AH-SMT-TR | J5 | RetroBitLab:CUI_PJ-002AH-SMT-TR | C22434687
CONN_SMD_01x08_Staggered_2.54mm | J6 | Connector_PinSocket_2.54mm:PinSocket_1x08_P2.54mm_Vertical_SMD_Pin1Right | C42380985
SJ-3523-SMT-TR | J7 | RetroBitLab:CONN_AUDIO_CUI_SJ-3523-SMT-TR | C4991872
Jumper_2_Open | JP2 | Connector_PinHeader_2.54mm:PinHeader_1x02_P2.54mm_Vertical
FB0805100R100MHZ4A | L1 | Inductor_SMD:L_0805_2012Metric_Pad1.15x1.40mm_HandSolder | C15957
Label-20mmx10mm | LBL1 | RetroBitLab:Label-20mmx10mm-Silkscreen
RED | LD1,LD3,LD5 | LED_SMD:LED_1206_3216Metric_Pad1.42x1.75mm_HandSolder | C965822
GREEN | LD2,LD4 | LED_SMD:LED_0805_2012Metric_Pad1.15x1.40mm_HandSolder | C84260
VERA X16 LOGO | LOGO1 | RetroBitLab:x16logo
ATARI READY | LOGO2 | RetroBitLab:atari_ready_8mm_rev
KiCAD DESIGN | LOGO3 | Symbol:KiCad-Logo2_6mm_SilkScreen
ATARI DUO BUS | LOGO4 | RetroBitLab:DUOCart_20x11_Rev
ESP32_BOBOARD | LOGO5 | RetroBitLab:ESP32_BOBOARD_5V_21.7mmx21.7mm
MOSFET-BSS138-SOT-23 | Q1 | Package_TO_SOT_SMD:SOT-23 | C82045
BC817,SOT-23 | Q3,Q4 | Package_TO_SOT_SMD:SOT-23 | C20069154
2K7 | R1 | Resistor_SMD:R_0805_2012Metric_Pad1.20x1.40mm_HandSolder | C313926
2K | R11,R13,R15 | Resistor_SMD:R_0805_2012Metric_Pad1.20x1.40mm_HandSolder | C114572
150R | R12,R14,R16 | Resistor_SMD:R_0805_2012Metric_Pad1.20x1.40mm_HandSolder | C17471
160R | R18,R20,R22 | Resistor_SMD:R_0805_2012Metric_Pad1.20x1.40mm_HandSolder | C2960793
910R | R17,R19,R21 | Resistor_SMD:R_0805_2012Metric_Pad1.20x1.40mm_HandSolder | C2930211
27R | R24,R26,R28 | Resistor_SMD:R_0805_2012Metric_Pad1.20x1.40mm_HandSolder | C17594
820R | R29,R30 | Resistor_SMD:R_0805_2012Metric_Pad1.20x1.40mm_HandSolder | C17837
50R | R3,R4 | Resistor_SMD:R_0805_2012Metric_Pad1.20x1.40mm_HandSolder | C2828866
330R | R32,R61 | Resistor_SMD:R_0805_2012Metric_Pad1.20x1.40mm_HandSolder | C313892
47K | R37,R38,R39,R40,R41,R42,R43,R44 | Resistor_SMD:R_0805_2012Metric_Pad1.20x1.40mm_HandSolder | C20142780
560R | R45,R46,R67,R68 | Resistor_SMD:R_0805_2012Metric_Pad1.20x1.40mm_HandSolder | C28636
DNP | R49 | Resistor_SMD:R_1206_3216Metric_Pad1.30x1.75mm_HandSolder
10K | R2,R5,R6,R7,R33,R34,R35,R36,R47,R48,R53,R62,R63,R64,R65,R66 | Resistor_SMD:R_0805_2012Metric_Pad1.20x1.40mm_HandSolder | C84376
5K1 | R50,R51 | Resistor_SMD:R_0805_2012Metric_Pad1.20x1.40mm_HandSolder | C27834
220R | R54 | Resistor_SMD:R_0805_2012Metric_Pad1.20x1.40mm_HandSolder | C5120092
2K2 | R52,R55 | Resistor_SMD:R_0805_2012Metric_Pad1.20x1.40mm_HandSolder | C17520
0R | R56 | Resistor_SMD:R_0805_2012Metric_Pad1.20x1.40mm_HandSolder | C328378
510R | R23,R25,R27,R57 | Resistor_SMD:R_0805_2012Metric_Pad1.20x1.40mm_HandSolder | C114563
330R | R58 | Resistor_SMD:R_0603_1608Metric_Pad0.98x0.95mm_HandSolder | C105881
4K7 | R31,R59,R60 | Resistor_SMD:R_0805_2012Metric_Pad1.20x1.40mm_HandSolder | C17673
4K3 | R8,R9,R10 | Resistor_SMD:R_0805_2012Metric_Pad1.20x1.40mm_HandSolder | C17667
SPST2P | SW1 | RetroBitLab:SPST-7.3x3.9x2.5-WUERTH-434121025816 | C318911
SPST_SWITCH_SMD_4P,4.1x5.4mm | SW2 | RetroBitLab:SW_DIP_SPSTx02_DSHP02TS-S | C319052
TP5V | TP1 | TestPoint:TestPoint_Pad_D2.0mm
W25Q16JVSNIQ | U10 | Package_SO:SOIC-8_3.9x4.9mm_P1.27mm | C2456211
WM8524CGEDT | U11 | Package_SO:TSSOP-16_4.4x5mm_P0.65mm | C146242
USBCH340T | U12 | Package_SO:SSOP-20_5.3x7.2mm_P0.65mm | C8689
AMS1117-3.3 | U13 | Package_TO_SOT_SMD:SOT-223-3_TabPin2 | C6186
AMS1117-1.2 | U14 | Package_TO_SOT_SMD:SOT-223-3_TabPin2 | C347218
L7805 | U15 | Package_TO_SOT_SMD:TO-252-2 | C110908
MAX40200AUK | U17,U18 | Package_TO_SOT_SMD:SOT-23-5 | C47118006
ICE40UP5K-SG48ITR | U2 | RetroBitLab:QFN-48-1EP_7x7mm_P0.5mm_EP5.6x5.6mm | C2678152
TXS0108EPW | U1,U3,U4,U6,U16 | Package_SO:TSSOP-20_4.4x6.5mm_P0.65mm | C17206
CD4011B | U5,U9 | Package_SO:SOIC-14_3.9x8.7mm_P1.27mm | C194334
ESP32-PICO-D4 | U7 | RetroBitLab:ESP32-PICO-D4 | C193707
74CBTLV3126PW,118 | U8 | Package_SO:TSSOP-14_4.4x5mm_P0.65mm | C543078
ECS-2033-250-BN | X1 | RetroBitLab:OSC_ECS-2033-250-BN | C2441279
12MHzC | Y1 | Crystal:Crystal_SMD_EuroQuartz_MT-4Pin_3.2x2.5mm | C9002
TestPoint | ~mRSVD1,~mHALT1,~mS4,mRD4,~mS5,mRD5 | TestPoint:TestPoint_Pad_D2.0mm

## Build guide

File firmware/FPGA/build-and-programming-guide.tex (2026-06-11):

\documentclass[11pt,a4paper]{article}

\usepackage[T1]{fontenc}
\usepackage[utf8]{inputenc}
\usepackage[english]{babel}
\usepackage{geometry}
\usepackage{listings}
\usepackage{xcolor}
\usepackage{booktabs}
\usepackage{longtable}
\usepackage{array}
\usepackage{hyperref}
\usepackage{fancyhdr}
\usepackage{titlesec}
\usepackage{enumitem}
\usepackage{graphicx}
\usepackage{amsmath}
\usepackage{parskip}

\geometry{
    top=25mm, bottom=25mm,
    left=25mm, right=25mm
}

% ---------------------------------------------------------------------------
% Colours
% ---------------------------------------------------------------------------
\definecolor{codebg}{RGB}{245,245,245}
\definecolor{codeframe}{RGB}{200,200,200}
\definecolor{kwcolor}{RGB}{0,0,180}
\definecolor{commentcolor}{RGB}{80,120,80}
\definecolor{stringcolor}{RGB}{160,32,32}
\definecolor{shellprompt}{RGB}{100,100,100}

% ---------------------------------------------------------------------------
% Listings style
% ---------------------------------------------------------------------------
\lstdefinestyle{shell}{
    backgroundcolor=\color{codebg},
    frame=single,
    framerule=0.4pt,
    rulecolor=\color{codeframe},
    basicstyle=\ttfamily\small,
    breaklines=true,
    breakatwhitespace=false,
    showstringspaces=false,
    tabsize=4,
    captionpos=b,
    xleftmargin=6pt,
    xrightmargin=6pt,
    aboveskip=8pt,
    belowskip=8pt,
}

\lstdefinestyle{vhdl}{
    backgroundcolor=\color{codebg},
    frame=single,
    framerule=0.4pt,
    rulecolor=\color{codeframe},
    basicstyle=\ttfamily\small,
    keywordstyle=\color{kwcolor}\bfseries,
    commentstyle=\color{commentcolor}\itshape,
    stringstyle=\color{stringcolor},
    morekeywords={library,use,entity,port,architecture,signal,process,
                  begin,end,if,then,else,elsif,rising_edge,std_logic,
                  std_logic_vector,unsigned,integer,constant,when,
                  inout,in,out,downto,others,not,and,or},
    breaklines=true,
    showstringspaces=false,
    tabsize=4,
    captionpos=b,
    xleftmargin=6pt,
    xrightmargin=6pt,
    aboveskip=8pt,
    belowskip=8pt,
}

\lstset{style=shell}

% ---------------------------------------------------------------------------
% Page style
% ---------------------------------------------------------------------------
\pagestyle{fancy}
\fancyhf{}
\fancyhead[L]{\small VERA RBL-XE -- FPGA Build \& Programming Guide}
\fancyhead[R]{\small Rev~4}
\fancyfoot[C]{\thepage}
\renewcommand{\headrulewidth}{0.4pt}

% ---------------------------------------------------------------------------
% Section formatting
% ---------------------------------------------------------------------------
\titleformat{\section}{\large\bfseries}{}{0em}{\thesection\quad}
\titleformat{\subsection}{\normalsize\bfseries}{}{0em}{\thesubsection\quad}

% ---------------------------------------------------------------------------
% Convenience macros
% ---------------------------------------------------------------------------
\newcommand{\cmd}[1]{\texttt{#1}}
\newcommand{\sig}[1]{\texttt{#1}}
\newcommand{\file}[1]{\texttt{#1}}
\newcommand{\hex}[1]{\texttt{\$#1}}

% ---------------------------------------------------------------------------
\begin{document}
% ---------------------------------------------------------------------------

\begin{titlepage}
    \centering
    \vspace*{30mm}
    {\Huge\bfseries VERA RBL-XE\\[4mm]
     FPGA Build \& Programming Guide\par}
    \vspace{10mm}
    {\large iCE40UP5K -- Rev~4\par}
    \vspace{8mm}
    {\normalsize
        6502 bus controller with RAMbo 256\,KB, PBI RAM/ROM,\\
        and external SRAM support\par}
    \vfill
    {\small Last updated: \today\par}
\end{titlepage}

\tableofcontents
\newpage

% ===========================================================================
\section{Overview}
% ===========================================================================

This document describes the complete workflow for building and programming
the FPGA firmware for the VERA RBL-XE module.  The firmware implements a
6502 bus controller on a Lattice iCE40UP5K, replacing the ESP32-S3 MCU
used in the previous design.

\subsection{Architecture summary}

\begin{itemize}[noitemsep]
    \item \textbf{PBI RAM} (\hex{D600}--\hex{D7FF}, 512\,B): stored in
          iCE40 BRAM (1 EBR block).
    \item \textbf{PBI ROM} (\hex{D800}--\hex{DFFF}, 2\,KB): stored in
          iCE40 BRAM (4 EBR blocks), pre-loaded at synthesis time from
          the assembled 6502 driver binary.
    \item \textbf{RAMbo} (\hex{4000}--\hex{7FFF}, 16\,KB window,
          256\,KB total): served by an external 512K$\times$8 SRAM
          (e.g.\ AS6C4008-55SIN).  The FPGA controls chip-enable,
          output-enable, write-enable, and the upper four address bits
          (bank), using only 7 new I/O pins.
    \item \textbf{PHI2 synchronisation}: PHI2 is treated as a data input
          and synchronised to the 25\,MHz FPGA clock via a two-stage
          flip-flop chain, producing a single-cycle \cmd{phi2\_rise}
          pulse used to trigger all registered logic.
    \item \textbf{Two bitstreams -- \cmd{VERA\_IS\_PBI} generic}: the
          top-level entity exposes a VHDL-2008 boolean generic that
          selects the bus interface at synthesis time.
          \emph{PBI mode} (\cmd{VERA\_IS\_PBI=true}): latch at
          \hex{D1FF}, PBI RAM and ROM in BRAM (5 EBR blocks), EXTSEL
          for PBI RAM and RAMbo, MPD for PBI ROM reads.
          \emph{CCTL mode} (\cmd{VERA\_IS\_PBI=false}): latch at
          \hex{D5FF} (write \texttt{\$80} to select, \texttt{\$00}
          to deselect), no BRAM (Yosys eliminates dead code: 0 EBR),
          EXTSEL for RAMbo only, MPD always inactive.
    \item \textbf{Hardware configuration pins}: \sig{PBI\_ID\_SEL}
          (pin~27) is wired via PCB jumper to one of D[0..7]; the
          sampled bit value latches VERA\_CS in PBI mode
          (\cmd{vera\_cs\_latch <= not PBI\_ID\_SEL}).
          \sig{RAMBO\_EN} (pin~28) with pullup (VCC) enables RAMbo;
          with pulldown (GND) disables it regardless of PBCTL[2].
\end{itemize}

\subsection{Memory map}

\begin{center}
\begin{tabular}{llll}
\toprule
\textbf{Range} & \textbf{Size} & \textbf{Function} & \textbf{Implementation} \\
\midrule
\hex{4000}--\hex{7FFF} & 16\,KB window & RAMbo (256\,KB banked) & External SRAM \\
\hex{D1FF}            & 1\,B          & VERA\_CS latch (write) & Register \\
\hex{D301}            & 1\,B          & PIA PORTB snoop        & Register \\
\hex{D303}            & 1\,B          & PIA PBCTL snoop        & Register \\
\hex{D600}--\hex{D7FF} & 512\,B        & PBI RAM                & BRAM (1 EBR) \\
\hex{D800}--\hex{DFFF} & 2\,KB         & PBI ROM                & BRAM (4 EBR) \\
\bottomrule
\end{tabular}
\end{center}

\noindent\textbf{Note (CCTL mode):} when built with \cmd{VERA\_IS\_PBI=false}
the VERA\_CS latch address changes to \hex{D5FF} (write \texttt{\$80} to
select, \texttt{\$00} to deselect), and PBI RAM/ROM are absent (0~EBR\@).

% ===========================================================================
\section{Prerequisites}
% ===========================================================================

\subsection{FPGA toolchain}

While some tools are available via \cmd{apt} on Debian/Ubuntu, they are often outdated (especially on Debian 11). The recommended way to set up the toolchain is using the \textbf{OSS CAD Suite}, which provides pre-compiled, up-to-date versions of Yosys, nextpnr, GHDL, and all required plugins.

\subsubsection{Installing OSS CAD Suite (Recommended for Debian 11)}

\begin{enumerate}
    \item Download the latest Linux x64 archive from: \\
          \url{https://github.com/YosysHQ/oss-cad-suite-build/releases/latest}
    \item Extract the archive (e.g., to \file{\$HOME/oss-cad-suite}).
    \item Add the \file{bin} directory to your \cmd{PATH}:
\end{enumerate}

\begin{lstlisting}[style=shell]
export PATH="$HOME/oss-cad-suite/bin:$PATH"
\end{lstlisting}

This suite includes \cmd{yosys}, \cmd{nextpnr-ice40}, \cmd{icepack}, \cmd{iceprog}, and \cmd{ghdl} with the \cmd{ghdl-yosys-plugin} already integrated.

\subsubsection{Alternative: Manual installation via apt (Debian 12+)}

On newer distributions, you can try:

\begin{lstlisting}[style=shell]
sudo apt install fpga-icestorm nextpnr-ice40 yosys ghdl
\end{lstlisting}

\textbf{Note:} if installing via \cmd{apt}, you will likely need to build the \cmd{ghdl-yosys-plugin} from source as described below, because it is rarely packaged.

\begin{lstlisting}[style=shell]
git clone https://github.com/ghdl/ghdl-yosys-plugin
cd ghdl-yosys-plugin
make
sudo make install
\end{lstlisting}

\subsection{Flash programming tools}

On modern distributions (e.g. Debian 12+), \cmd{openFPGALoader} can be installed via package manager:

\begin{lstlisting}[style=shell]
sudo apt install openFPGALoader
\end{lstlisting}

On older distributions like \textbf{Debian 11 (Bullseye)}, the package is not available and must be built from source.

\subsubsection{Building openFPGALoader from source}

First, install the required dependencies and build tools:

\begin{lstlisting}[style=shell]
sudo apt install git cmake make g++ pkg-config libusb-1.0-0-dev \
                 libhidapi-dev libgpiod-dev libusbmuxd-dev
\end{lstlisting}

Then, clone the repository and build the project:

\begin{lstlisting}[style=shell]
git clone https://github.com/trabucayre/openfpgaloader
cd openfpgaloader
mkdir build
cd build
# Use -DCMAKE_INSTALL_PREFIX=$HOME to install in your home directory
# or omit it to install system-wide (requires sudo make install)
cmake .. -DCMAKE_INSTALL_PREFIX=$HOME
make -j$(nproc)
make install
\end{lstlisting}

Ensure \file{\$HOME/bin} is in your \cmd{PATH} if you used the home directory prefix.

\subsubsection{Iceprog}
The \cmd{iceprog} tool is already included in the \cmd{fpga-icestorm} package and supports FTDI-based programmers (e.g. FT2232H).

\subsection{6502 assembler (cc65)}

The PBI ROM driver is written in 6502 assembly and built with the
cc65 toolchain.

\begin{lstlisting}[style=shell]
sudo apt install cc65
\end{lstlisting}

\subsection{Python 3}

Required to run \file{gen\_pbi\_rom\_pkg.py}, which converts the
assembled 6502 binary into a VHDL constant package.

\begin{lstlisting}[style=shell]
sudo apt install python3
\end{lstlisting}

\subsection{Tool roles at a glance}

\begin{center}
\begin{tabular}{llll}
\toprule
\textbf{Tool} & \textbf{Input} & \textbf{Output} & \textbf{Purpose} \\
\midrule
\cmd{ca65} / \cmd{ld65}    & \file{.s} sources    & \file{.bin}      & 6502 assembly \\
\cmd{gen\_pbi\_rom\_pkg.py} & \file{.bin}          & \file{.vhd}      & ROM initialisation \\
\cmd{ghdl} (plugin)         & VHDL sources         & RTLIL            & VHDL elaboration \\
\cmd{yosys}                 & RTLIL                & \file{.json}     & Synthesis \\
\cmd{nextpnr-ice40}         & \file{.json + .pcf}  & \file{.asc}      & Place \& route \\
\cmd{icepack}               & \file{.asc}          & \file{.bin}      & Bitstream packing \\
\cmd{openFPGALoader}        & \file{.bin}          & SPI flash        & Programming \\
\bottomrule
\end{tabular}
\end{center}

% ===========================================================================
\section{Build Flow}
% ===========================================================================

\subsection{Step 1 -- Assemble the 6502 ROM driver}

The PBI ROM at \hex{D800}--\hex{DFFF} contains a 2\,KB 6502 driver
assembled from \file{firmware/MCU/6502/src/vera\_pbi\_handler.s}.

\begin{lstlisting}[style=shell,caption={Assemble the 6502 driver}]
cd firmware/MCU/6502
make
\end{lstlisting}

This single command runs three sub-steps:

\begin{enumerate}[noitemsep]
    \item \textbf{Assemble}: \cmd{ca65} compiles
          \file{vera\_pbi\_handler.s} into \file{vera\_pbi\_handler.o}.
    \item \textbf{Link}: \cmd{ld65} links with \file{pbi-driver.ld}
          to produce \file{vera\_pbi\_handler.bin}.
    \item \textbf{Generate VHDL ROM package}: \file{gen\_pbi\_rom\_pkg.py}
          reads the binary and writes
          \file{../../FPGA/pbi\_rom\_pkg.vhd} with the
          \cmd{PBI\_ROM\_INIT} constant.
\end{enumerate}

To regenerate only the VHDL package when the binary already exists:

\begin{lstlisting}[style=shell]
make fpga-rom
\end{lstlisting}

\subsection{Step 2 -- Synthesis}

The top-level entity exposes a VHDL-2008 boolean generic,
\cmd{VERA\_IS\_PBI} (default \cmd{true}), that selects the bus interface
at synthesis time.  The Makefile invokes Yosys twice, producing two
independent bitstreams from the same source:

\begin{lstlisting}[style=shell,caption={PBI synthesis (VERA\_IS\_PBI=true)}]
cd firmware/FPGA
yosys -m ghdl -p \
    "ghdl --std=08 -gVERA_IS_PBI=true \
          custom_types.vhd pbi_rom_pkg.vhd C6502_Interface.vhd \
          -e C6502_Interface; \
     synth_ice40 -top C6502_Interface -json C6502_Interface_PBI.json"
\end{lstlisting}

\begin{lstlisting}[style=shell,caption={CCTL synthesis (VERA\_IS\_PBI=false)}]
yosys -m ghdl -p \
    "ghdl --std=08 -gVERA_IS_PBI=false \
          custom_types.vhd pbi_rom_pkg.vhd C6502_Interface.vhd \
          -e C6502_Interface; \
     synth_ice40 -top C6502_Interface -json C6502_Interface_CCTL.json"
\end{lstlisting}

The \cmd{-m ghdl} flag loads the GHDL plugin into Yosys, which handles
VHDL analysis and elaboration.  When \cmd{VERA\_IS\_PBI=false}, Yosys
eliminates all PBI RAM/ROM dead code, reducing resource usage
dramatically.  Measured values after place-and-route with nextpnr-ice40:

\begin{center}
\begin{tabular}{lrrrr}
\toprule
\textbf{Resource} & \textbf{PBI} & \textbf{CCTL} & \textbf{Available} & \textbf{\% (PBI)} \\
\midrule
ICESTORM\_LC (total)     &  87 &  1 & 5280 &  1\% \\
\quad of which LUT4 only &  52 &  1 &      &     \\
\quad of which LUT4+DFF  &   5 &  0 &      &     \\
\quad of which DFF only  &   5 &  0 &      &     \\
\quad of which CARRY only&  21 &  0 &      &     \\
\midrule
ICESTORM\_RAM (EBR)      &   5 &  0 &   30 & 16\% \\
SB\_IO (I/O buffers)     &  39 & 39 &   39 & 100\% \\
ICESTORM\_SPRAM          &   0 &  0 &    4 &  0\% \\
\midrule
\textbf{Fmax (CLK)}      & \multicolumn{4}{l}{\textbf{62.72\,MHz} (PBI, PASS at 25\,MHz)} \\
\bottomrule
\end{tabular}
\end{center}

\textbf{I/O budget note:} the iCE40UP5K-SG48 exposes exactly 39 user I/O
pins, and this design uses all 39.  The mode selection (PBI vs.\ CCTL)
is compiled into the bitstream via \cmd{VERA\_IS\_PBI} rather than being
a runtime input, freeing the two former \sig{DIP\_SEL} pins for
dedicated hardware functions: \sig{PBI\_ID\_SEL} (pin~27) and
\sig{RAMBO\_EN} (pin~28).

\subsection{Step 3 -- Place \& Route}

Place \& route assigns logic cells and routes signals to physical
iCE40 resources, guided by the pin constraints file.

\begin{lstlisting}[style=shell,caption={Place \& route with nextpnr-ice40 (PBI example)}]
nextpnr-ice40 --up5k --package sg48 \
    --json C6502_Interface_PBI.json \
    --pcf board-pin-mapping.pcf \
    --asc C6502_Interface_PBI.asc
\end{lstlisting}

The CCTL build uses the same command with \file{\_CCTL} filename suffixes.

\textbf{Important:} all pin numbers in \file{board-pin-mapping.pcf} are
placeholders.  Edit the file to match your actual schematic before this
step (see Section~\ref{sec:pins}).

nextpnr reports timing after routing.  Measured results:

\begin{center}
\begin{tabular}{llr}
\toprule
\textbf{Path type} & \textbf{Description} & \textbf{Worst delay} \\
\midrule
CLK $\to$ CLK   & Registered path (Fmax) & 15.94\,ns (62.72\,MHz) \\
async $\to$ async & Combinational (PHI2 gate) & 28.12\,ns \\
async $\to$ CLK  & Input setup time        & 26.89\,ns \\
CLK $\to$ async  & Clock-to-output         & 17.17\,ns \\
\bottomrule
\end{tabular}
\end{center}

The 25\,MHz system clock (period 40\,ns) has \textbf{24.06\,ns of slack}
on the registered path.  The combinational PHI2-gated outputs settle in
at most 28.12\,ns after address/control inputs change --- well within the
6502 PHI2-high window of $\approx$279\,ns at 1.79\,MHz.

\subsection{Step 4 -- Pack the bitstream}

\cmd{icepack} converts the ASCII intermediate format produced by
nextpnr into the binary bitstream that is written to the SPI flash.

\begin{lstlisting}[style=shell,caption={Pack binary bitstreams}]
icepack C6502_Interface_PBI.asc  C6502_Interface_PBI.bin
icepack C6502_Interface_CCTL.asc C6502_Interface_CCTL.bin
\end{lstlisting}

The \file{.bin} file is what gets programmed into the SPI flash.
Bitstream size is device-dependent (not design-dependent) on the iCE40:
both bitstreams measure \textbf{$\approx$104\,KB} (iCE40UP5K SG48).

\subsection{Step 5 -- Program the SPI flash}

The iCE40UP5K loads its configuration from an external SPI NOR flash
at power-up.  The programmer writes the bitstream into that flash.

\subsubsection{Using openFPGALoader (recommended)}

\begin{lstlisting}[style=shell,caption={Program with openFPGALoader}]
# PBI bitstream (PBI connector, $D1xx)
openFPGALoader -b ice40_generic C6502_Interface_PBI.bin
# CCTL bitstream (cartridge port, $D5xx)
openFPGALoader -b ice40_generic C6502_Interface_CCTL.bin
\end{lstlisting}

Select the programmer cable explicitly if needed:

\begin{lstlisting}[style=shell]
openFPGALoader --cable ft2232      C6502_Interface_PBI.bin   # FTDI FT2232H
openFPGALoader --cable ft232       C6502_Interface_PBI.bin   # FTDI FT232H
openFPGALoader --cable tigard      C6502_Interface_PBI.bin   # Tigard
openFPGALoader --cable raspberrypi C6502_Interface_PBI.bin   # Raspberry Pi GPIO
\end{lstlisting}

\subsubsection{Using iceprog (FTDI FT2232H)}

\begin{lstlisting}[style=shell,caption={Program with iceprog}]
iceprog C6502_Interface_PBI.bin    # PBI bitstream
iceprog C6502_Interface_CCTL.bin   # CCTL bitstream

# Erase + write (useful if previous write was partial)
iceprog -e 1048576 C6502_Interface_PBI.bin
\end{lstlisting}

\subsection{One-command build and flash}

The \file{firmware/FPGA/Makefile} wraps all steps:

\begin{lstlisting}[style=shell]
cd firmware/FPGA
make pbi               # synthesise + P&R + pack -> C6502_Interface_PBI.bin
make cctl              # synthesise + P&R + pack -> C6502_Interface_CCTL.bin
make                   # build both (default)
make flash-pbi         # write PBI  bitstream via openFPGALoader
make flash-cctl        # write CCTL bitstream via openFPGALoader
make flash-pbi-iceprog   # write PBI  via iceprog (FTDI FT2232H)
make flash-cctl-iceprog  # write CCTL via iceprog
make doc               # regenerate PDF documentation
make clean             # remove all generated files
\end{lstlisting}

% ===========================================================================
\section{Programmer Wiring}
% ===========================================================================

The SPI flash is shared between the FPGA (configuration bus at boot)
and the programmer (writes the bitstream).  During programming, the
FPGA is held in reset by asserting \sig{CRESET\_B} low.

\begin{center}
\begin{tabular}{lll}
\toprule
\textbf{Programmer signal} & \textbf{iCE40UP5K pin} & \textbf{SPI flash pin} \\
\midrule
MOSI  & SPI\_SI   & DI  \\
MISO  & SPI\_SO   & DO  \\
SCK   & SPI\_SCK  & CLK \\
CS\#  & --        & CS\# \\
CRST\# & CRESET\_B & -- \\
CDONE & CDONE     & -- \\
\bottomrule
\end{tabular}
\end{center}

Recommended SPI flash: Winbond W25Q16 (2\,MB) or W25Q32 (4\,MB).

% ===========================================================================
\section{Reset Sequencing}
\label{sec:reset}
% ===========================================================================

The VERA RBL-XE module requires a defined power-on boot sequence: the
Atari computer and the VERA graphics chip must remain in reset until all
FPGA configurations have completed.  This is implemented with a single
74LVC1G08 logic gate --- no MCU or firmware is needed.

\subsection{Boot sequence}

\begin{enumerate}[noitemsep]
    \item \textbf{Power-on:} both \sig{VERA\_RESET\#} and
          \sig{ATARI\_RESET\#} are held low.
    \item \textbf{FPGA ready} (\sig{FPGA\_CDONE} goes high,
          $\approx$50--100\,ms after power-on): \sig{VERA\_RESET\#} is
          released, allowing VERA to start loading its own bitstream
          from its SPI flash.
    \item \textbf{VERA ready} (\sig{VERA\_CDONE} goes high,
          $\approx$200--500\,ms later): \sig{ATARI\_RESET\#} is released
          and the Atari boots normally.
\end{enumerate}

The natural SPI flash loading times provide all necessary delays; no RC
timer or additional delay circuit is required.

\subsection{Logic}

\begin{center}
\begin{tabular}{ll}
\toprule
\textbf{Signal} & \textbf{Boolean expression} \\
\midrule
\sig{VERA\_RESET\#}  & \sig{FPGA\_CDONE} \\
\sig{ATARI\_RESET\#} & \sig{FPGA\_CDONE}~AND~\sig{VERA\_CDONE} \\
\bottomrule
\end{tabular}
\end{center}

\begin{center}
\begin{tabular}{ccccp{3.5cm}}
\toprule
\textbf{FPGA\_CDONE} & \textbf{VERA\_CDONE} &
\textbf{VERA\_RST\#} & \textbf{ATARI\_RST\#} & \textbf{Phase} \\
\midrule
0 & 0 & 0 & 0 & Power-on / FPGA loading \\
1 & 0 & 1 & 0 & FPGA ready, VERA loading \\
1 & 1 & 1 & 1 & System ready \\
\bottomrule
\end{tabular}
\end{center}

\subsection{Circuit -- 74LVC1G08 (SOT-23-5)}

A single \textbf{74LVC1G08} (2-input AND gate, SOT-23-5) implements
\sig{ATARI\_RESET\#}.  \sig{VERA\_RESET\#} connects directly from
\sig{FPGA\_CDONE} through a 33\,$\Omega$ series resistor.

\begin{lstlisting}[style=shell]
VCC --[4k7]--+-------- FPGA_CDONE (open-drain)
             |
             +--[33R]- VERA_RESET#
             |
             +-- A -\
                     +--- 74LVC1G08 ---[33R]--- ATARI_RESET#
             +-- B -/
             |
VCC --[4k7]--+-------- VERA_CDONE (open-drain)
\end{lstlisting}

Both CDONE outputs are open-drain; they require an external pullup to
VCC\@.  The 33\,$\Omega$ series resistors limit current if an external
driver (e.g.\ the Atari RESET button, which pulls the line to GND via
an open-collector circuit) conflicts with the 74LVC output.

\textbf{Why 74LVC and not 74HC?}  The 74LVC family has \emph{5\,V
tolerant inputs} while operating at 3.3\,V VCC\@.  The CDONE signals
are at 3.3\,V; the Atari RESET line belongs to a 5\,V TTL system.  The
74LVC output at 3.3\,V is correctly recognised as HIGH by 5\,V TTL
logic (V$_{\text{IH}} = 2.0$\,V).  The 74HC family is not suitable for
this mixed-voltage interface.

\subsection{Bill of materials}

\begin{center}
\begin{tabular}{lllp{4.5cm}}
\toprule
\textbf{Ref} & \textbf{Value} & \textbf{Package} & \textbf{Function} \\
\midrule
U1  & 74LVC1G08      & SOT-23-5 & 2-input AND gate \\
R1  & 4.7\,k$\Omega$ & 0402     & Pullup for FPGA\_CDONE \\
R2  & 4.7\,k$\Omega$ & 0402     & Pullup for VERA\_CDONE \\
R3  & 33\,$\Omega$   & 0402     & Series resistor on VERA\_RESET\# \\
R4  & 33\,$\Omega$   & 0402     & Series resistor on ATARI\_RESET\# \\
\bottomrule
\end{tabular}
\end{center}

Total cost under 0.30\,EUR; no firmware required.

% ===========================================================================
\section{Pin Assignment}
\label{sec:pins}
% ===========================================================================

Edit \file{board-pin-mapping.pcf} and replace every pin number with the
actual pad number from your schematic before running nextpnr-ice40.

The \sig{CLK} signal must be assigned to a \textbf{Global Buffer (GB)
input} pin.  Valid GB pins on the iCE40UP5K SG48 package are:
\textbf{20, 28, 31, 38, 41, 43, 48}.

\textbf{Valid user I/O pin numbers for SG48} (39 total):
\begin{quote}\ttfamily
2, 3, 4, 6, 9, 10, 11, 12, 13, 14, 15, 16, 17, 18, 19, 20, 21,\\
23, 25, 26, 27, 28, 31, 32, 34, 35, 36, 37, 38, 39,\\
40, 41, 42, 43, 44, 45, 46, 47, 48
\end{quote}
Pins 1, 5, 7, 8, 22, 24, 29, 30, 33 are power/ground or reserved and
\textbf{must not} appear in the PCF file --- nextpnr rejects them with an
error.

\subsection{Complete pin table}

\begin{center}
\small
\begin{longtable}{llllp{5.5cm}}
\toprule
\textbf{Signal} & \textbf{Dir} & \textbf{PCF pin} & \textbf{Std} &
\textbf{Description} \\
\midrule
\endfirsthead
\toprule
\textbf{Signal} & \textbf{Dir} & \textbf{PCF pin} & \textbf{Std} &
\textbf{Description} \\
\midrule
\endhead
\midrule
\multicolumn{5}{r}{\small continued on next page}\\
\endfoot
\bottomrule
\endlastfoot

% --- Clock ---
\sig{CLK}           & In    & 35* & LVCMOS33 &
    25\,MHz system clock. Must land on a GB pin. \\[2pt]

% --- 6502 address bus ---
\sig{A[0]}          & In    & 40* & LVCMOS33 & 6502 address bit 0 \\
\sig{A[1]}          & In    & 41* & LVCMOS33 & 6502 address bit 1 \\
\sig{A[2]}          & In    & 42* & LVCMOS33 & 6502 address bit 2 \\
\sig{A[3]}          & In    & 43* & LVCMOS33 & 6502 address bit 3 \\
\sig{A[4]}          & In    & 44* & LVCMOS33 & 6502 address bit 4 \\
\sig{A[5]}          & In    & 45* & LVCMOS33 & 6502 address bit 5 \\
\sig{A[6]}          & In    & 46* & LVCMOS33 & 6502 address bit 6 \\
\sig{A[7]}          & In    & 47* & LVCMOS33 & 6502 address bit 7 \\
\sig{A[8]}          & In    & 48* & LVCMOS33 & 6502 address bit 8 \\
\sig{A[9]}          & In    &  6* & LVCMOS33 & 6502 address bit 9 \\
\sig{A[10]}         & In    &  2* & LVCMOS33 & 6502 address bit 10 \\
\sig{A[11]}         & In    &  3* & LVCMOS33 & 6502 address bit 11 \\
\sig{A[12]}         & In    &  4* & LVCMOS33 & 6502 address bit 12 \\
\sig{A[13]}         & In    & 26* & LVCMOS33 &
    6502 address bit 13. Also wired to SRAM A[13] on PCB. \\
\sig{A[14]}         & In    &  9* & LVCMOS33 & 6502 address bit 14 \\
\sig{A[15]}         & In    & 10* & LVCMOS33 & 6502 address bit 15 \\[2pt]

% --- 6502 data bus ---
\sig{D[0]}          & InOut & 11* & LVCMOS33 &
    6502 data bit 0. Shared net with SRAM DQ[0]. \\
\sig{D[1]}          & InOut & 12* & LVCMOS33 &
    6502 data bit 1. Shared net with SRAM DQ[1]. \\
\sig{D[2]}          & InOut & 13* & LVCMOS33 &
    6502 data bit 2. Shared net with SRAM DQ[2]. \\
\sig{D[3]}          & InOut & 14* & LVCMOS33 &
    6502 data bit 3. Shared net with SRAM DQ[3]. \\
\sig{D[4]}          & InOut & 15* & LVCMOS33 &
    6502 data bit 4. Shared net with SRAM DQ[4]. \\
\sig{D[5]}          & InOut & 16* & LVCMOS33 &
    6502 data bit 5. Shared net with SRAM DQ[5]. \\
\sig{D[6]}          & InOut & 17* & LVCMOS33 &
    6502 data bit 6. Shared net with SRAM DQ[6]. \\
\sig{D[7]}          & InOut & 18* & LVCMOS33 &
    6502 data bit 7. Shared net with SRAM DQ[7]. \\[2pt]

% --- 6502 control ---
\sig{PHI2}          & In    & 34* & LVCMOS33 &
    6502 phase-2 clock. Synchronised internally; not used as FPGA clock. \\
\sig{RNW}           & In    & 36* & LVCMOS33 &
    Read/Not-Write. High = read, Low = write. \\[2pt]

% --- PBI control ---
\sig{VERA\_CS}      & Out   & 32* & LVCMOS33 &
    VERA chip-select latch output (active low). \\
\sig{MPD}           & Out   & 31* & LVCMOS33 &
    Machine Program Data (active low, \textbf{PBI mode only}).
    Asserted during PBI ROM (\hex{D800}--\hex{DFFF}) reads; blocks
    Atari from driving D[7:0].  Always inactive (high) in CCTL mode. \\
\sig{EXTSEL}        & Out   & 37* & LVCMOS33 &
    External Select (active low).  \textbf{PBI mode:} asserted for
    PBI RAM (\hex{D600}--\hex{D7FF}) and RAMbo (\hex{4000}--\hex{7FFF}).
    \textbf{CCTL mode:} asserted for RAMbo only.  Blocks Atari
    internal RAM from responding. \\[2pt]

% --- Hardware configuration inputs ---
\sig{PBI\_ID\_SEL}  & In    & 27* & LVCMOS33 &
    Hardware jumper to one of D[0..7] on PCB.  Sampled when \hex{D1FF}
    is written (PBI mode only); \texttt{vera\_cs\_latch <= not PBI\_ID\_SEL}.
    Logic~1 on the chosen bit selects VERA, logic~0 deselects.
    Ignored in CCTL build. \\
\sig{RAMBO\_EN}     & In    & 28* & LVCMOS33 &
    Tie to VCC (pullup) to enable RAMbo hardware; tie to GND (pulldown)
    to disable RAMbo completely, overriding PBCTL[2].  Both
    \sig{RAMBO\_EN} and PBCTL[2] must be high for RAMbo to respond. \\[2pt]

% --- External SRAM ---
\sig{SRAM\_A\_BANK[0]} & Out & 19* & LVCMOS33 &
    SRAM address bit 14 (bank LSB). \\
\sig{SRAM\_A\_BANK[1]} & Out & 20* & LVCMOS33 &
    SRAM address bit 15. \\
\sig{SRAM\_A\_BANK[2]} & Out & 21* & LVCMOS33 &
    SRAM address bit 16. \\
\sig{SRAM\_A\_BANK[3]} & Out & 38* & LVCMOS33 &
    SRAM address bit 17 (bank MSB). \\
\sig{SRAM\_CE\_N}   & Out   & 23* & LVCMOS33 &
    SRAM chip enable (active low). Asserted during PHI2-high when
    address is in \hex{4000}--\hex{7FFF} and RAMbo is enabled. \\
\sig{SRAM\_OE\_N}   & Out   & 39* & LVCMOS33 &
    SRAM output enable (active low). Asserted on read cycles only. \\
\sig{SRAM\_WE\_N}   & Out   & 25* & LVCMOS33 &
    SRAM write enable (active low). Asserted on write cycles only.
    Pulse width equals PHI2-high time ($\approx$279\,ns at 1.79\,MHz). \\

\end{longtable}
\end{center}

\textit{* Pin numbers are placeholders.  Replace with actual pad numbers
from your board schematic.}

\subsection{External SRAM address wiring}

The SRAM address bus is split between PCB traces (lower 14 bits) and
FPGA outputs (upper 4 bank bits):

\begin{center}
\begin{tabular}{lll}
\toprule
\textbf{SRAM address bit} & \textbf{Source} & \textbf{Note} \\
\midrule
A[13:0]  & 6502 A[13:0] (PCB net) & Direct trace, no FPGA I/O pin \\
A[14]    & FPGA \sig{SRAM\_A\_BANK[0]} & Bank bit 0 = PORTB[2] \\
A[15]    & FPGA \sig{SRAM\_A\_BANK[1]} & Bank bit 1 = PORTB[3] \\
A[16]    & FPGA \sig{SRAM\_A\_BANK[2]} & Bank bit 2 = PORTB[5] \\
A[17]    & FPGA \sig{SRAM\_A\_BANK[3]} & Bank bit 3 = PORTB[6] \\
A[18]    & GND (PCB)               & Selects lower 256\,KB of 512\,KB chip \\
\bottomrule
\end{tabular}
\end{center}

\subsection{RAMbo bank formula}

The FPGA snoops writes to the Atari PIA to derive the active bank:

\begin{lstlisting}[style=shell]
PORTB at $D301  -- bank bits
PBCTL at $D303  -- bit 2 enables RAMbo

bank[1:0] = PORTB[3:2]
bank[3:2] = PORTB[6:5]
=> SRAM A[17:14] = { PORTB[6], PORTB[5], PORTB[3], PORTB[2] }
\end{lstlisting}

RAMbo is active only when both \sig{RAMBO\_EN} (pin~28 tied to VCC)
and \sig{PBCTL[2] = 1} (software enable written by the Atari OS).

% ===========================================================================
\section{Timing}
% ===========================================================================

\subsection{Read cycle (SRAM)}

\begin{center}
\begin{tabular}{lrl}
\toprule
\textbf{Event} & \textbf{Time from PHI2 rise} & \textbf{Note} \\
\midrule
Address valid (6502 tADS) & $-$40\,ns & Before PHI2 rise \\
SRAM\_CE\# asserted       & $\approx$0\,ns   & Combinational gate on PHI2 \\
SRAM data valid (tAA=55\,ns) & $+$55\,ns & AS6C4008-55 \\
6502 data setup deadline  & $+$249\,ns & 279\,ns $-$ 30\,ns tDSR \\
\textbf{Read margin}      & \textbf{$+$194\,ns} & Adequate \\
\bottomrule
\end{tabular}
\end{center}

\subsection{Write cycle (SRAM)}

WE\# is asserted combinationally when PHI2 is high and the address is
in the RAMbo window.  The pulse width equals the PHI2-high time:

\[
t_{WC} = t_{\text{PHI2-high}} \approx 279\,\text{ns}
\quad \gg \quad
t_{WC(\text{SRAM})} = 55\,\text{ns}
\]

\subsection{PBI RAM / ROM (BRAM)}

BRAM reads are triggered on \cmd{phi2\_rise} (one clock cycle after the
real PHI2 edge, $\approx$40\,ns delay).  The BRAM output is registered
and valid within one additional clock cycle ($\approx$40\,ns), leaving
$\approx$199\,ns of margin before the 6502 samples the bus.

% ===========================================================================
\section{Source File Reference}
% ===========================================================================

\begin{center}
\begin{tabular}{lp{9cm}}
\toprule
\textbf{File} & \textbf{Description} \\
\midrule
\file{C6502\_Interface.vhd} &
    Top-level VHDL entity (Rev~4).  Generic \cmd{VERA\_IS\_PBI}
    selects PBI or CCTL mode at synthesis time.  Contains all bus
    logic, BRAM instances, and SRAM control. \\
\file{custom\_types.vhd} &
    Package defining \cmd{rom\_array} (2048$\times$8) and
    \cmd{ram\_512\_array} (512$\times$8) array types. \\
\file{pbi\_rom\_pkg.vhd} &
    Auto-generated package containing the \cmd{PBI\_ROM\_INIT}
    constant (2048 bytes).  Do not edit manually. \\
\file{gen\_pbi\_rom\_pkg.py} &
    Python~3 script that converts a 6502 \file{.bin} file into
    \file{pbi\_rom\_pkg.vhd}.  Invoked by the MCU Makefile. \\
\file{board-pin-mapping.pcf} &
    Pin constraints for iCE40UP5K SG48.
    All pin numbers are placeholders -- edit before use. \\
\file{Makefile} &
    Targets: \cmd{pbi}, \cmd{cctl}, \cmd{all}, \cmd{flash-pbi},
    \cmd{flash-cctl}, \cmd{flash-pbi-iceprog}, \cmd{flash-cctl-iceprog},
    \cmd{doc}, \cmd{clean}. \\
\bottomrule
\end{tabular}
\end{center}

\end{document}

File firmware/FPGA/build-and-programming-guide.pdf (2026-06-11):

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

VERA RBL-XE FPGA Build & Programming Guide | Rev 4
0 | Contents
1 Overview | 2
2 Prerequisites | 2
3 Build Flow | 4
4 Programmer Wiring | 7
5 Reset Sequencing | 7
6 Pin Assignment | 9
7 Timing | 11
8 Source File Reference | 12

1 Overview

This document describes the complete workow for building and programming the FPGA rmware for the VERA RBL-XE module. The rmware implements a 6502 bus controller on a Lattice iCE40UP5K, replacing the ESP32-S3 MCU used in the previous design.

1.1 | Architecture summary
| PBI RAM ($D600$D7FF, 512 B): stored in iCE40 BRAM (1 EBR block).
| PBI ROM ($D800$DFFF, 2 KB): stored in iCE40 BRAM (4 EBR blocks), pre-loaded at
synthesis time from the assembled 6502 driver binary.
RAMbo ($4000$7FFF, 16 KB window, 256 KB total): served by an external 512K×8 SRAM (e.g. AS6C4008-55SIN). The FPGA controls chip-enable, output-enable, writeenable, and the upper four address bits (bank), using only 7 new I/O pins.
PHI2 synchronisation: PHI2 is treated as a data input and synchronised to the 25 MHz FPGA clock via a two-stage ip-op chain, producing a single-cycle phi2_rise pulse used to trigger all registered logic.
Two bitstreams VERA_IS_PBI generic: the top-level entity exposes a VHDL-2008 boolean generic that selects the bus interface at synthesis time. PBI mode (VERA_IS_PBI=true): latch at $D1FF, PBI RAM and ROM in BRAM (5 EBR blocks), EXTSEL for PBI RAM and RAMbo, MPD for PBI ROM reads. CCTL mode (VERA_IS_PBI=false): latch at $D5FF (write $80 to select, $00 to deselect), no BRAM (Yosys eliminates dead code: 0 EBR), EXTSEL for RAMbo only, MPD always inactive.
Hardware conguration pins: PBI_ID_SEL (pin 27) is wired via PCB jumper to one of D[0..7]; the sampled bit value latches VERA_CS in PBI mode (vera_cs_latch <= not PBI_ID_SEL). RAMBO_EN (pin 28) with pullup (VCC) enables RAMbo; with pulldown (GND) disables it regardless of PBCTL[2].
1.2 | Memory map
Range | Size | Function | Implementation
$4000$7FFF | 16 KB window RAMbo (256 KB banked) External SRAM
$D1FF | 1 B | VERA_CS latch (write) | Register
$D301 | 1 B | PIA PORTB snoop | Register
$D303 | 1 B | PIA PBCTL snoop | Register
$D600$D7FF | 512 B | PBI RAM | BRAM (1 EBR)
$D800$DFFF | 2 KB | PBI ROM | BRAM (4 EBR)

Note (CCTL mode): when built with VERA_IS_PBI=false the VERA_CS latch address changes to $D5FF (write $80 to select, $00 to deselect), and PBI RAM/ROM are absent (0 EBR).

2 | Prerequisites
2.1 | FPGA toolchain

While some tools are available via apt on Debian/Ubuntu, they are often outdated (especially on Debian 11). The recommended way to set up the toolchain is using the OSS CAD Suite, which provides pre-compiled, up-to-date versions of Yosys, nextpnr, GHDL, and all required plugins.

2.1.1 Installing OSS CAD Suite (Recommended for Debian 11)

1. Download the latest Linux x64 archive from: https://github.com/YosysHQ/oss-cad-suite-build/releases/latest

2. Extract the archive (e.g., to $HOME/oss-cad-suite).
3. Add the bin directory to your PATH:

export PATH =" $HOME / oss - cad - suite / bin : $PATH "

This suite includes yosys, nextpnr-ice40, icepack, iceprog, and ghdl with the ghdl-yosys-plugin already integrated.

2.1.2 Alternative: Manual installation via apt (Debian 12+)

On newer distributions, you can try:

sudo apt install fpga - icestorm nextpnr - ice40 yosys ghdl

Note: if installing via apt, you will likely need to build the ghdl-yosys-plugin from source as described below, because it is rarely packaged.

git clone https :// github . com / ghdl / ghdl - yosys - plugin
cd ghdl - yosys - plugin
make
sudo make install

2.2 Flash programming tools

On modern distributions (e.g. Debian 12+), openFPGALoader can be installed via package manager:

sudo apt install openFPGALoader

On older distributions like Debian 11 (Bullseye), the package is not available and must be built from source.

2.2.1 Building openFPGALoader from source

First, install the required dependencies and build tools:

sudo apt install git cmake make g ++ pkg - config libusb -1.0 -0 - dev \
| libhidapi - dev libgpiod - dev libusbmuxd - dev

Then, clone the repository and build the project:

git clone https :// github . com / trabucayre / openfpgaloader cd openfpgaloader
mkdir build
cd build
# Use - DCMAKE_INSTALL_PREFIX = $HOME to install in your home directory # or omit it to install system - wide ( requires sudo make install ) cmake .. - DCMAKE_INSTALL_PREFIX = $HOME

make - j$ ( nproc )
make install

Ensure $HOME/bin is in your PATH if you used the home directory prex.

2.2.2 Iceprog

The iceprog tool is already included in the fpga-icestorm package and supports FTDI-based programmers (e.g. FT2232H).

2.3 6502 assembler (cc65)

The PBI ROM driver is written in 6502 assembly and built with the cc65 toolchain.

sudo apt install cc65

2.4 Python 3

Required to run gen_pbi_rom_pkg.py, which converts the assembled 6502 binary into a VHDL constant package.

sudo apt install python3

2.5 | Tool roles at a glance
Tool | Input | Output | Purpose
ca65 / ld65 | .s sources | .bin | 6502 assembly
gen_pbi_rom_pkg.py | .bin | .vhd | ROM initialisation
ghdl (plugin) | VHDL sources RTLIL | VHDL elaboration
yosys | RTLIL | .json | Synthesis
nextpnr-ice40 | .json + .pcf | .asc | Place & route
icepack | .asc | .bin | Bitstream packing
openFPGALoader | .bin | SPI ash Programming
3 | Build Flow
3.1 | Step 1 Assemble the 6502 ROM driver

The PBI ROM at $D800$DFFF contains a 2 KB 6502 driver assembled from firmware/MCU/6502/src/vera_pbi_handler.s.

cd firmware / MCU /6502
make

Listing 1: Assemble the 6502 driver

This single command runs three sub-steps:

1. Assemble: ca65 compiles vera_pbi_handler.s into vera_pbi_handler.o.
2. Link: ld65 links with pbi-driver.ld to produce vera_pbi_handler.bin.
3. Generate VHDL ROM package: gen_pbi_rom_pkg.py reads the binary and writes ../../FPGA/pbi_rom_pkg.vhd with the PBI_ROM_INIT constant.

To regenerate only the VHDL package when the binary already exists:

make fpga - rom

3.2 Step 2 Synthesis

The top-level entity exposes a VHDL-2008 boolean generic, VERA_IS_PBI (default true), that selects the bus interface at synthesis time. The Makele invokes Yosys twice, producing two independent bitstreams from the same source:

cd firmware / FPGA
yosys -m ghdl -p \
| " ghdl -- std =08 - gVERA_IS_PBI = true \ custom_types . vhd pbi_rom_pkg . vhd C6502_Interface . vhd \ -e C6502_Interface ; \ synth_ice40 - top C6502_Interface - json C6502_Interface_PBI . json "
| Listing 2: PBI synthesis (VERA_IS_PBI=true)

yosys -m ghdl -p \
" ghdl -- std =08 - gVERA_IS_PBI = false \
custom_types . vhd pbi_rom_pkg . vhd C6502_Interface . vhd \
-e C6502_Interface ; \
synth_ice40 - top C6502_Interface - json C6502_Interface_CCTL . json "

Listing 3: CCTL synthesis (VERA_IS_PBI=false)

The -m ghdl ag loads the GHDL plugin into Yosys, which handles VHDL analysis and elaboration. When VERA_IS_PBI=false, Yosys eliminates all PBI RAM/ROM dead code, reducing resource usage dramatically. Measured values after place-and-route with nextpnr-ice40:

Resource | PBI | CCTL | Available % (PBI)
ICESTORM_LC (total) | 87 | 1 | 5280 | 1%
of which LUT4 only | 52 | 1
of which LUT4+DFF | 5 | 0
of which DFF only | 5 | 0
of which CARRY only | 21 | 0
ICESTORM_RAM (EBR) | 5 | 0 | 30 | 16%
SB_IO (I/O buers) | 39 | 39 | 39 | 100%
ICESTORM_SPRAM | 0 | 0 | 4 | 0%
Fmax (CLK) | 62.72 MHz (PBI, PASS at 25 MHz)

I/O budget note: the iCE40UP5K-SG48 exposes exactly 39 user I/O pins, and this design uses all 39. The mode selection (PBI vs. CCTL) is compiled into the bitstream via VERA_IS_PBI rather than being a runtime input, freeing the two former DIP_SEL pins for dedicated hardware functions: PBI_ID_SEL (pin 27) and RAMBO_EN (pin 28).

3.3 Step 3 Place & Route

Place & route assigns logic cells and routes signals to physical iCE40 resources, guided by the pin constraints le.

nextpnr - ice40 -- up5k -- package sg48 \
-- json C6502_Interface_PBI . json \ -- pcf board - pin - mapping . pcf \
-- asc C6502_Interface_PBI . asc

Listing 4: Place & route with nextpnr-ice40 (PBI example)

The CCTL build uses the same command with _CCTL lename suxes.

Important: all pin numbers in board-pin-mapping.pcf are placeholders. Edit the le to match your actual schematic before this step (see Section 6).

nextpnr reports timing after routing. Measured results:

Path type | Description | Worst delay
CLK → CLK | Registered path (Fmax) | 15.94 ns (62.72 MHz)
async → async Combinational (PHI2 gate) | 28.12 ns
async → CLK | Input setup time | 26.89 ns
CLK → async | Clock-to-output | 17.17 ns

The 25 MHz system clock (period 40 ns) has 24.06 ns of slack on the registered path. The combinational PHI2-gated outputs settle in at most 28.12 ns after address/control inputs change well within the 6502 PHI2-high window of ≈279 ns at 1.79 MHz.

3.4 Step 4 Pack the bitstream

icepack converts the ASCII intermediate format produced by nextpnr into the binary bitstream that is written to the SPI ash.

icepack C6502_Interface_PBI . asc C6502_Interface_PBI . bin
icepack C6502_Interface_CCTL . asc C6502_Interface_CCTL . bin

Listing 5: Pack binary bitstreams

The .bin le is what gets programmed into the SPI ash. Bitstream size is device-dependent (not design-dependent) on the iCE40: both bitstreams measure ≈104 KB (iCE40UP5K SG48).

3.5 Step 5 Program the SPI ash

The iCE40UP5K loads its conguration from an external SPI NOR ash at power-up. The programmer writes the bitstream into that ash.

3.5.1 Using openFPGALoader (recommended)

# PBI bitstream ( PBI connector , $D1xx )

openFPGALoader -b ice40_generic C6502_Interface_PBI . bin # CCTL bitstream ( cartridge port , $D5xx )
openFPGALoader -b ice40_generic C6502_Interface_CCTL . bin

Listing 6: Program with openFPGALoader

Select the programmer cable explicitly if needed:

openFPGALoader -- cable ft2232 | C6502_Interface_PBI . bin | # FTDI
FT2232H
openFPGALoader -- cable ft232 | C6502_Interface_PBI . bin | # FTDI
FT232H
openFPGALoader -- cable tigard | C6502_Interface_PBI . bin | # Tigard
openFPGALoader -- cable raspberrypi C6502_Interface_PBI . bin | #
Raspberry Pi GPIO

3.5.2 | Using iceprog (FTDI FT2232H)
iceprog C6502_Interface_PBI . bin | # PBI bitstream
iceprog C6502_Interface_CCTL . bin | # CCTL bitstream

# Erase + write ( useful if previous write was partial ) iceprog -e 1048576 C6502_Interface_PBI . bin

Listing 7: Program with iceprog

3.6 One-command build and ash

The firmware/FPGA/Makefile wraps all steps:

cd firmware / FPGA
make pbi | # synthesise + P & R + pack ->
C6502_Interface_PBI . bin
make cctl | # synthesise + P & R + pack ->
C6502_Interface_CCTL . bin
make | # build both ( default )
make flash - pbi | # write PBI | bitstream via openFPGALoader
make flash - cctl | # write CCTL bitstream via openFPGALoader
make flash - pbi - iceprog | # write PBI | via iceprog ( FTDI FT2232H )
make flash - cctl - iceprog | # write CCTL via iceprog
make doc | # regenerate PDF documentation
make clean | # remove all generated files
4 | Programmer Wiring

The SPI ash is shared between the FPGA (conguration bus at boot) and the programmer (writes the bitstream). During programming, the FPGA is held in reset by asserting CRESET_B low.

Programmer signal iCE40UP5K pin | SPI ash pin
MOSI | SPI_SI | DI
MISO | SPI_SO | DO
SCK | SPI_SCK | CLK
CS# | | CS#
CRST# | CRESET_B |
CDONE | CDONE |

Recommended SPI ash: Winbond W25Q16 (2 MB) or W25Q32 (4 MB).

5 Reset Sequencing

The VERA RBL-XE module requires a dened power-on boot sequence: the Atari computer and the VERA graphics chip must remain in reset until all FPGA congurations have completed. This is implemented with a single 74LVC1G08 logic gate no MCU or rmware is needed.

5.1 Boot sequence

1. Power-on: both VERA_RESET# and ATARI_RESET# are held low.
2. FPGA ready (FPGA_CDONE goes high, ≈50100 ms after power-on): VERA_RESET# is released, allowing VERA to start loading its own bitstream from its SPI ash.

3. VERA ready (VERA_CDONE goes high, ≈200500 ms later): ATARI_RESET# is released and the Atari boots normally.

The natural SPI ash loading times provide all necessary delays; no RC timer or additional delay circuit is required.

5.2 | Logic
Signal | Boolean expression
VERA_RESET# | FPGA_CDONE
ATARI_RESET# | FPGA_CDONE AND VERA_CDONE
FPGA_CDONE | VERA_CDONE | VERA_RST# | ATARI_RST# | Phase
0 | 0 | 0 | 0 | Power-on / FPGA
| | | | loading
1 | 0 | 1 | 0 | FPGA ready, VERA
| | | | loading
1 | 1 | 1 | 1 | System ready
5.3 | Circuit 74LVC1G08 (SOT-23-5)

A single 74LVC1G08 (2-input AND gate, SOT-23-5) implements ATARI_RESET#. VERA_RESET# connects directly from FPGA_CDONE through a 33 Ω series resistor.

VCC - -[4 k7 ] - -+ - - - - - - - - FPGA_CDONE ( open - drain )
+ - -[33 R ] - VERA_RESET # |
+ - - A -\
+ - - - 74 LVC1G08 - - -[33 R ] - - - ATARI_RESET # + - - B -/
VCC - -[4 k7 ] - -+ - - - - - - - - VERA_CDONE ( open - drain )

Both CDONE outputs are open-drain; they require an external pullup to VCC. The 33 Ω series resistors limit current if an external driver (e.g. the Atari RESET button, which pulls the line to GND via an open-collector circuit) conicts with the 74LVC output.

Why 74LVC and not 74HC? The 74LVC family has 5 V tolerant inputs while operating at 3.3 V VCC. The CDONE signals are at 3.3 V; the Atari RESET line belongs to a 5 V TTL system. The 74LVC output at 3.3 V is correctly recognised as HIGH by 5 V TTL logic (VIH = 2.0 V). The 74HC family is not suitable for this mixed-voltage interface.

5.4 | Bill of materials
Ref | Value | Package | Function
U1 | 74LVC1G08 SOT-23-5 2-input AND gate
R1 | 4.7 kΩ | 0402 | Pullup | | for
FPGA_CDONE
R2 | 4.7 kΩ | 0402 | Pullup | | for
VERA_CDONE
R3 | 33 Ω | 0402 | Series | resistor | on
VERA_RESET#
R4 | 33 Ω | 0402 | Series | resistor | on
ATARI_RESET#

Total cost under 0.30 EUR; no rmware required.

6 Pin Assignment

Edit board-pin-mapping.pcf and replace every pin number with the actual pad number from your schematic before running nextpnr-ice40.

The CLK signal must be assigned to a Global Buer (GB) input pin. Valid GB pins on the iCE40UP5K SG48 package are: 20, 28, 31, 38, 41, 43, 48.

Valid user I/O pin numbers for SG48 (39 total):

2, 3, 4, 6, 9, 10, 11, 12, 13, 14, 15, 16, 17, 18, 19, 20, 21,
23, 25, 26, 27, 28, 31, 32, 34, 35, 36, 37, 38, 39,
40, 41, 42, 43, 44, 45, 46, 47, 48

Pins 1, 5, 7, 8, 22, 24, 29, 30, 33 are power/ground or reserved and must not appear in the PCF le nextpnr rejects them with an error.

6.1 | Complete pin table
Signal | Dir | PCF pin | Std | Description
CLK | In | 35* | LVCMOS33 | 25 MHz system clock. Must land on
| | | | a GB pin.
A[0] | In | 40* | LVCMOS33 | 6502 address bit 0
A[1] | In | 41* | LVCMOS33 | 6502 address bit 1
A[2] | In | 42* | LVCMOS33 | 6502 address bit 2
A[3] | In | 43* | LVCMOS33 | 6502 address bit 3
A[4] | In | 44* | LVCMOS33 | 6502 address bit 4
A[5] | In | 45* | LVCMOS33 | 6502 address bit 5
A[6] | In | 46* | LVCMOS33 | 6502 address bit 6
A[7] | In | 47* | LVCMOS33 | 6502 address bit 7
A[8] | In | 48* | LVCMOS33 | 6502 address bit 8
A[9] | In | 6* | LVCMOS33 | 6502 address bit 9
A[10] | In | 2* | LVCMOS33 | 6502 address bit 10
A[11] | In | 3* | LVCMOS33 | 6502 address bit 11
A[12] | In | 4* | LVCMOS33 | 6502 address bit 12
A[13] | In | 26* | LVCMOS33 | 6502 address bit 13. Also wired to
SRAM A[13] on PCB.
A[14] | In | 9* | LVCMOS33 | 6502 address bit 14
A[15] | In | 10* | LVCMOS33 | 6502 address bit 15

continued on next page

Signal | Dir | PCF pin | Std | Description
D[0] | InOut | 11* | LVCMOS33 | 6502 data bit 0. Shared net with
SRAM DQ[0].
D[1] | InOut | 12* | LVCMOS33 | 6502 data bit 1. Shared net with
SRAM DQ[1].
D[2] | InOut | 13* | LVCMOS33 | 6502 data bit 2. Shared net with
SRAM DQ[2].
D[3] | InOut | 14* | LVCMOS33 | 6502 data bit 3. Shared net with
SRAM DQ[3].
D[4] | InOut | 15* | LVCMOS33 | 6502 data bit 4. Shared net with
SRAM DQ[4].
D[5] | InOut | 16* | LVCMOS33 | 6502 data bit 5. Shared net with
SRAM DQ[5].
D[6] | InOut | 17* | LVCMOS33 | 6502 data bit 6. Shared net with
SRAM DQ[6].
D[7] | InOut | 18* | LVCMOS33 | 6502 data bit 7. Shared net with
SRAM DQ[7].
PHI2 | In | 34* | LVCMOS33 | 6502 phase-2 clock. Synchronised
internally; not used as FPGA clock.
RNW | In | 36* | LVCMOS33 | Read/Not-Write. High = read, Low
= write.
VERA_CS | Out | 32* | LVCMOS33 | VERA chip-select latch output (ac-
tive low).
MPD | Out | 31* | LVCMOS33 | Machine Program Data (active low,
PBI mode only). Asserted during PBI ROM ($D800$DFFF) reads; blocks Atari from driving D[7:0]. Always inactive (high) in CCTL mode.
EXTSEL | Out | 37* | LVCMOS33 | External | Select | (active | low).
PBI mode: | asserted for PBI
RAM ($D600$D7FF) and RAMbo
($4000$7FFF). | CCTL | mode:
asserted for RAMbo only. Blocks Atari internal RAM from responding.
PBI_ID_SEL | In | 27* | LVCMOS33 | Hardware | jumper | to | one | of
D[0..7] on PCB. Sampled when
$D1FF | is | written | (PBI | mode
only); | vera_cs_latch <= not
PBI_ID_SEL. Logic 1 on the chosen bit selects VERA, logic 0 deselects. Ignored in CCTL build.
RAMBO_EN | In | 28* | LVCMOS33 | Tie to VCC (pullup) to enable
RAMbo hardware; tie to GND (pulldown) to disable RAMbo completely, overriding PBCTL[2]. Both RAMBO_EN and PBCTL[2] must be high for RAMbo to respond.
SRAM_A_BANK[0] | Out | 19* | LVCMOS33 | SRAM address bit 14 (bank LSB).
SRAM_A_BANK[1] | Out | 20* | LVCMOS33 | SRAM address bit 15.
SRAM_A_BANK[2] | Out | 21* | LVCMOS33 | SRAM address bit 16.
SRAM_A_BANK[3] | Out | 38* | LVCMOS33 | SRAM address bit 17 (bank MSB).
SRAM_CE_N | Out | 23* | LVCMOS33 | SRAM chip enable (active low). As-
serted during PHI2-high when address is in $4000$7FFF and RAMbo
| | | | is enabled.

continued on next page

Signal | Dir | PCF pin | Std | Description
SRAM_OE_N | Out | 39* | LVCMOS33 | SRAM output enable (active low).
| | | | Asserted on read cycles only.
SRAM_WE_N | Out | 25* | LVCMOS33 | SRAM write enable (active low).
| | | | Asserted on write cycles only.
| | | | Pulse width equals PHI2-high time
| | | | (≈279 ns at 1.79 MHz).

* Pin numbers are placeholders. Replace with actual pad numbers from your board schematic.

6.2 External SRAM address wiring

The SRAM address bus is split between PCB traces (lower 14 bits) and FPGA outputs (upper 4 bank bits):

SRAM address bit | Source | Note
A[13:0] | 6502 A[13:0] (PCB net) | Direct trace, no FPGA I/O pin
A[14] | FPGA SRAM_A_BANK[0] Bank bit 0 = PORTB[2]
A[15] | FPGA SRAM_A_BANK[1] Bank bit 1 = PORTB[3]
A[16] | FPGA SRAM_A_BANK[2] Bank bit 2 = PORTB[5]
A[17] | FPGA SRAM_A_BANK[3] Bank bit 3 = PORTB[6]
A[18] | GND (PCB) | Selects lower 256 KB of 512 KB chip
6.3 | RAMbo bank formula

The FPGA snoops writes to the Atari PIA to derive the active bank:

PORTB at $D301 | -- bank bits
PBCTL at $D303 | -- bit 2 enables RAMbo

bank [1:0] = PORTB [3:2]
bank [3:2] = PORTB [6:5]
= > SRAM A [17:14] = { PORTB [6] , PORTB [5] , PORTB [3] , PORTB [2] }

RAMbo is active only when both RAMBO_EN (pin 28 tied to VCC) and PBCTL[2] = 1 (software enable written by the Atari OS).

7 | Timing
7.1 | Read cycle (SRAM)
Event | Time from PHI2 rise | Note
Address valid (6502 tADS) | −40 ns Before PHI2 rise
SRAM_CE# asserted | ≈0 ns Combinational gate on PHI2
SRAM data valid (tAA=55 ns) | +55 ns AS6C4008-55
6502 data setup deadline | +249 ns 279 ns − 30 ns tDSR
Read margin | +194 ns | Adequate

7.2 Write cycle (SRAM)

WE# is asserted combinationally when PHI2 is high and the address is in the RAMbo window. The pulse width equals the PHI2-high time:

tW C = tPHI2-high ≈ 279 ns | | tW C(SRAM) = 55 ns
7.3 | PBI RAM / ROM (BRAM)

BRAM reads are triggered on phi2_rise (one clock cycle after the real PHI2 edge, ≈40 ns delay). The BRAM output is registered and valid within one additional clock cycle (≈40 ns), leaving ≈199 ns of margin before the 6502 samples the bus.

8 | Source File Reference
File | Description
C6502_Interface.vhd | Top-level VHDL entity (Rev 4). Generic VERA_IS_PBI
selects PBI or CCTL mode at synthesis time. Contains all bus logic, BRAM instances, and SRAM control.
custom_types.vhd | Package | dening | rom_array | (2048×8) | and
ram_512_array (512×8) array types.
pbi_rom_pkg.vhd | Auto-generated package containing the PBI_ROM_INIT
constant (2048 bytes). Do not edit manually. gen_pbi_rom_pkg.py Python 3 script that converts a 6502 .bin le into pbi_rom_pkg.vhd. Invoked by the MCU Makele. board-pin-mapping.pcf Pin constraints for iCE40UP5K SG48. All pin numbers are placeholders edit before use.
Makefile | Targets: pbi, cctl, all, flash-pbi, flash-cctl,
flash-pbi-iceprog, | flash-cctl-iceprog, | doc,
| clean.
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

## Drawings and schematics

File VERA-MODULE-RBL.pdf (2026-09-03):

## Sheet: VeraModule

## Sheet: BusDecoder

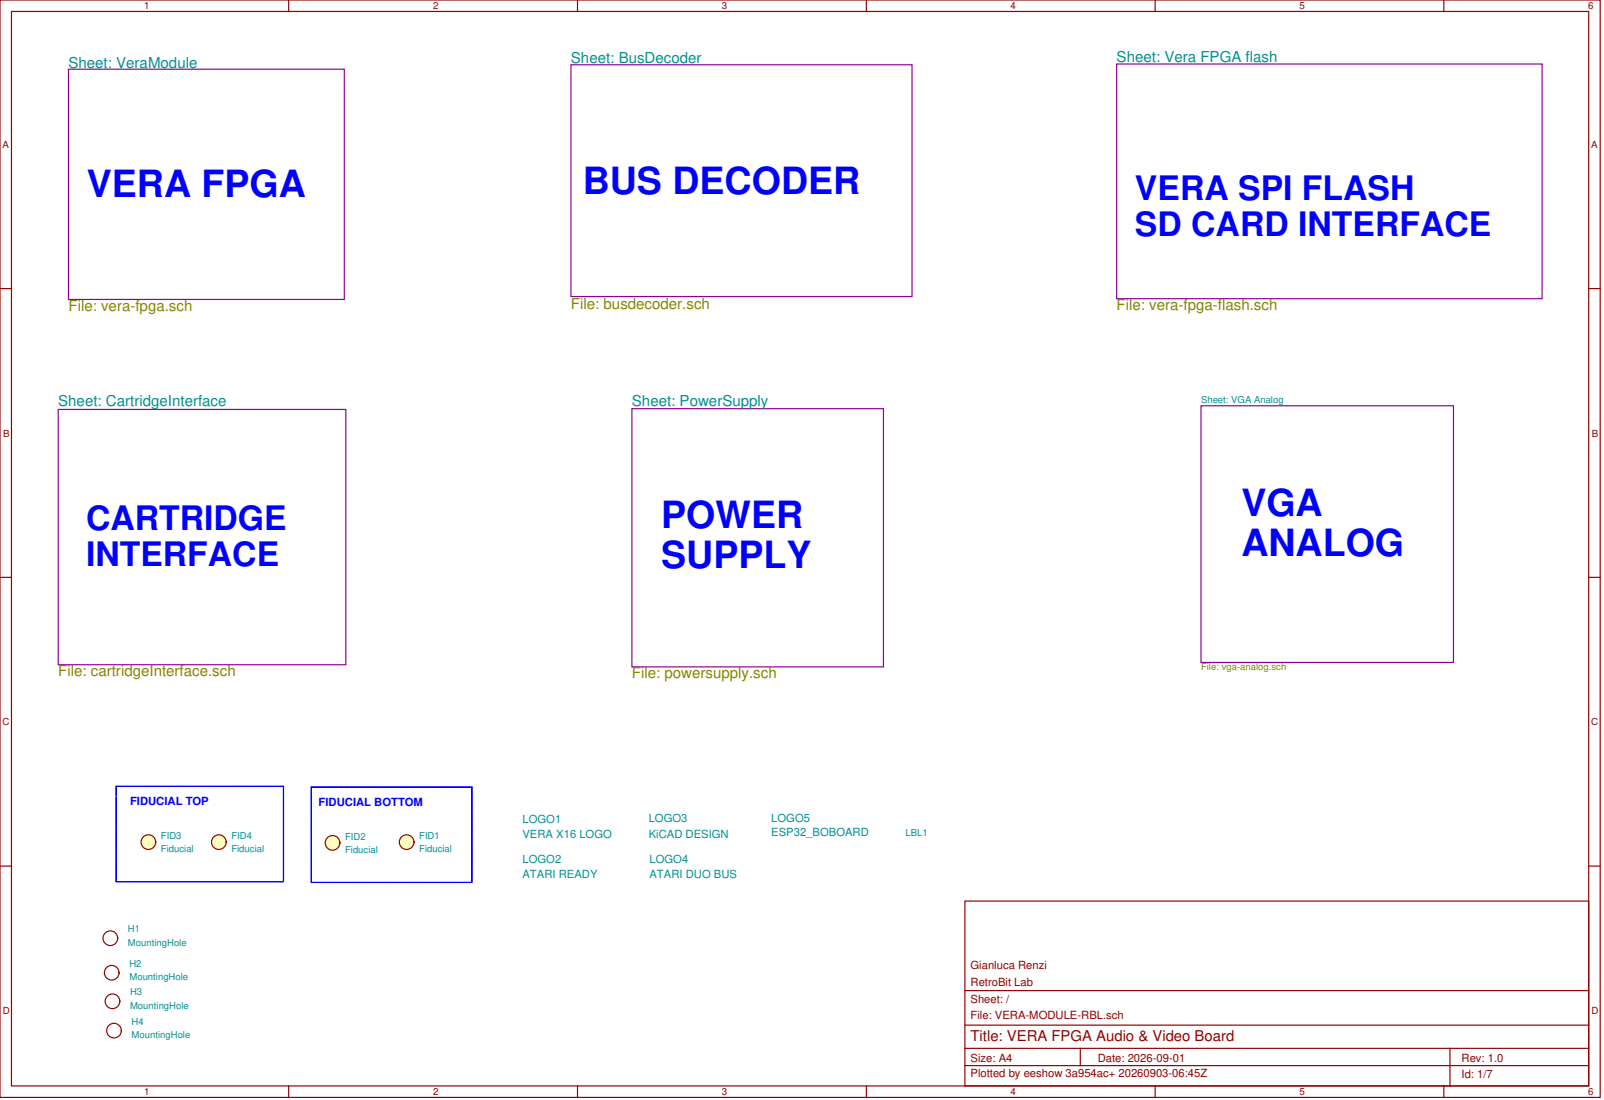
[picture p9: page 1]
Size: A4; Rev: 1.0; Date: 2026-09-01; Sheet: CartridgeInterface; Sheet: PowerSupply; Fiducial; FID3; FID4; FID2; FID1; VERA X16 LOGO; LOGO1; ATARI READY; LOGO2; KiCAD DESIGN; LOGO3; ESP32_BOBOARD; LOGO5; LBL1; MountingHole; VERA FPGA; BUS DECODER; CARTRIDGE INTERFACE; POWER SUPPLY; FIDUCIAL TOP; FIDUCIAL BOTTOM; VGA ANALOG

Sheet: Vera FPGA flash

VERA SPI FLASH
SD CARD INTERFACE

File: vera-fpga.sch

File: busdecoder.sch

File: vera-fpga-flash.sch

Sheet: VGA Analog

File: cartridgeInterface.sch

File: powersupply.sch

File: vga-analog.sch

LOGO4
ATARI DUO BUS

Gianluca Renzi
RetroBit Lab
Sheet: /
File: VERA-MODULE-RBL.sch
Title: VERA FPGA Audio & Video Board

Plotted by eeshow 3a954ac+ 20260903-06:45Z

# IOT_43a 32 VCCIO_0 33

# FPGA VERA LOGIC VIDEO & AUDIO CARD

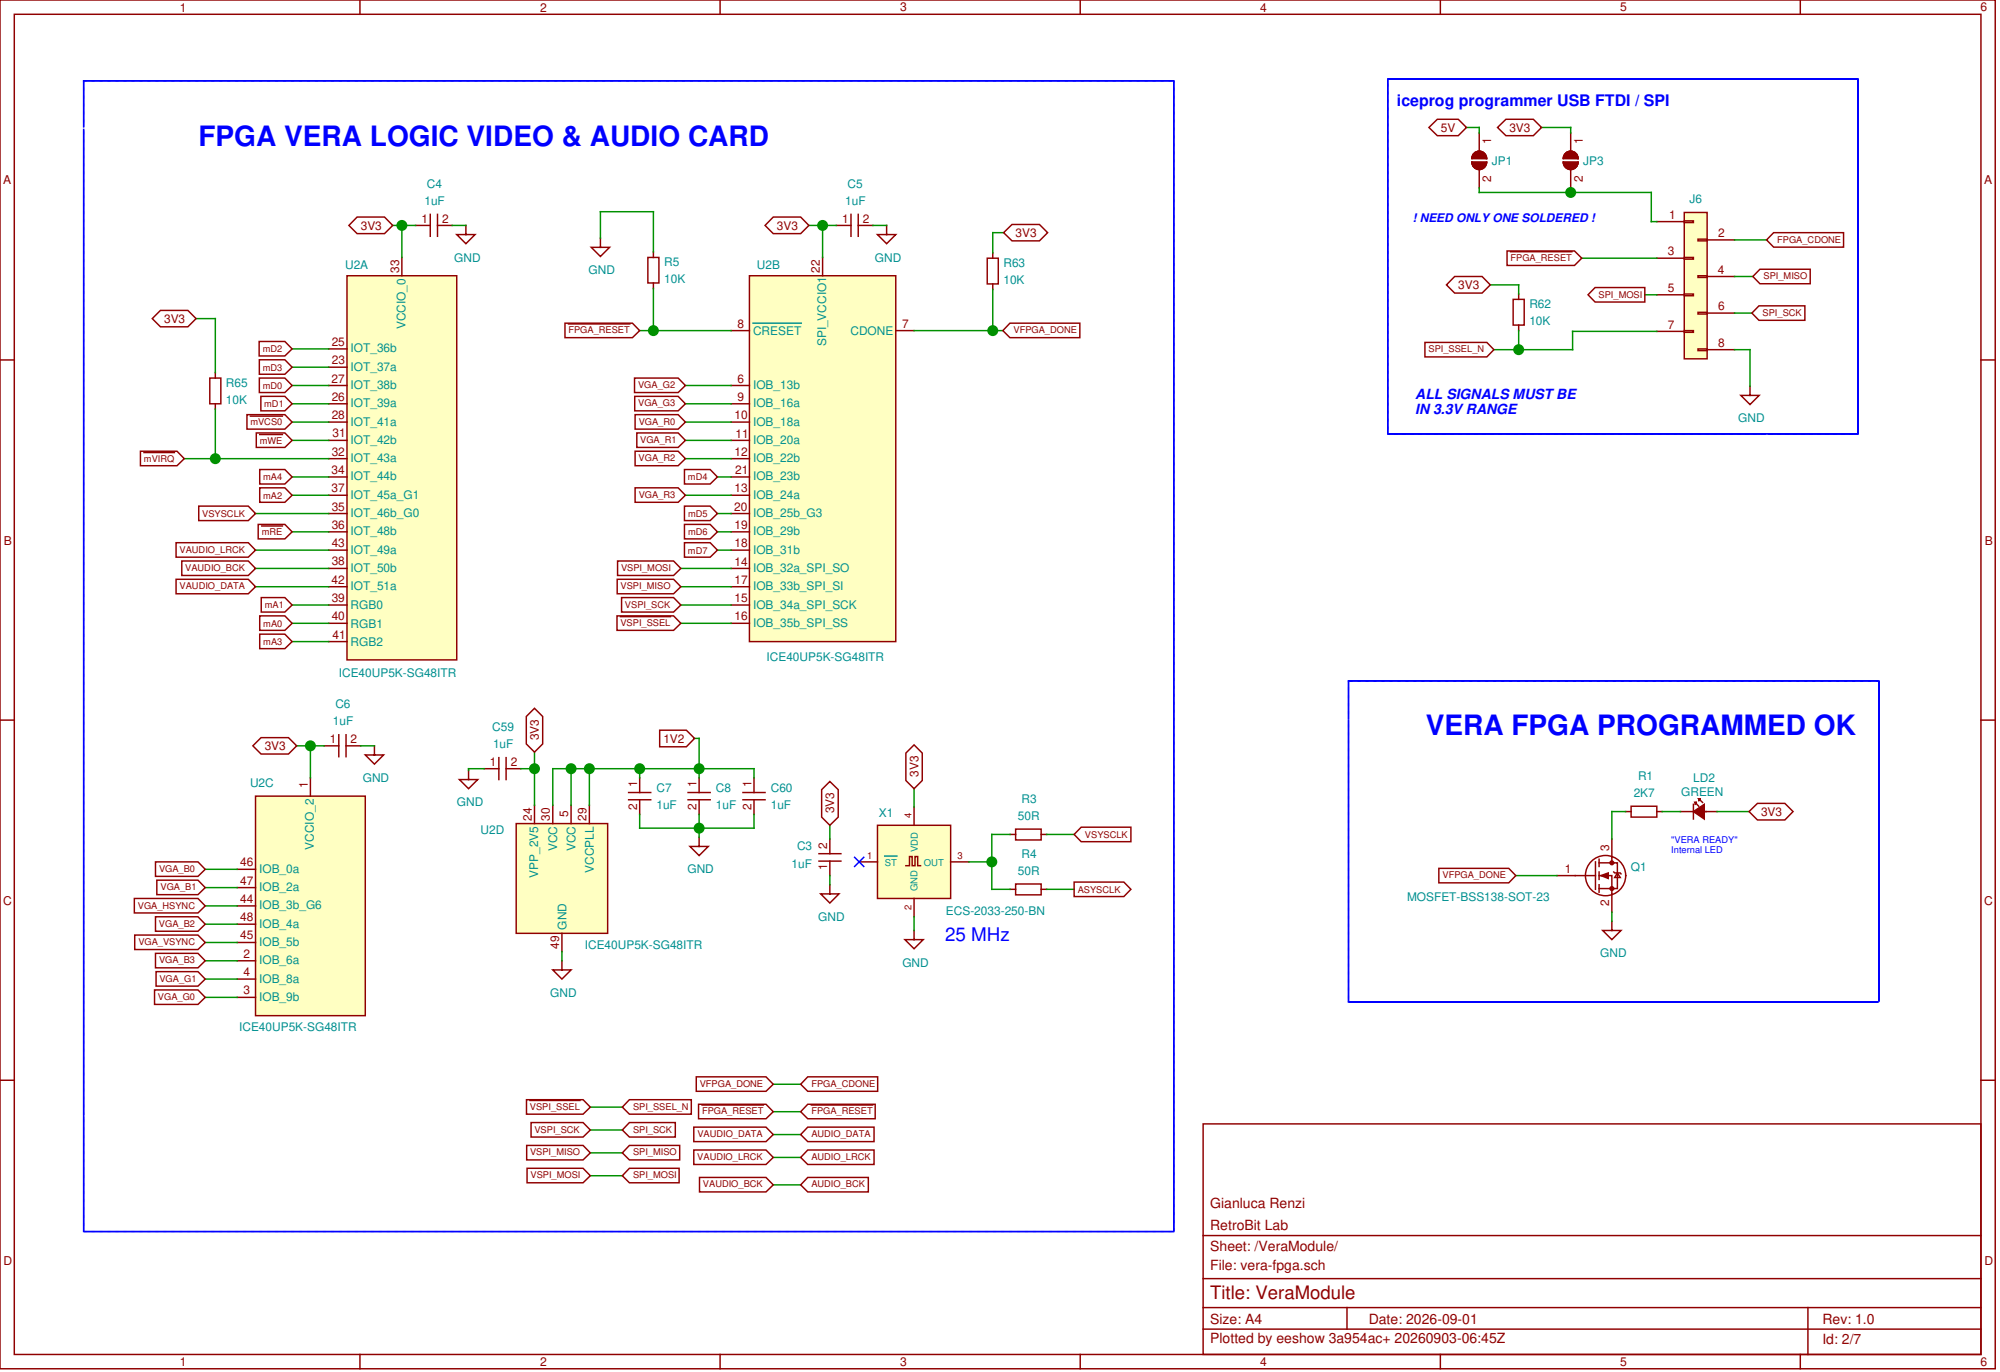
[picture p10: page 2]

iceprog programmer USB FTDI / SPI

! NEED ONLY ONE SOLDERED !

ALL SIGNALS MUST BE
IN 3.3V RANGE

VERA FPGA PROGRAMMED OK

Gianluca Renzi
RetroBit Lab
Sheet: /VeraModule/
File: vera-fpga.sch
Title: VeraModule

# PBI DEVICE ID: software selectable only

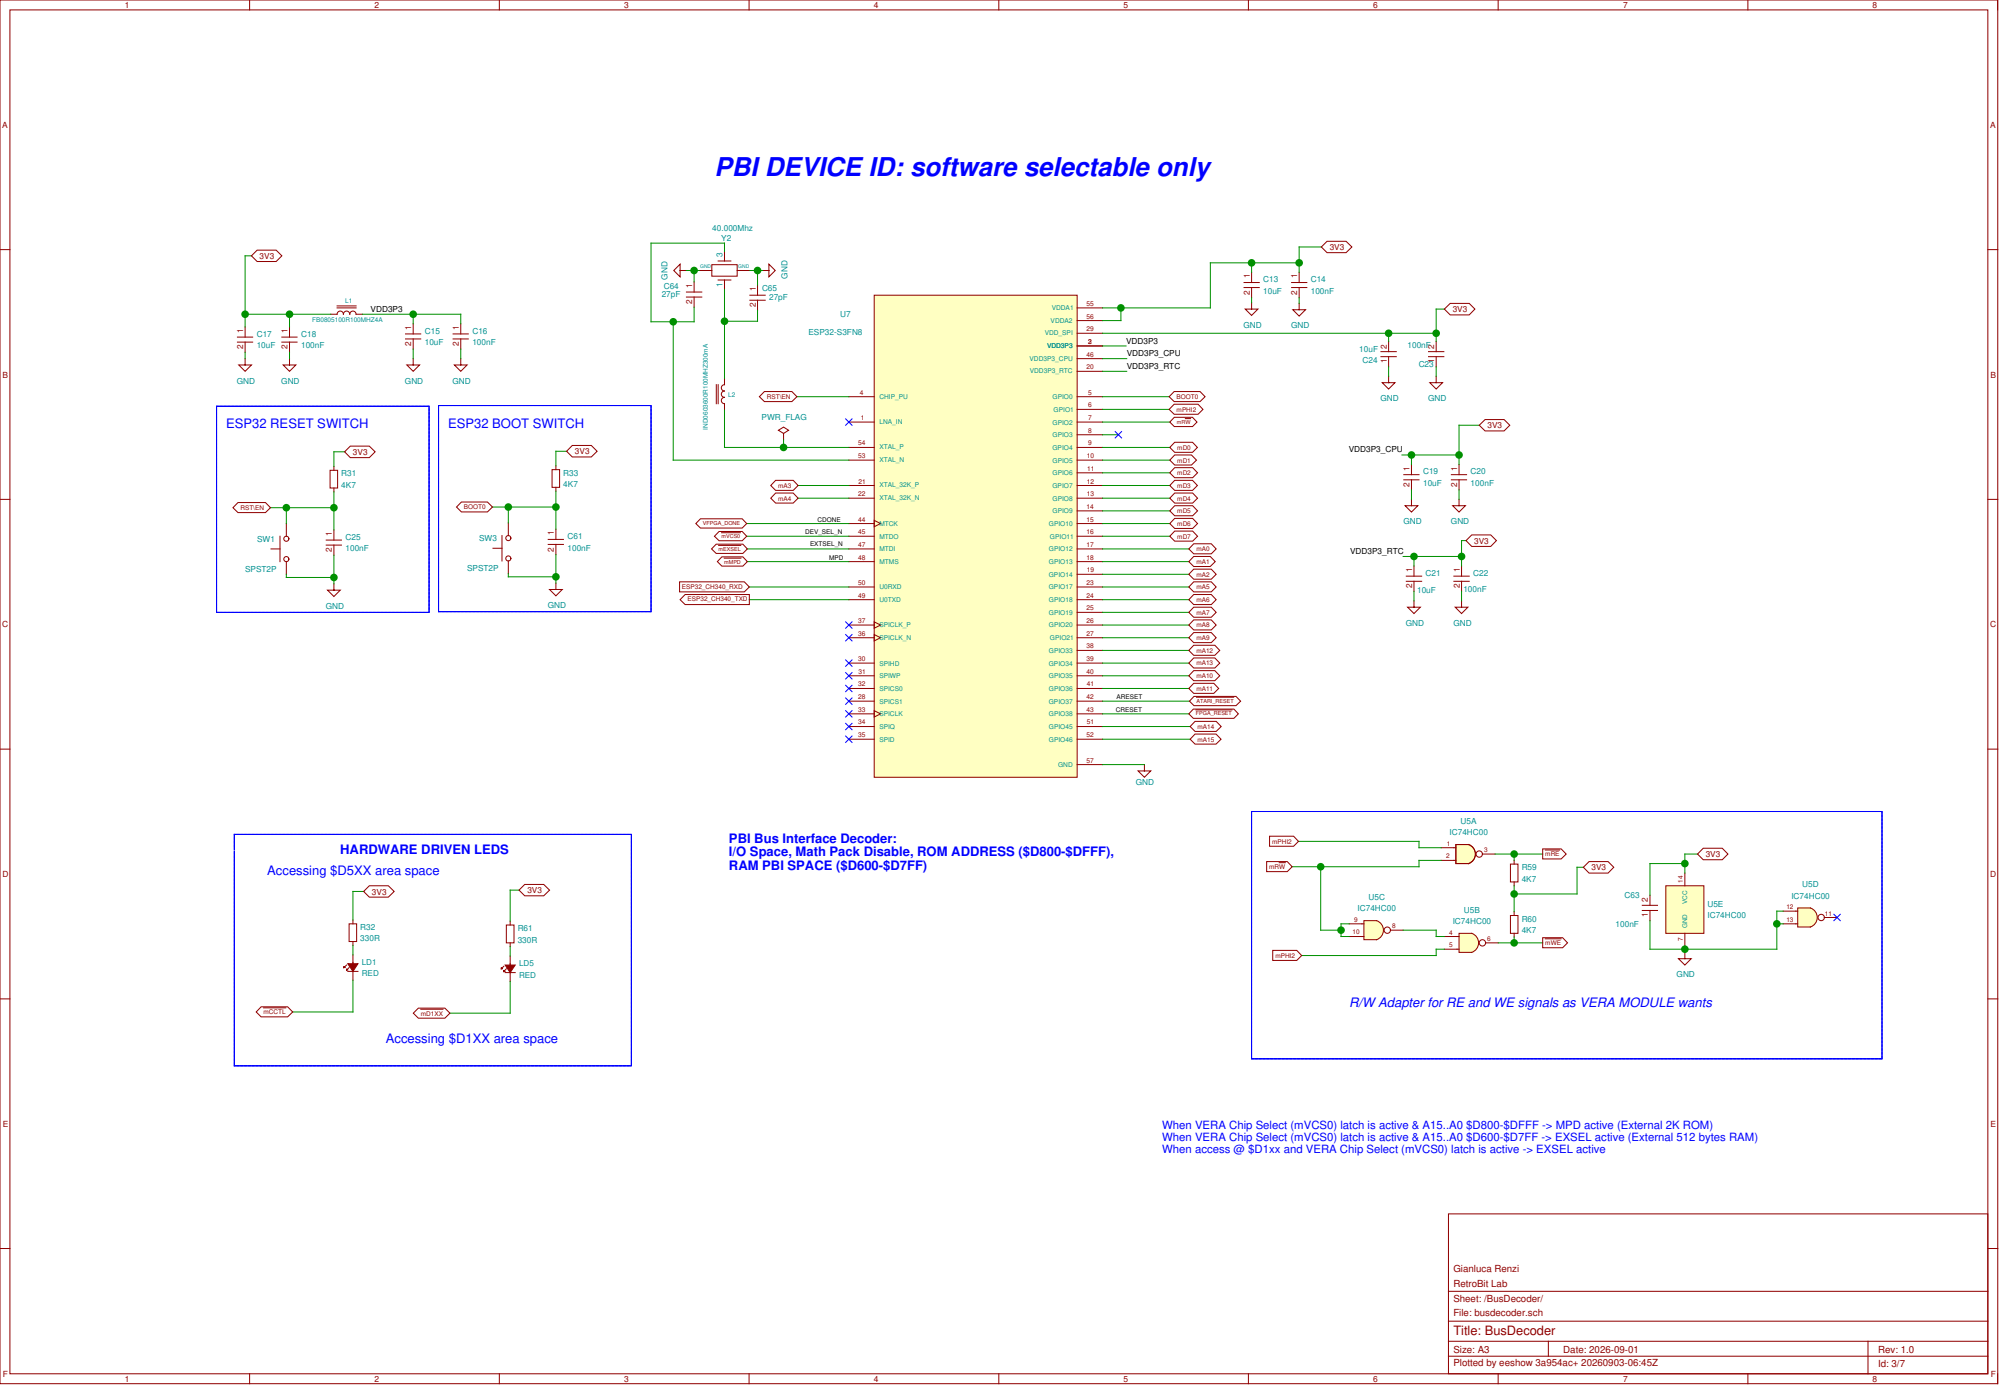
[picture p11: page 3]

PBI Bus Interface Decoder:
I/O Space, Math Pack Disable, ROM ADDRESS ($D800-$DFFF),
RAM PBI SPACE ($D600-$D7FF)

R/W Adapter for RE and WE signals as VERA MODULE wants

When VERA Chip Select (mVCS0) latch is active & A15..A0 $D800-$DFFF -> MPD active (External 2K ROM)
When VERA Chip Select (mVCS0) latch is active & A15..A0 $D600-$D7FF -> EXSEL active (External 512 bytes RAM)
When access @ $D1xx and VERA Chip Select (mVCS0) latch is active -> EXSEL active

# ATARI 130XE ECI & CARTRIDGE INTERFACE

## All 8-Bit signals must be shifted from 5V to 3.3V and vice versa

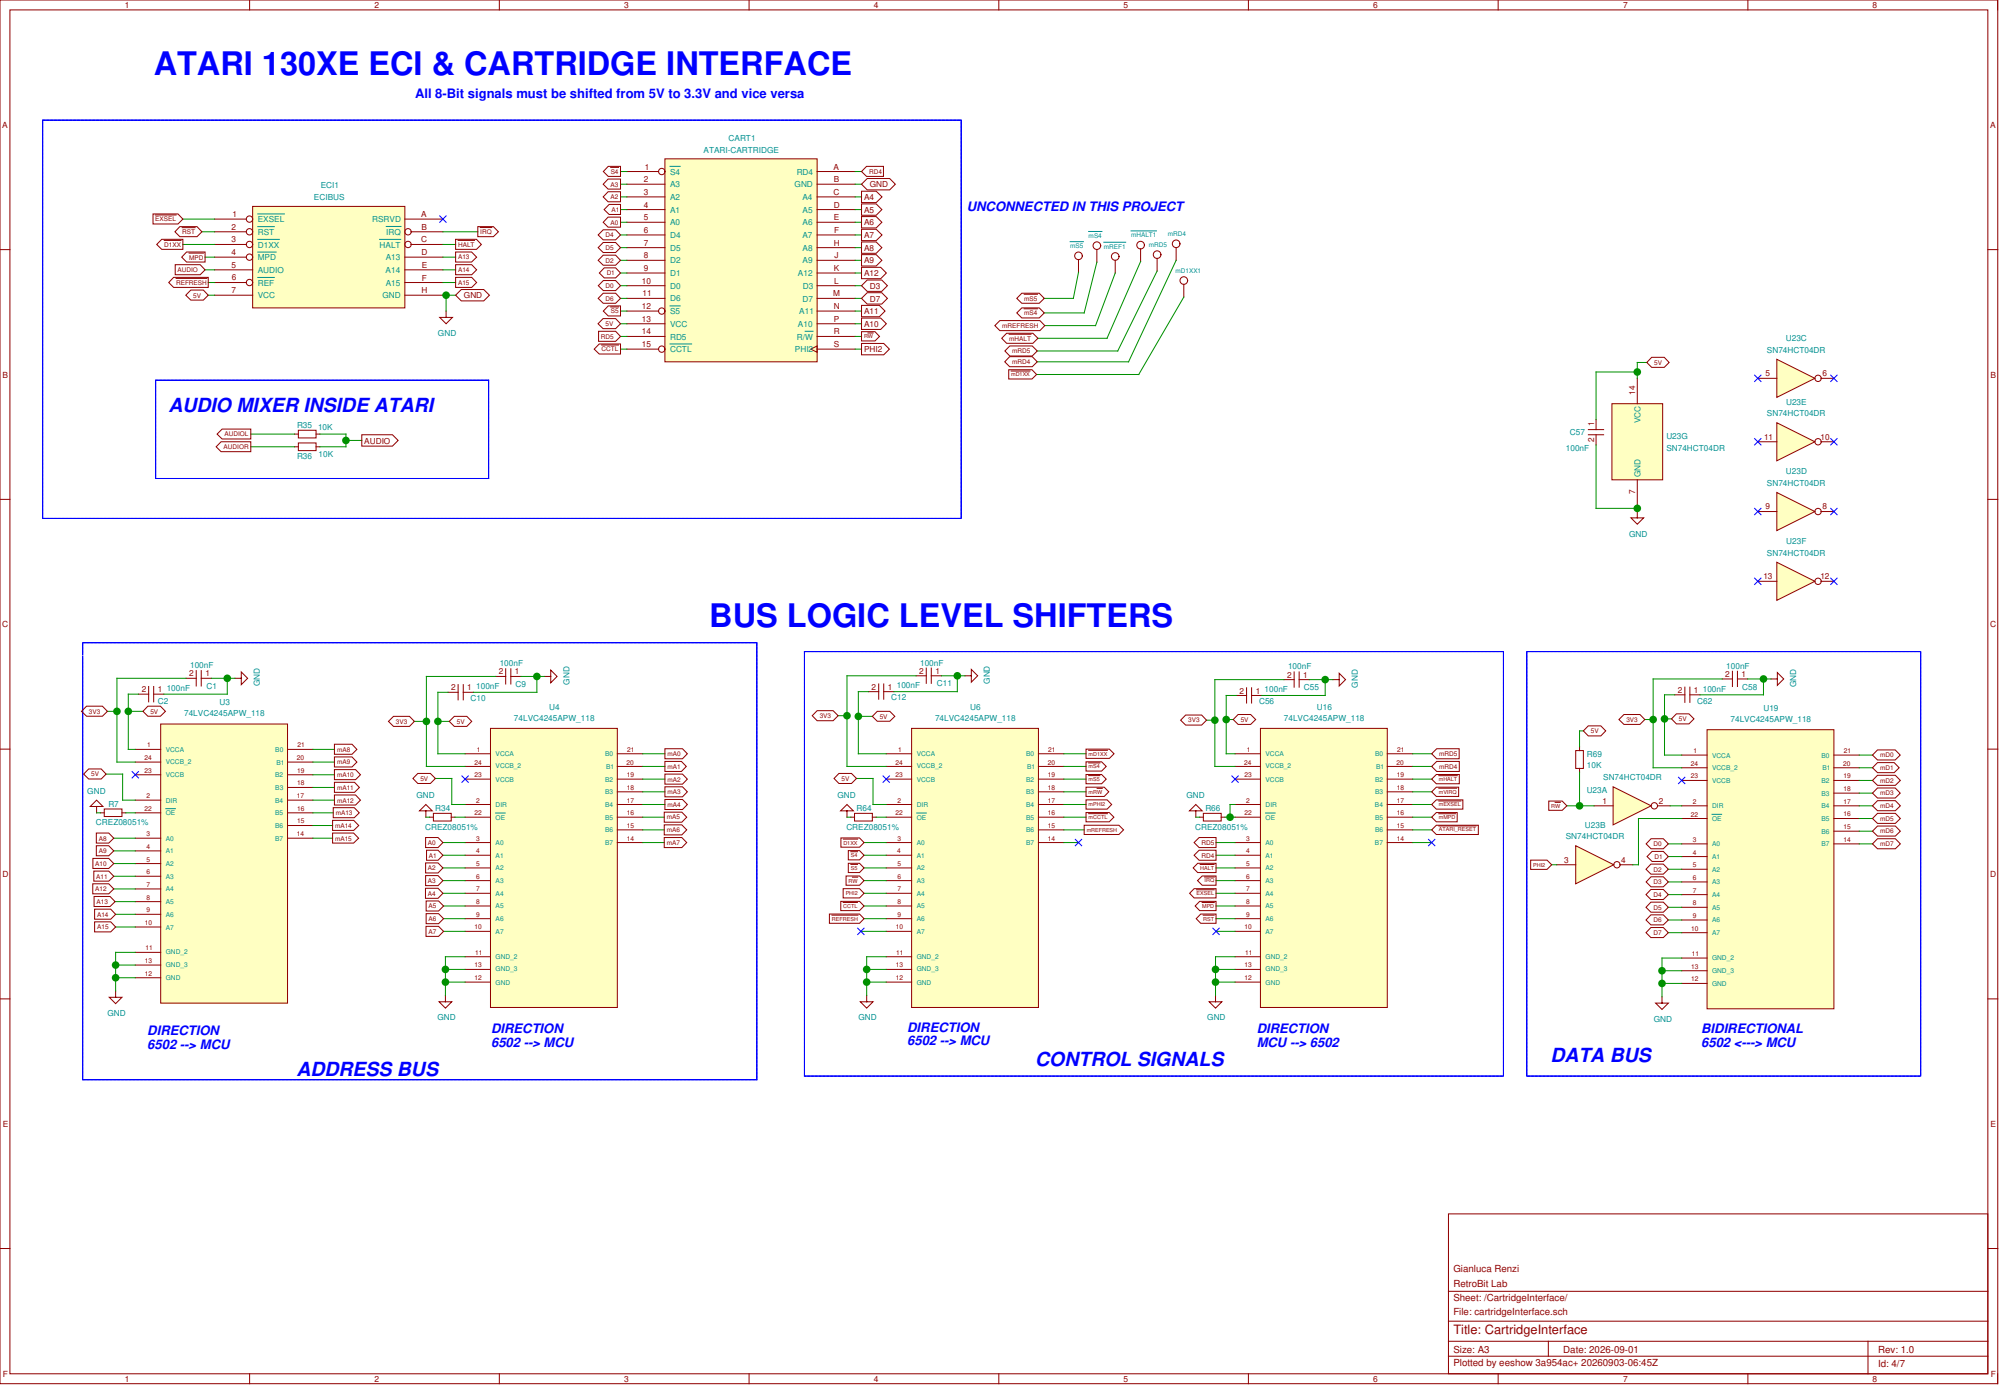
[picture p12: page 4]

UNCONNECTED IN THIS PROJECT

AUDIO MIXER INSIDE ATARI

BUS LOGIC LEVEL SHIFTERS

# FPGA/SSD Flash Glue Logic

When programming SPI FLASH for bitstream,

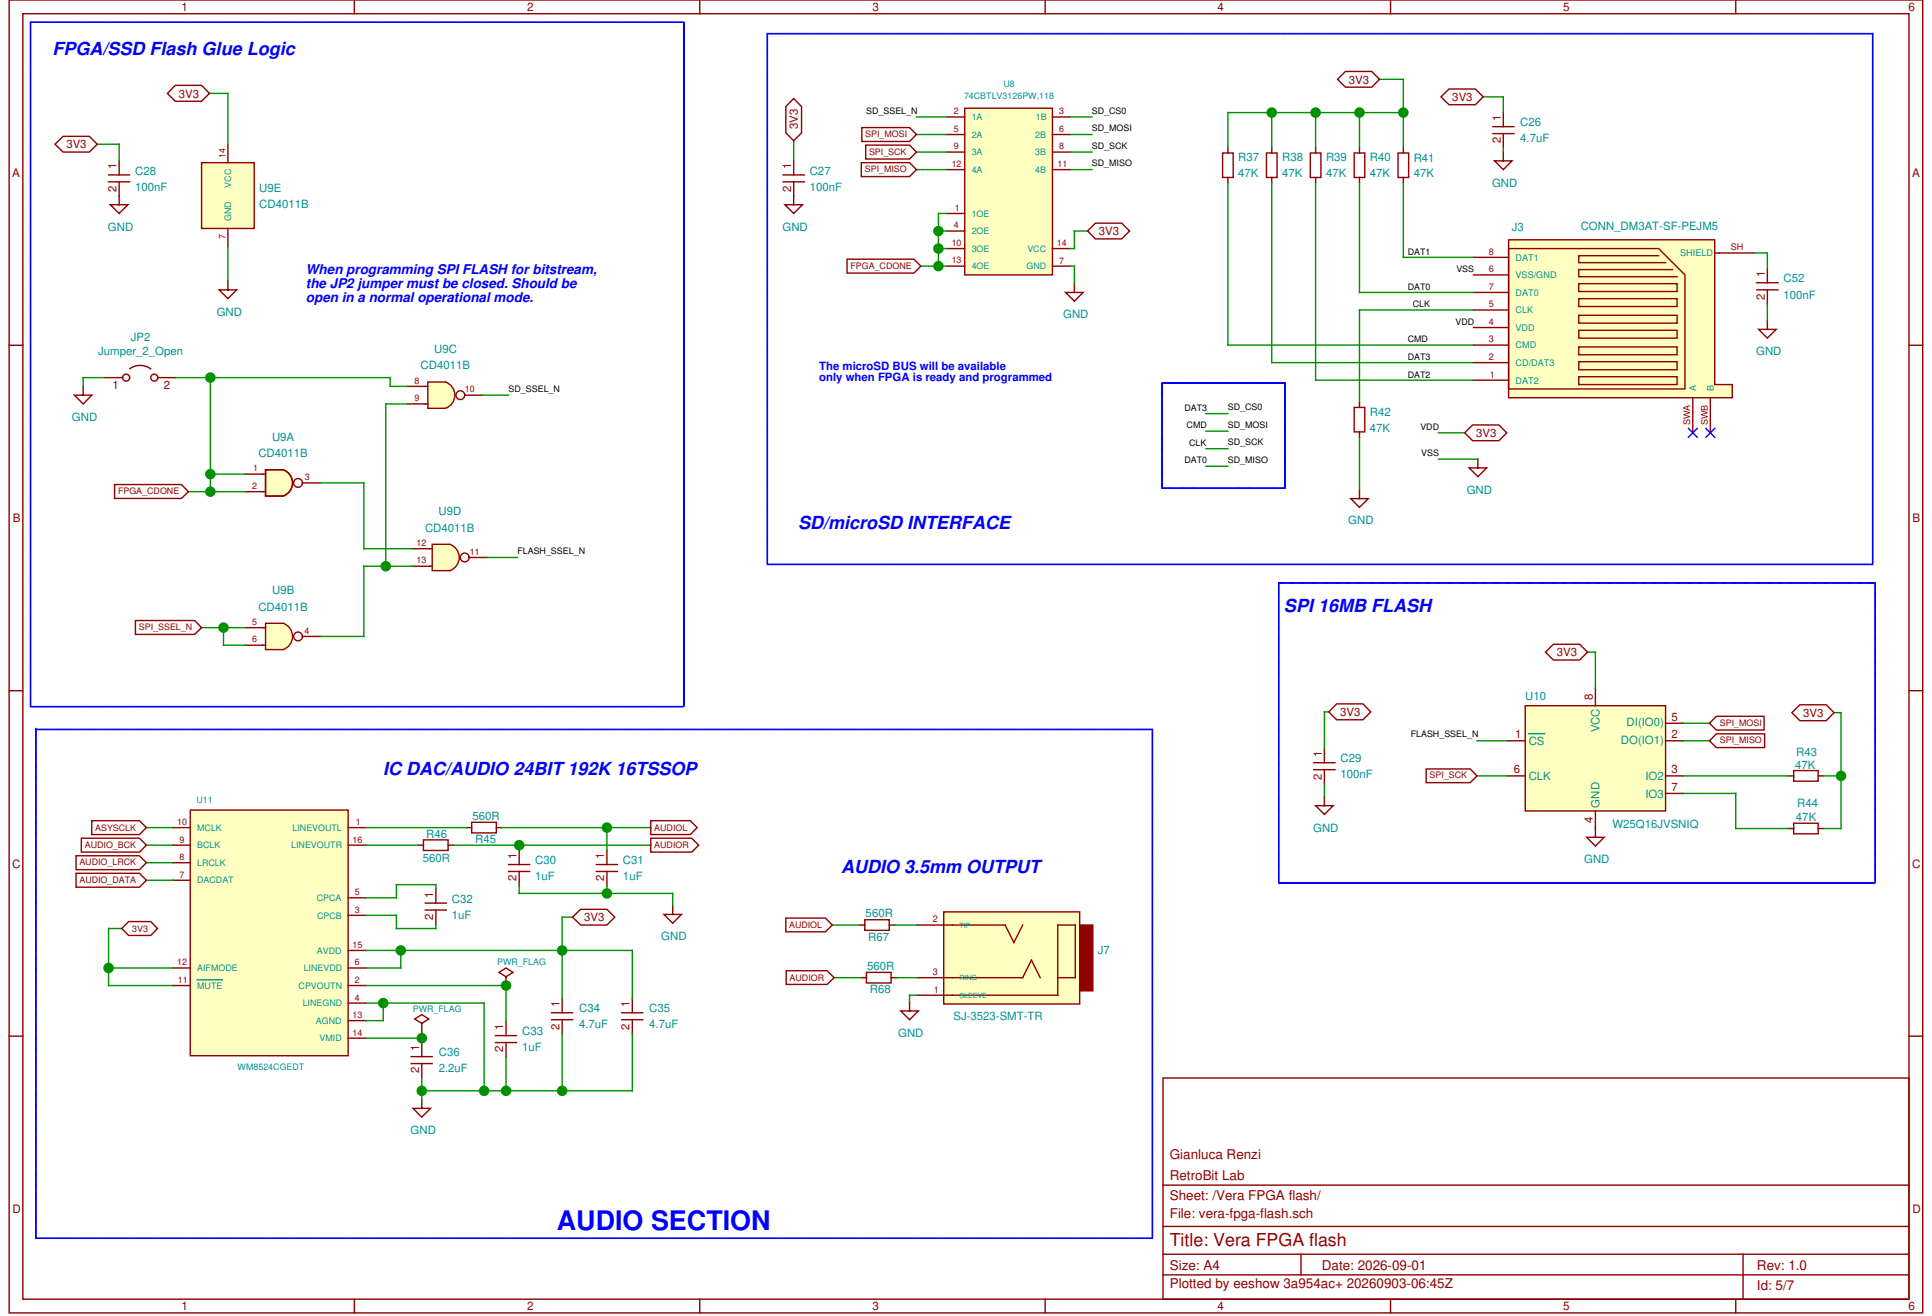
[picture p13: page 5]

the JP2 jumper must be closed. Should be
open in a normal operational mode.

The microSD BUS will be available
only when FPGA is ready and programmed

DAT3 | CD/DAT3 2

DAT2

Gianluca Renzi
RetroBit Lab
Sheet: /Vera FPGA flash/
File: vera-fpga-flash.sch
Title: Vera FPGA flash

# USB ESP32 PROGRAMMING

# POWER LED

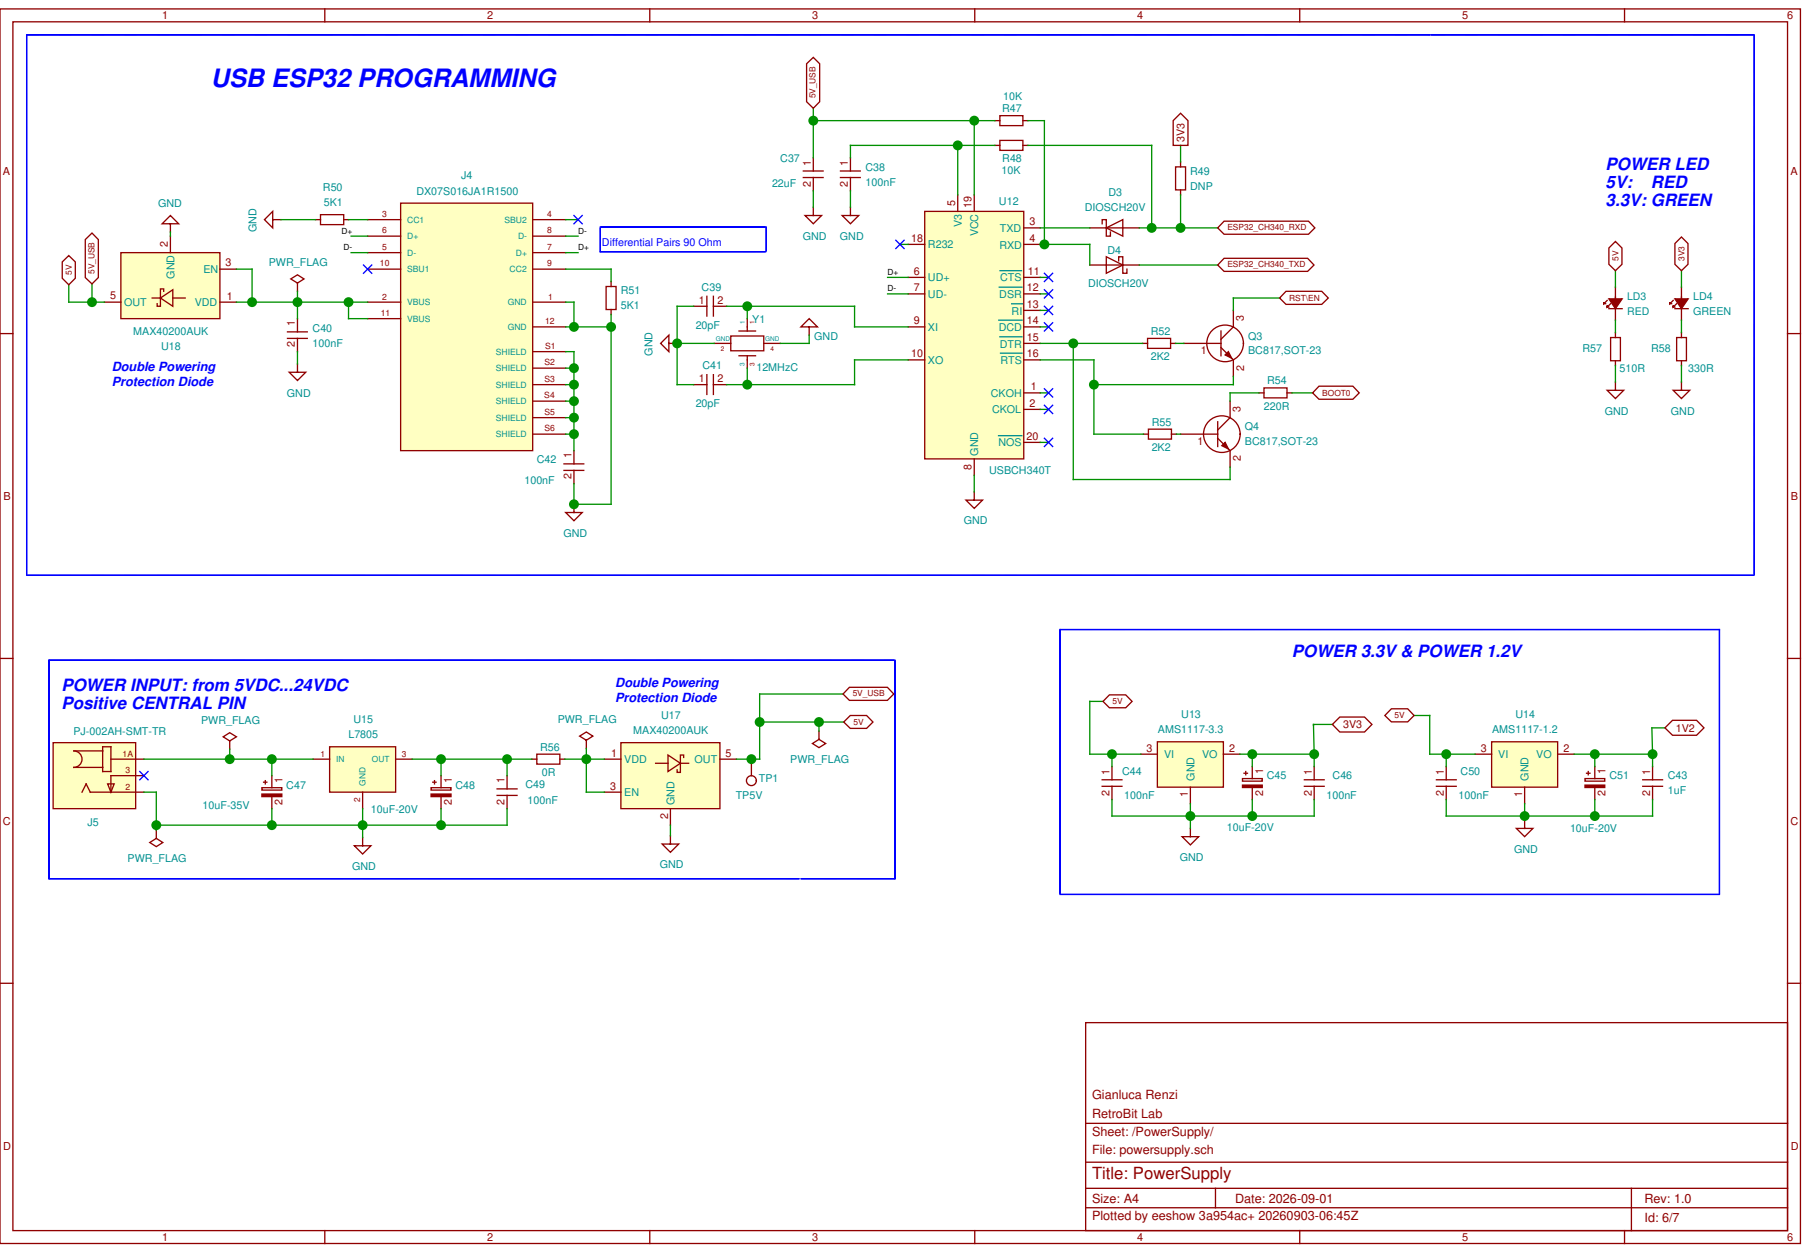
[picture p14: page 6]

# ANALOG VGA SIGNALS

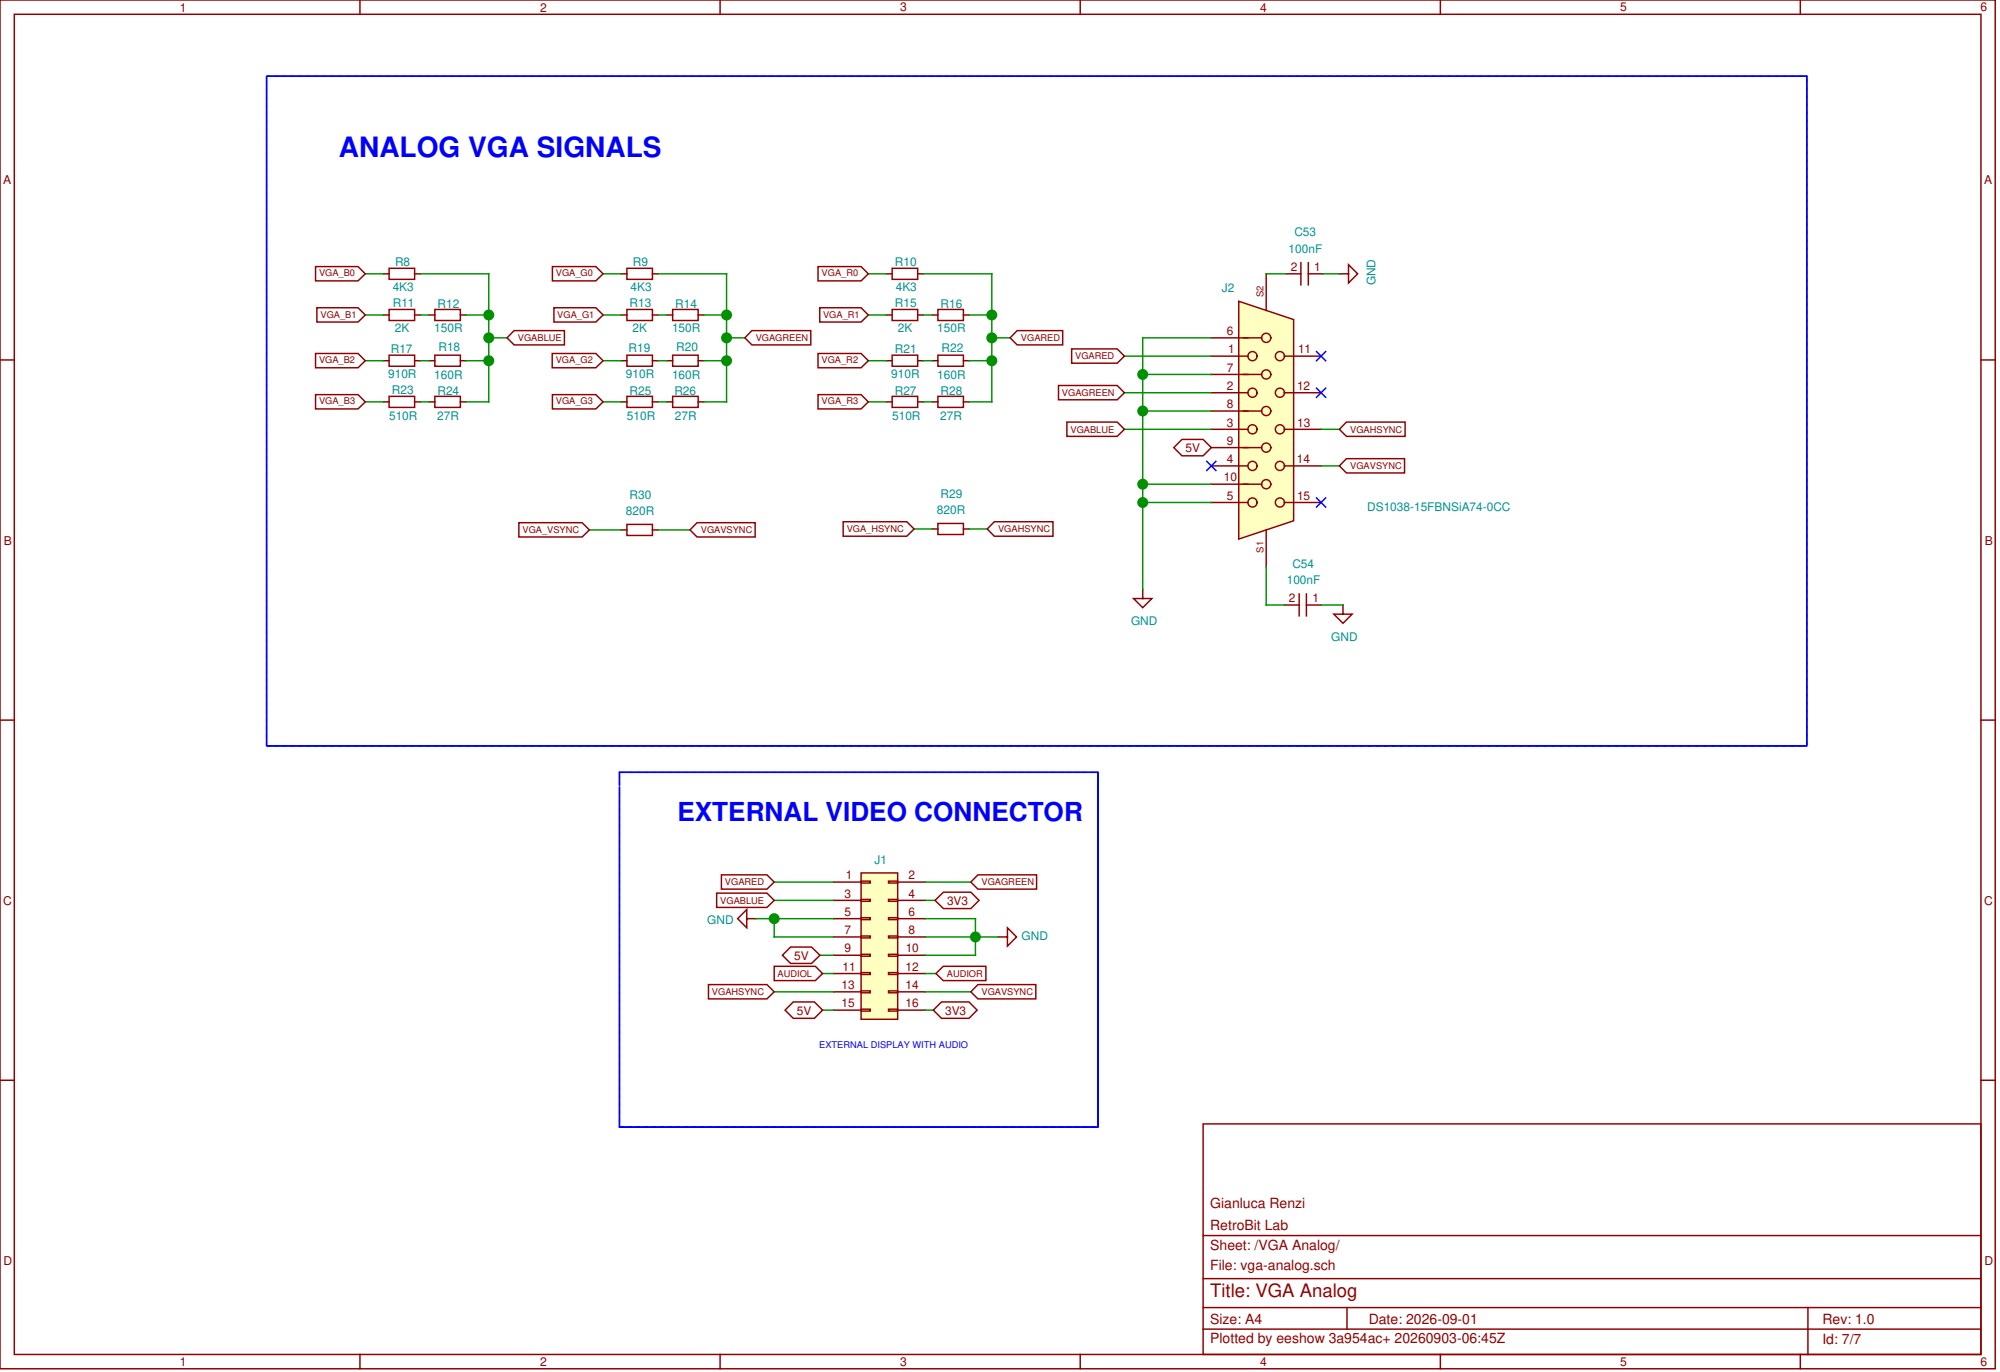
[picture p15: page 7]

EXTERNAL DISPLAY WITH AUDIO

Gianluca Renzi
RetroBit Lab
Sheet: /VGA Analog/
File: vga-analog.sch
Title: VGA Analog

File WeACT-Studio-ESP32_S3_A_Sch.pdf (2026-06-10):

## GND

## VCC_3V3 1

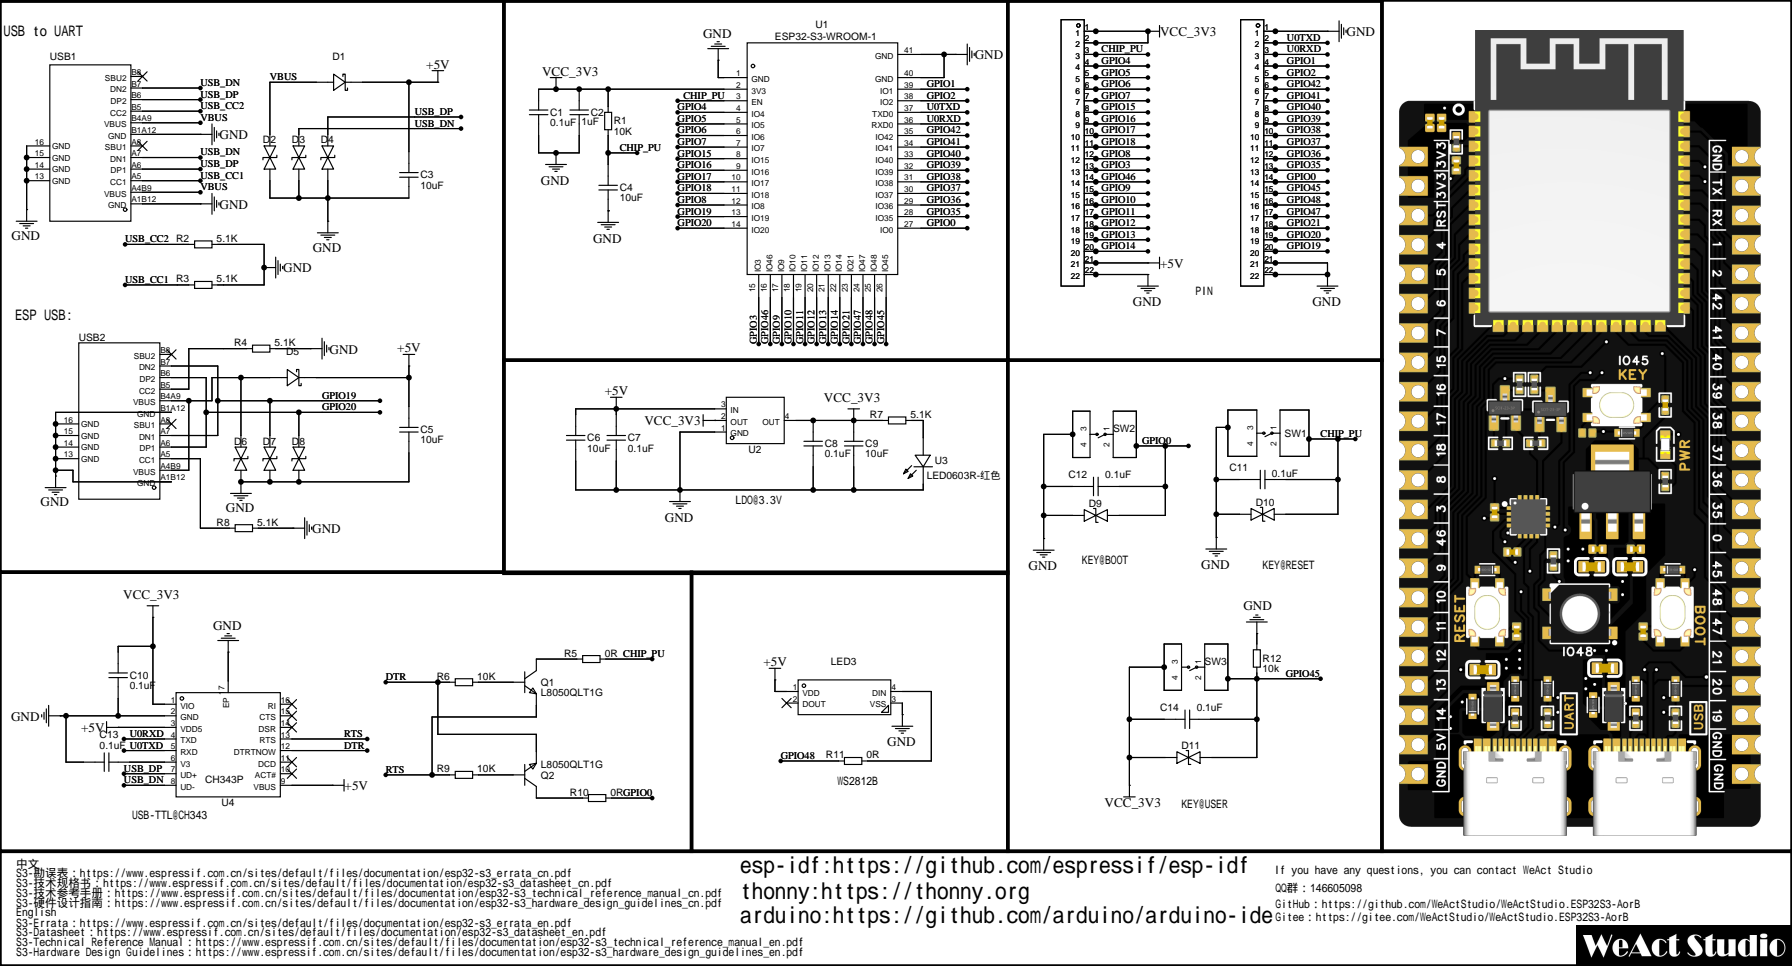
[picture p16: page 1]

IO0 27 IO⁴⁵ 26 IO⁴⁸ 25 IO⁴⁷ 24 IO²¹ 23 IO¹⁴ 22 IO¹³ 21 IO¹² 20 IO¹¹ 19 IO¹⁰ 18 IO⁹ 17 IO⁴⁶ 16 IO³ 15

ACT# 10 DCD 11 DTRTNOW 12 RTS 13 DSR 14 CTS 15 RI 16

esp-idf:https://github.com/espressif/esp-idf If you have any questions, you can contact WeAct Studio
thonny:https://thonny.org
arduino:https://github.com/arduino/arduino-ide

S3-勘误表：https://www.espressif.com.cn/sites/default/files/documentation/esp32-s3_errata_cn.pdf
S3-技术规格书：https://www.espressif.com.cn/sites/default/files/documentation/esp32-s3_datasheet_cn.pdf S3-技术参考手册：https://www.espressif.com.cn/sites/default/files/documentation/esp32-s3_technical_reference_manual_cn.pdf
S3-硬件设计指南：https://www.espressif.com.cn/sites/default/files/documentation/esp32-s3_hardware_design_guidelines_cn.pdf
English
S3-Errata：https://www.espressif.com.cn/sites/default/files/documentation/esp32-s3_errata_en.pdf
S3-Datasheet：https://www.espressif.com.cn/sites/default/files/documentation/esp32-s3_datasheet_en.pdf
S3-Technical Reference Manual：https://www.espressif.com.cn/sites/default/files/documentation/esp32-s3_technical_reference_manual_en.pdf
S3-Hardware Design Guidelines：https://www.espressif.com.cn/sites/default/files/documentation/esp32-s3_hardware_design_guidelines_en.pdf

QQ群：146605098
GitHub：https://github.com/WeActStudio/WeActStudio.ESP32S3-AorB
Gitee：https://gitee.com/WeActStudio/WeActStudio.ESP32S3-AorB

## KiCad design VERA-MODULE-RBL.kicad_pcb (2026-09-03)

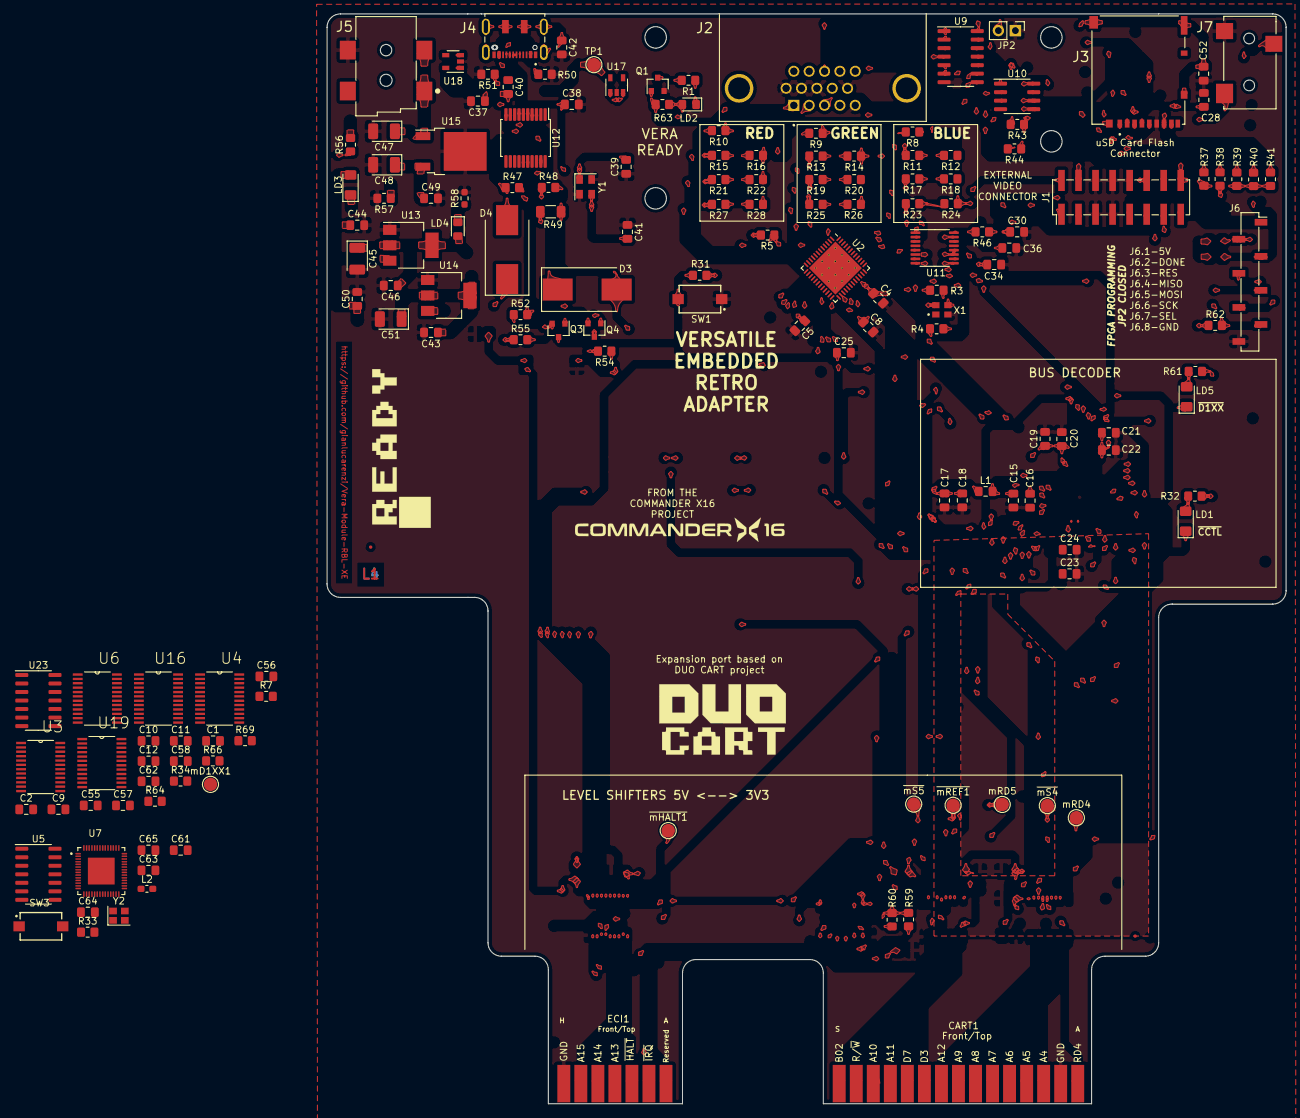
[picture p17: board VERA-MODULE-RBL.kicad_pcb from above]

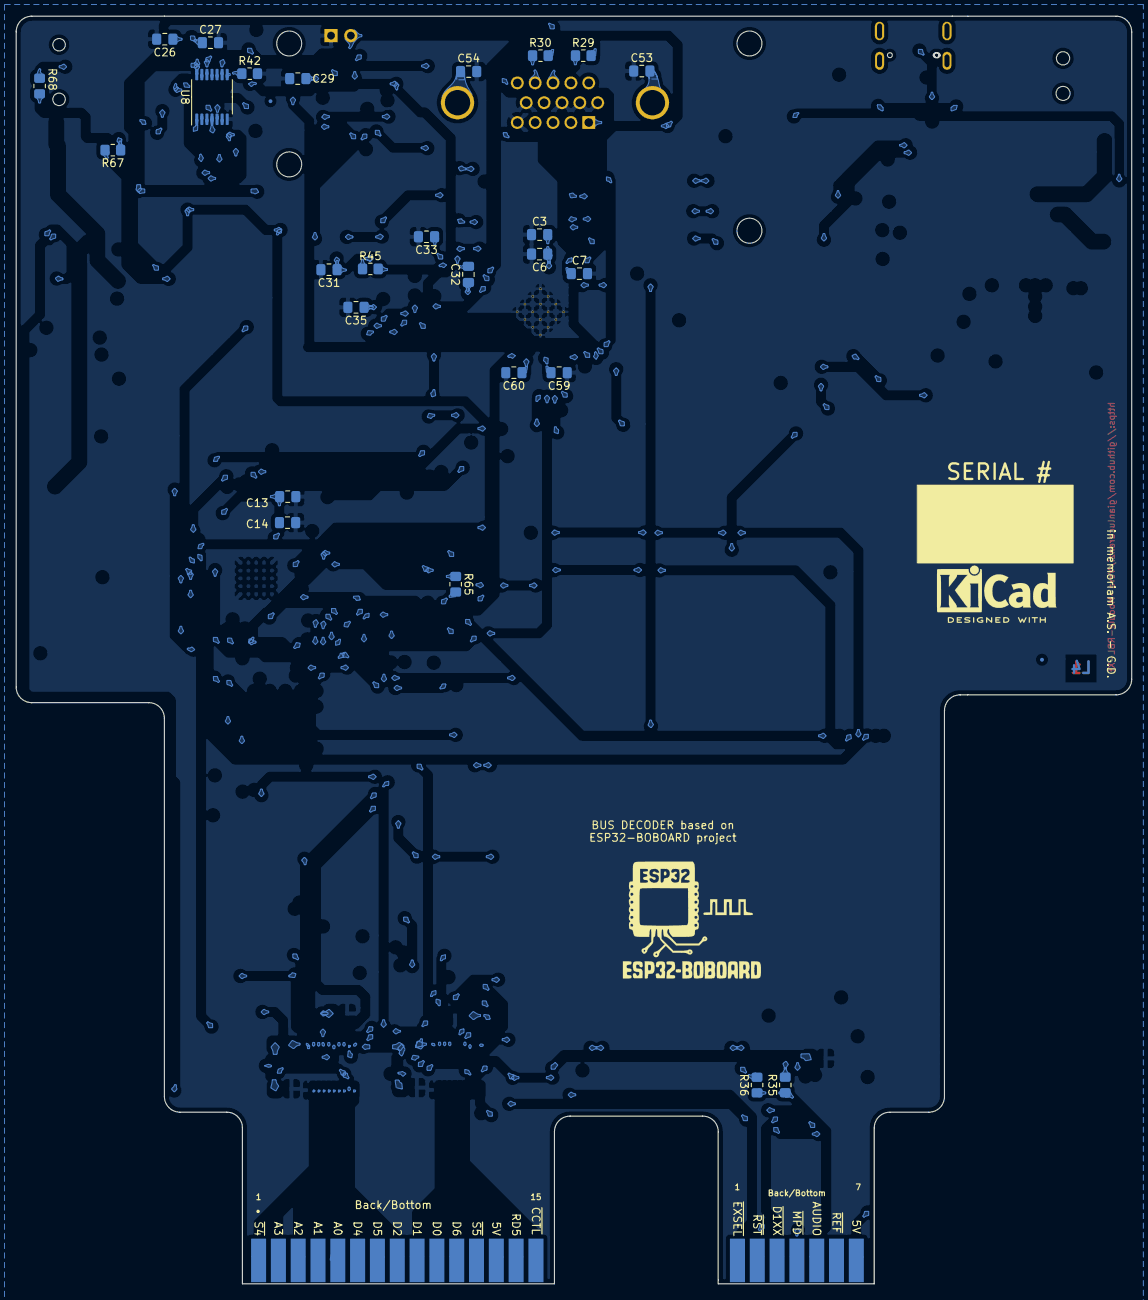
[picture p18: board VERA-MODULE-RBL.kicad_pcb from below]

Board: 4 copper layers, 143.0 x 162.5 mm, 195 parts (31 on the bottom side), 185 nets, no tracks yet.

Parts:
C1, C2, C9, C10, C11, C12, C14, C16, C18, C20, C22, C23, C25, C27, C28, C29, C38, C40, C42, C44, C46, C49, C50, C52, C53, C54, C55, C56, C57, C58, C61, C62, C63: 100nF; C_0805_2012Metric_Pad1.18x1.45mm_HandSolder
C3, C4, C5, C6, C7, C8, C30, C31, C32, C33, C43, C59, C60: 1uF; C_0805_2012Metric_Pad1.18x1.45mm_HandSolder
C13, C15, C17, C19, C21, C24: 10uF; C_0805_2012Metric_Pad1.18x1.45mm_HandSolder
C26, C34, C35: 4.7uF; C_0805_2012Metric_Pad1.18x1.45mm_HandSolder
C36: 2.2uF; C_0805_2012Metric_Pad1.18x1.45mm_HandSolder
C37: 22uF; C_0805_2012Metric_Pad1.18x1.45mm_HandSolder
C39, C41: 20pF; C_0805_2012Metric_Pad1.18x1.45mm_HandSolder
C45, C48, C51: 10uF-20V; CP_EIA-3528-12_Kemet-T_Pad1.50x2.35mm_HandSolder
C47: 10uF-35V; CP_EIA-3528-12_Kemet-T_Pad1.50x2.35mm_HandSolder
C64, C65: 27pF; C_0805_2012Metric_Pad1.18x1.45mm_HandSolder
CART1: ATARI-CARTRIDGE; ATARI-LEFT-CARTRIDGE
D3, D4: DIOSCH20V; D_SMC_Handsoldering
ECI1: ECIBUS; ATARI-XE-ECI-SLOT
FID1, FID2, FID3, FID4: Fiducial; Fiducial_0.5mm_Mask1mm
H1, H2, H3, H4: MountingHole; MountingHole_3.2mm_M3
J1: CONN_SMD_HEADER_BOX_02x08_Odd_Even_2.54mm; PinHeader_BOX_2x08_P2.54mm_Vertical_SMD
J2: DS1038-15FBNSiA74-0CC; CONNFLY_DS1038-15FBNSIA74-0CC
J3: CONN_DM3AT-SF-PEJM5; HRS_DM3AT-SF-PEJM5
J4: DX07S016JA1R1500; JAE_DX07S016JA1R1500
J5: PJ-002AH-SMT-TR; CUI_PJ-002AH-SMT-TR
J6: CONN_SMD_01x08_Staggered_2.54mm; PinSocket_1x08_P2.54mm_Vertical_SMD_Pin1Right
J7: SJ-3523-SMT-TR; CONN_AUDIO_CUI_SJ-3523-SMT-TR
JP2: Jumper_2_Open; PinHeader_1x02_P2.54mm_Vertical
L1: FB0805100R100MHZ4A; L_0805_2012Metric_Pad1.15x1.40mm_HandSolder
L2: IND0603600R100MHZ300mA; L_0603_1608Metric_Pad1.05x0.95mm_HandSolder
LBL1: Label-20mmx10mm; Label-20mmx10mm-Silkscreen
LD1, LD3, LD5: RED; LED_1206_3216Metric_Pad1.42x1.75mm_HandSolder
LD2, LD4: GREEN; LED_0805_2012Metric_Pad1.15x1.40mm_HandSolder
LOGO1: VERA X16 LOGO; x16logo
LOGO2: ATARI READY; atari_ready_8mm_rev
LOGO3: KiCAD DESIGN; KiCad-Logo2_6mm_SilkScreen
LOGO4: ATARI DUO BUS; DUOCart_20x11_Rev
LOGO5: ESP32_BOBOARD; ESP32_BOBOARD_5V_21.7mmx21.7mm
Q1: MOSFET-BSS138-SOT-23; SOT-23
Q3, Q4: BC817,SOT-23; SOT-23
R1: 2K7; R_0805_2012Metric_Pad1.20x1.40mm_HandSolder
R3, R4: 50R; R_0805_2012Metric_Pad1.20x1.40mm_HandSolder
R5, R35, R36, R47, R48, R62, R63, R65, R69: 10K; R_0805_2012Metric_Pad1.20x1.40mm_HandSolder
R7, R34, R64, R66: CREZ08051%; R_0805_2012Metric_Pad1.20x1.40mm_HandSolder
R8, R9, R10: 4K3; R_0805_2012Metric_Pad1.20x1.40mm_HandSolder
R11, R13, R15: 2K; R_0805_2012Metric_Pad1.20x1.40mm_HandSolder
R12, R14, R16: 150R; R_0805_2012Metric_Pad1.20x1.40mm_HandSolder
R17, R19, R21: 910R; R_0805_2012Metric_Pad1.20x1.40mm_HandSolder
R18, R20, R22: 160R; R_0805_2012Metric_Pad1.20x1.40mm_HandSolder
R23, R25, R27, R57: 510R; R_0805_2012Metric_Pad1.20x1.40mm_HandSolder
R24, R26, R28: 27R; R_0805_2012Metric_Pad1.20x1.40mm_HandSolder
R29, R30: 820R; R_0805_2012Metric_Pad1.20x1.40mm_HandSolder
R31, R33, R59, R60: 4K7; R_0805_2012Metric_Pad1.20x1.40mm_HandSolder
R32, R61: 330R; R_0805_2012Metric_Pad1.20x1.40mm_HandSolder
R37, R38, R39, R40, R41, R42, R43, R44: 47K; R_0805_2012Metric_Pad1.20x1.40mm_HandSolder
R45, R46, R67, R68: 560R; R_0805_2012Metric_Pad1.20x1.40mm_HandSolder
R49: DNP; R_1206_3216Metric_Pad1.30x1.75mm_HandSolder
R50, R51: 5K1; R_0805_2012Metric_Pad1.20x1.40mm_HandSolder
R52, R55: 2K2; R_0805_2012Metric_Pad1.20x1.40mm_HandSolder
R54: 220R; R_0805_2012Metric_Pad1.20x1.40mm_HandSolder
R56: 0R; R_0805_2012Metric_Pad1.20x1.40mm_HandSolder
R58: 330R; R_0603_1608Metric_Pad0.98x0.95mm_HandSolder
SW1, SW3: SPST2P; SPST-7.3x3.9x2.5-WUERTH-434121025816
TP1: TP5V; TestPoint_Pad_D2.0mm
U2: ICE40UP5K-SG48ITR; QFN-48-1EP_7x7mm_P0.5mm_EP5.6x5.6mm
U3, U4, U6, U16, U19: 74LVC4245APW_118; IC_74LVC4245_SOP65P640X110-24N
U5: IC74HC00; SOIC-14_3.9x8.7mm_P1.27mm
U7: ESP32-S3FN8; IC_ESP32-S3FN8-QFN40P700X700X90-57N
U8: 74CBTLV3126PW,118; TSSOP-14_4.4x5mm_P0.65mm
U9: CD4011B; SOIC-14_3.9x8.7mm_P1.27mm
U10: W25Q16JVSNIQ; SOIC-8_3.9x4.9mm_P1.27mm
U11: WM8524CGEDT; TSSOP-16_4.4x5mm_P0.65mm
U12: USBCH340T; SSOP-20_5.3x7.2mm_P0.65mm
U13: AMS1117-3.3; SOT-223-3_TabPin2
U14: AMS1117-1.2; SOT-223-3_TabPin2
U15: L7805; TO-252-2
U17, U18: MAX40200AUK; SOT-23-5
U23: SN74HCT04DR; SOIC-14_3.9x8.7mm_P1.27mm
X1: ECS-2033-250-BN; OSC_ECS-2033-250-BN
Y1: 12MHzC; Crystal_SMD_EuroQuartz_MT-4Pin_3.2x2.5mm
Y2: 40.000Mhz; Crystal_SMD_2520-4Pin_2.5x2.0mm
mD1XX1: TestPoint; TestPoint_Pad_D2.0mm
mRD4, mRD5: TestPoint; TestPoint_Pad_D2.0mm

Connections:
1V2: C7.1, C8.1, C43.1, C51.1, C60.1, U2.5, U2.29, U2.30, U14.2
3V3: C1.2, C3.2, C4.1, C5.1, C6.1, C9.2, C11.2, C13.1, C14.1, C17.1, C18.1, C19.1, C20.1, C21.1, C22.1, C23.2, C24.2, C26.1, C27.1, C28.1, C29.1, C34.1, C35.1, C45.1, C46.1, C55.2, C58.2, C59.2, C63.2, J1.4, J1.16, J3.4, L1.1, LD2.2, LD4.2, R31.1, R32.1, R33.1, R37.1, R38.1, R39.1, R40.1, R41.1, R43.1, R44.1, R49.2, R59.2, R60.1, R61.1, R62.1, R63.1, R65.1, U2.1, U2.22, U2.24, U2.33, U3.24, U4.24, U5.14, U6.24, U7.20, U7.29, U7.46, U7.55, U7.56, U8.14, U9.14, U10.8, U11.6, U11.11, U11.12, U11.15, U13.2, U16.24, U19.24, X1.4
5V: C2.2, C10.2, C12.2, C37.1, C44.1, C50.1, C56.2, C57.1, C62.2, CART1.13, ECI1.7, J1.9, J1.15, J2.9, LD3.2, R47.2, R69.1, TP1.1, U3.1, U3.2, U4.1, U4.2, U6.1, U6.2, U12.19, U13.3, U14.3, U16.1, U17.5, U18.5, U19.1, U23.14
/BusDecoder/VDD3P3: C15.1, C16.1, L1.2, U7.2, U7.3
/PowerSupply/D+: J4.6, J4.7, U12.6
/PowerSupply/D-: J4.5, J4.8, U12.7
/Vera FPGA flash/CLK: J3.5, R42.1, U8.8
/Vera FPGA flash/CMD: J3.3, R37.2, U8.6
/Vera FPGA flash/DAT0: J3.7, R40.2, U8.11
/Vera FPGA flash/DAT1: J3.8, R41.2
/Vera FPGA flash/DAT2: J3.1, R39.2
/Vera FPGA flash/DAT3: J3.2, R38.2, U8.3
/Vera FPGA flash/FLASH_SSEL_N: U9.11, U10.1
/Vera FPGA flash/SD_SSEL_N: U8.2, U9.10
A0: CART1.5, U4.3
A1: CART1.4, U4.4
A2: CART1.3, U4.5
A3: CART1.2, U4.6
A4: CART1.C, U4.7
A5: CART1.D, U4.8
A6: CART1.E, U4.9
A7: CART1.F, U4.10
A8: CART1.H, U3.3
A9: CART1.J, U3.4
A10: CART1.P, U3.5
A11: CART1.N, U3.6
A12: CART1.K, U3.7
A13: ECI1.D, U3.8
A14: ECI1.E, U3.9
A15: ECI1.F, U3.10
ASYSCLK: R4.1, U11.10
AUDIO: ECI1.5, R35.1, R36.1
AUDIOL: C31.1, J1.11, R35.2, R45.1, R67.2
AUDIOR: C30.1, J1.12, R36.2, R46.1, R68.2
AUDIO_BCK: U2.38, U11.9
AUDIO_DATA: U2.42, U11.7
AUDIO_LRCK: U2.43, U11.8
BOOT0: C61.1, R33.2, R54.1, SW3.2, U7.5
D0: CART1.10, U19.3
D1: CART1.9, U19.4
D2: CART1.8, U19.5
D3: CART1.L, U19.6
D4: CART1.6, U19.7
D5: CART1.7, U19.8
D6: CART1.11, U19.9
D7: CART1.M, U19.10
ESP32_CH340_RXD: D3.2, R48.2, R49.1, U7.50
ESP32_CH340_TXD: D4.1, U7.49
FPGA_CDONE: J6.2, JP2.2, Q1.1, R63.2, U2.7, U7.44, U8.1, U8.4, U8.10, U8.13, U9.1, U9.2, U9.8
GND: C1.1, C2.1, C3.1, C4.2, C5.2, C6.2, C7.2, C8.2, C9.1, C10.1, C11.1, C12.1, C13.2, C14.2, C15.2, C16.2, C17.2, C18.2, C19.2, C20.2, C21.2, C22.2, C23.1, C24.1, C25.2, C26.2, C27.2, C28.2, C29.2, C30.2, C31.2, C33.2, C34.2, C35.2, C36.2, C37.2, C38.2, C39.1, C40.2, C41.1, C42.2, C43.2, C44.2, C45.2, C46.2, C47.2, C48.2, C49.2, C50.2, C51.2, C52.2, C53.1, C54.1, C55.1, C56.1, C57.2, C58.1, C59.1, C60.2, C61.2, C62.1, C63.1, C64.1, C65.1, CART1.B, ECI1.H, J1.5, J1.6, J1.7, J1.8, J1.10, J2.5, J2.6, J2.7, J2.8, J2.10, J3.6, J4.1, J4.12, J5.2, J6.8, J7.1, JP2.1, Q1.2, R5.1, R7.2, R34.2, R42.2, R50.2, R51.2, R57.2, R58.2, R64.2, R66.2, SW1.1, SW3.1, U2.49, U3.11, U3.12, U3.13, U4.11, U4.12, U4.13, U5.7, U5.12, U5.13, U6.11, U6.12, U6.13, U7.57, U8.7, U9.7, U10.4, U11.4, U11.13, U12.8, U13.1, U14.1, U15.2, U16.11, U16.12, U16.13, U17.2, U18.2, U19.11, U19.12, U19.13, U23.7, X1.2, Y1.2, Y1.4, Y2.2, Y2.4
unnamed: C32.1, U11.5
unnamed: C32.2, U11.3
unnamed: C33.1, U11.2
unnamed: C36.1, U11.14
unnamed: C38.1, R48.1, U12.5
unnamed: C39.2, U12.9, Y1.1
unnamed: C40.1, J4.2, J4.11, U18.1, U18.3
unnamed: C41.2, U12.10, Y1.3
unnamed: C42.1, J4.S1, J4.S2, J4.S3, J4.S4, J4.S5, J4.S6
unnamed: C47.1, J5.1A, J5.1B, U15.1
unnamed: C48.1, C49.1, R56.2, U15.3
unnamed: C52.1, J3.SH
unnamed: C53.2, J2.S2
unnamed: C54.2, J2.S1
unnamed: C64.2, U7.53, Y2.3
unnamed: C65.2, L2.2, Y2.1
unnamed: D3.1, U12.3
unnamed: D4.2, R47.1, U12.4
unnamed: J4.3, R50.1
unnamed: J4.9, R51.1
unnamed: J7.2, R67.1
unnamed: J7.3, R68.1
unnamed: L2.1, U7.54
unnamed: LD1.2, R32.2
unnamed: LD2.1, R1.1
unnamed: LD3.1, R57.1
unnamed: LD4.1, R58.1
unnamed: LD5.2, R61.2
unnamed: Q1.3, R1.2
unnamed: Q3.1, R52.1
unnamed: Q3.2, R55.2, U12.16
unnamed: Q4.1, R55.1
unnamed: Q4.2, R52.2, U12.15
unnamed: Q4.3, R54.2
unnamed: R3.2, R4.2, X1.3
unnamed: R7.1, U3.22
unnamed: R11.1, R12.2
unnamed: R13.1, R14.2
unnamed: R15.1, R16.2
unnamed: R17.1, R18.2
unnamed: R19.1, R20.2
unnamed: R21.1, R22.2
unnamed: R23.1, R24.2
unnamed: R25.1, R26.2
unnamed: R27.1, R28.2
unnamed: R34.1, U4.22
unnamed: R43.2, U10.3
unnamed: R44.2, U10.7
unnamed: R45.2, U11.1
unnamed: R46.2, U11.16
unnamed: R56.1, U17.1, U17.3
unnamed: R64.1, U6.22
unnamed: R66.1, U16.2, U16.22
unnamed: U5.4, U5.8
unnamed: U9.3, U9.12
unnamed: U9.4, U9.9, U9.13
unnamed: U19.2, U23.2
unnamed: U19.22, U23.4
PHI2: CART1.S, U6.7, U23.3
RD4: CART1.A, U16.4
RD5: CART1.14, U16.3
RST\EN: C25.1, Q3.3, R31.2, SW1.2, U7.4
R~W: CART1.R, R69.2, U6.6, U23.1
SPI_MISO: J6.4, U2.17, U8.12, U10.2
SPI_MOSI: J6.5, U2.14, U8.5, U10.5
SPI_SCK: J6.6, U2.15, U8.9, U10.6
SPI_SSEL_N: J6.7, R62.2, U2.16, U9.5, U9.6
VGABLUE: J1.3, J2.3, R8.1, R12.1, R18.1, R24.1
VGAGREEN: J1.2, J2.2, R9.1, R14.1, R20.1, R26.1
VGAHSYNC: J1.13, J2.13, R29.1
VGARED: J1.1, J2.1, R10.1, R16.1, R22.1, R28.1
VGAVSYNC: J1.14, J2.14, R30.1
VGA_B0: R8.2, U2.46
VGA_B1: R11.2, U2.47
VGA_B2: R17.2, U2.48
VGA_B3: R23.2, U2.2
VGA_G0: R9.2, U2.3
VGA_G1: R13.2, U2.4
VGA_G2: R19.2, U2.6
VGA_G3: R25.2, U2.9
VGA_HSYNC: R29.2, U2.44
VGA_R0: R10.2, U2.10
VGA_R1: R15.2, U2.11
VGA_R2: R21.2, U2.12
VGA_R3: R27.2, U2.13
VGA_VSYNC: R30.2, U2.45
VSYSCLK: R3.1, U2.35
mA0: U2.40, U4.21, U7.17
mA1: U2.39, U4.20, U7.18
mA2: U2.37, U4.19, U7.19
mA3: U2.41, U4.18, U7.21
mA4: U2.34, U4.17, U7.22
mA5: U4.16, U7.23
mA6: U4.15, U7.24
mA7: U4.14, U7.25
mA8: U3.21, U7.26
mA9: U3.20, U7.27
mA10: U3.19, U7.40
mA11: U3.18, U7.41
mA12: U3.17, U7.38
mA13: U3.16, U7.39
mA14: U3.15, U7.51
mA15: U3.14, U7.52
mD0: U2.27, U7.9, U19.21
mD1: U2.26, U7.10, U19.20
mD2: U2.25, U7.11, U19.19
mD3: U2.23, U7.12, U19.18
mD4: U2.21, U7.13, U19.17
mD5: U2.20, U7.14, U19.16
mD6: U2.19, U7.15, U19.15
mD7: U2.18, U7.16, U19.14
mPHI2: U5.1, U5.5, U6.17, U7.6
mRD4: U16.20, mRD4.1
mRD5: U16.21, mRD5.1
mR~W: U5.2, U5.9, U5.10, U6.18, U7.7
~ATARI_RESET: U7.42, U16.15
~CCTL: CART1.15, U6.8
~D1XX: ECI1.3, U6.3
~EXSEL: ECI1.1, U16.7
~FPGA_RESET: J6.3, R5.2, U2.8, U7.43
~HALT: ECI1.C, U16.5
~IRQ: ECI1.B, U16.6
~MPD: ECI1.4, U16.8
~REFRESH: ECI1.6, U6.9
~RST: ECI1.2, U16.9
~S4: CART1.1, U6.4
~S5: CART1.12, U6.5
~mCCTL: LD1.1, U6.16
~mD1XX: LD5.1, U6.21, mD1XX1.1
~mEXSEL: U7.47, U16.17
~mMPD: U7.48, U16.16
~mRE: R59.1, U2.36, U5.3
~mVCS0: U2.28, U7.45
~mVIRQ: R65.2, U2.32, U16.18
~mWE: R60.2, U2.31, U5.6

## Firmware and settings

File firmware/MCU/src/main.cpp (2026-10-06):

/**
 * esp32-main.cpp  --  Atari PBI / CCTL  VeraX16 Bus Controller
 *
 * Target MCU: ESP32-S3FN8 (QFN56)
 *
 * This firmware allows an ESP32-S3 to interface with the 6502 bus of an
 * Atari XL/XE computer. Both address spaces are handled at runtime from
 * the full 16-bit address bus (A0–A15):
 *   - PBI ($D100–$D1FF, $D600–$D7FF, $D800–$DFFF): VERA card registers and ROM
 *   - CCTL ($D500–$D5FF): cartridge control line (DEV_SEL_N only)
 *
 * This version uses a definitive 34-GPIO mapping (plus Serial on 43/44)
 * with software-based 16-bit address decoding.
 *
 * Style: Allman
 * Language: English
 */

#include <Arduino.h>
#include <driver/gpio.h>
#include <soc/gpio_struct.h>
#include <string.h>
#include "freertos/FreeRTOS.h"
#include "freertos/task.h"
#include "freertos/queue.h"
#include <driver/dedic_gpio.h>
#include <hal/cpu_ll.h>
#include <esp_timer.h>
#include "pbi-driver.h"

/* ===========================================================================
 * Hardware Pin Mapping (ESP32-S3FN8 QFN56)
 * =========================================================================== */

/* --- Bank 0 Signals (GPIO 0-31) --- */
#define PIN_PHI2        1    /* CPU Clock Phase 2 (Pin 6) */
#define PIN_RW          2    /* Read/Write, High = Read (Pin 7) */

/* D0-D7: GPIO 4 to 11 (Pins 9-16, contiguous in Bank 0) */
#define DBUS_MASK       0x00000FF0UL
static const uint8_t DBUS_PINS[8] = { 4, 5, 6, 7, 8, 9, 10, 11 };

/* A0-A9: GPIO 12 to 21 (Pins 17-27, pin 20 = VDD3P3_RTC, not GPIO) */
#define ABUS_LO_MASK    0x003FF000UL

/* --- Bank 1 Signals (GPIO 32-48) --- */
#define PIN_A12         33   /* Address Bit 12 (Pin 38) */
#define PIN_A13         34   /* Address Bit 13 (Pin 39) */
#define PIN_A10         35   /* Address Bit 10 (Pin 40) */
#define PIN_A11         36   /* Address Bit 11 (Pin 41) */
#define PIN_ARESET      37   /* Atari System Reset Output (Pin 42) */
#define PIN_CRESET      38   /* Vera Chip Reset Output (Pin 43) */
#define PIN_CDONE       39   /* Vera Programmed Status Input (Pin 44) */
#define PIN_DEV_SEL_N   40   /* Vera Chip Select Output (Pin 45, active LOW) */
#define PIN_EXTSEL_N    41   /* Atari MMU Disable Output (Pin 47, active LOW) */
#define PIN_MPD         42   /* Math Pack Disable — disables internal Atari Math Pack ROM $D800-$DFFF (Pin 48, active LOW) */
#define PIN_A14         45   /* Address Bit 14 (Pin 51) */
#define PIN_A15         46   /* Address Bit 15 (Pin 52) */

/* Serial Debug (UART0 default pins on ESP32-S3 QFN56) */
#define PIN_UART_TX     43   /* UART0 TX (Pin 49) */
#define PIN_UART_RX     44   /* UART0 RX (Pin 50) */

/* RAMbo hardware enable: external 10K pull-up = RAMbo present, pull-down = no RAMbo */
#define PIN_RAMBO_EN     3   /* GPIO 3 (Pin 8) — read once at boot */

/*
 * Strapping Pins — Power-On Boot Configuration (ESP32-S3FN8 QFN56)
 *
 * The ESP32-S3 samples four strapping pins during the power-on reset window,
 * before any firmware code executes.  The sampled levels select the boot mode
 * and several chip-level options.
 *
 * Timing note: PIN_ARESET (GPIO37) is configured as OUTPUT only inside setup().
 * At strapping-sample time it is still an input (high-Z), so the ESP32 has NOT
 * yet asserted the Atari reset line.  The Atari's own power-on reset circuitry
 * (MMU/POKEY RC network) holds the 6502 RESET# pin LOW, which tri-states the
 * 6502 address bus.  The TXS0108E level-shifters (U1–U4) auto-sense direction:
 * with floating inputs on the Atari side the outputs are high-Z, and the
 * ESP32-side internal pull resistors determine the final strapping level.
 *
 * GPIO0  —  Pin  5  |  Boot mode selection  |  Internal weak PULL-UP ~45 kΩ
 *   Net BOOT0: R33 4.7 kΩ pull-up, BOOT button SW3, C61, and R54 -> Q4 (auto-reset
 *   from the programmer).  Not wired to any Atari signal.
 *   Pull-up holds GPIO0 HIGH throughout the strapping window.
 *   Sampled value: HIGH → SPI boot from embedded flash (correct for normal
 *   operation).  LOW would enter UART/JTAG download mode and halt the system.
 *
 * GPIO3  —  Pin  8  |  JTAG signal source   |  NO internal pull (truly floating)
 *   Wired to RAMBO_EN with an external 10 kΩ resistor to VCC or GND.
 *   Per the ESP32-S3 datasheet (§3.4 "JTAG Signal Source Control"): this pin has
 *   no internal pull resistors and "the strapping value must be controlled by
 *   the external circuit that cannot be in a high impedance state" — an external
 *   resistor is therefore mandatory, not optional, regardless of RAMbo detection.
 *   If GPIO3's level ever mattered for JTAG source (see below), the polarity per
 *   Table 3-5 is: LOW → JTAG pins (MTDI/MTCK/MTMS/MTDO, GPIO39-42);
 *   HIGH → USB Serial/JTAG Controller.
 *     Pull-up  (RAMbo hardware present) → HIGH → USB Serial/JTAG Controller.
 *       Irrelevant: ARDUINO_USB_CDC_ON_BOOT=0 disables USB CDC; GPIO19/20
 *       are reassigned to A7/A8.
 *     Pull-down (no RAMbo)              → LOW  → JTAG pins (GPIO39-42).
 *       Irrelevant: gpio_reset_pin() reclaims all JTAG pins in setup() before
 *       the Dedicated GPIO bundle is created.
 *   In practice GPIO3's level is moot either way: Table 3-5 shows the default
 *   (unburned) eFuse row — EFUSE_DIS_PAD_JTAG=0, EFUSE_DIS_USB_JTAG=0,
 *   EFUSE_STRAP_JTAG_SEL=0 — makes GPIO3 "Ignored" and always selects the USB
 *   Serial/JTAG Controller. The GPIO39-42 polarity above only applies if
 *   EFUSE_STRAP_JTAG_SEL has been deliberately burned to 1 (one-time
 *   programmable; not done by default in Arduino/ESP-IDF).
 *
 * GPIO45 —  Pin 51  |  VDD_SPI voltage      |  Internal weak PULL-DOWN ~5 kΩ
 *   Wired to address bit A14 via TXS0108E U4 (Atari 5 V → ESP32 3.3 V).
 *   At power-on the 6502 RESET# is LOW → A14 pin is high-Z on the Atari side
 *   → U4 output floats → internal pull-down drives GPIO45 LOW.
 *   Sampled value: LOW → VDD_SPI sourced from internal LDO (~1.8 V).
 *   For the FN8 variant the embedded flash VDD rail is supplied on-package and
 *   is independent of the VDD_SPI strapping; both LOW and HIGH are electrically
 *   safe.  The pull-down direction is consistent with the idle bus state. ✓
 *   Risk: if stray coupling or an abnormally fast Atari power rail drives A14
 *   HIGH during the sampling window, VDD_SPI = 3.3 V (VDD3P3_RTC) — still safe
 *   for FN8.
 *
 * GPIO46 —  Pin 52  |  ROM messages on UART |  Internal weak PULL-DOWN ~5 kΩ
 *   Wired to address bit A15 via TXS0108E U4.  Identical power-on scenario:
 *   6502 reset → A15 high-Z → U4 floats → pull-down → GPIO46 LOW.
 *   Sampled value: LOW → first-stage ROM boot messages on UART0 suppressed.
 *   Correct for production: the firmware initialises UART0 independently via
 *   Serial.begin() and uses it exclusively for debug output.  Enabling ROM
 *   messages (HIGH) would prepend Espressif boot log lines before the firmware
 *   output, which is undesirable but not harmful.
 */

/* ===========================================================================
 * Helper Macros & Inline Functions
 * =========================================================================== */

/*
 * Decode full 16-bit address from GPIO input snapshots.
 * A0-A9  : Bank 0 bits 12-21.
 * A10-A13: Bank 1 bits 3, 4, 1, 2  (GPIO 35, 36, 33, 34 → offsets from 32).
 * A14-A15: Bank 1 bits 13, 14       (GPIO 45, 46).
 * All bits captured in the same g_lo / g_hi APB reads — no extra reads needed.
 */
static inline uint16_t IRAM_ATTR decode_addr(uint32_t lo, uint32_t hi)
{
    uint16_t a = (uint16_t)((lo >> 12) & 0x3FFu);              /* A0-A9  */
    a |= (uint16_t)(((hi >> (PIN_A10 - 32)) & 1u) << 10);      /* A10    */
    a |= (uint16_t)(((hi >> (PIN_A11 - 32)) & 1u) << 11);      /* A11    */
    a |= (uint16_t)(((hi >> (PIN_A12 - 32)) & 1u) << 12);      /* A12    */
    a |= (uint16_t)(((hi >> (PIN_A13 - 32)) & 1u) << 13);      /* A13    */
    a |= (uint16_t)(((hi >> (PIN_A14 - 32)) & 1u) << 14);      /* A14    */
    a |= (uint16_t)(((hi >> (PIN_A15 - 32)) & 1u) << 15);      /* A15    */
    return a;
}

/**
 * Decode D0-D7 from Bank 0 snapshot.
 */
static inline uint8_t IRAM_ATTR decode_data(uint32_t lo)
{
    return (uint8_t)((lo >> 4) & 0xFFu);
}

/*
 * Dedicated GPIO channel mapping — ESP32-S3 Xtensa LX7 TIE instructions
 * (ee.get_gpio_in / ee.wr_mask_gpio_out bypass the APB bus: ~1 cycle vs ~6).
 *
 * Input channels  (bit index in cpu_ll_read_dedic_gpio_in() result):
 *   Ch 0 = PHI2       (GPIO  1)
 *
 * Output channels (bit index in cpu_ll_write_dedic_gpio_mask() mask/val):
 *   Ch 0 = DEV_SEL_N  (GPIO 40)  active LOW
 *   Ch 1 = EXTSEL_N   (GPIO 41)  active LOW
 *   Ch 2 = MPD        (GPIO 42)  active LOW
 *
 * Input and output channel spaces are independent on ESP32-S3.
 */
#define DEDIC_IN_PHI2        (1u << 0)
#define DEDIC_OUT_DEVSELN    (1u << 0)
#define DEDIC_OUT_EXTSEL     (1u << 1)
#define DEDIC_OUT_MPD        (1u << 2)
#define DEDIC_OUT_CTRL_MASK  0x07u
#define DEDIC_OUT_CTRL_IDLE  0x07u   /* all HIGH = deasserted (active LOW) */

/* ===========================================================================
 * Compile-time Configuration
 * =========================================================================== */

#define PBI_DEV_ID        0x80u  /* PBI Device ID bit 7 */

/* Per-register trace (EVT_REG) costs ~1 us per access inside the bus loop:
 * enough to miss the next PHI2 edge or leave DEV_SEL_N asserted into the
 * following cycle (spurious VERA accesses).  Debug builds only. */
#ifndef VERA_TRACE_REGS
#define VERA_TRACE_REGS 0
#endif

/* Delay between CDONE high and the release of the Atari reset (VERA POR). */
#ifndef VERA_POST_CDONE_DELAY_US
#define VERA_POST_CDONE_DELAY_US 1000u
#endif

/* VERA_BOARD_IS_PBI is injected by the build system (-D flag in platformio.ini) */
#ifndef VERA_BOARD_IS_PBI
#define VERA_BOARD_IS_PBI 0x01u  /* fallback: PBI */
#endif

/* ===========================================================================
 * Log Queue (Core 1 → Core 0)
 * =========================================================================== */
#define LOG_QUEUE_SIZE 64

#define EVT_LATCH 0   /* VCS/CCTL latch state change */
#define EVT_REG   1   /* VERA register ($D1xx) access */

/* flags: bit0=write(1)/read(0)  bit1=latch state (EVT_LATCH)  bit2=MPD asserted  bit3=EXTSEL asserted */
typedef struct
{
    uint64_t ts_us;   /* microseconds since boot (esp_timer_get_time()) */
    uint8_t  type;
    uint8_t  offset;  /* register offset: 0x00-0xFF within address range */
    uint8_t  data;
    uint8_t  flags;
} LogEvt;

/* ===========================================================================
 * Shared Data
 * =========================================================================== */

static IRAM_ATTR uint32_t lut_drive[256];   /* Lookup table for fast data bus drive */
static IRAM_ATTR uint8_t  ram_pbi[512];     /* 512B RAM at $D600-$D7FF */

static bool rambo_hw_enabled = false; /* set in setup() reading PIN_RAMBO_EN */

/* 256 KB extended RAM (RAMbo) — IRAM BSS: resides in IRAM, zero Flash cost. */
static uint8_t extended_rambo_256k[256 * 1024] __attribute__((section(".iram0.bss")));

/*
 * PORTB ($D301) — PIA 6520 Output Register B, used for RAMbo bank switching.
 * Accessible at $D301 only when PBCTL bit 2 (CRB-2) = 1; when bit 2 = 0,
 * $D301 addresses the Data Direction Register (DDR) — those writes are ignored here.
 *
 * Bit 4 (RAME — RAM Enable):
 *   0 = RAMbo active: all 16 banks of $4000-$7FFF accessible; EXTSEL_N asserted
 *       to suppress Atari internal RAM in that window.
 *   1 = RAMbo disabled: Atari internal RAM responds at $4000-$7FFF normally.
 *
 * Bank number (0-15) from PORTB bits 6, 5, 3, 2:
 *   bank = ((portb >> 2) & 0x03) | ((portb >> 3) & 0x0C)
 *   Bit layout: 7   6   5   4    3   2   1   0
 *               -   b3  b2  RAME b1  b0  -   -    (b3:b0 = bank number)
 *
 * Ref: RAMBO manual (atarimania.com/documents/rambo_manual.pdf), p.14;
 *      Altirra Hardware Reference Manual §8; Motorola 6520 PIA datasheet.
 * Initialised to 0xFF (RAME = 1) — RAMbo disabled until OS writes $D301.
 */
static IRAM_ATTR uint8_t PORTB = 0xFFu;

/*
 * PBCTL ($D303) — PIA 6520 Control Register B.
 * Bit 2 (CRB-2) selects which register is exposed at $D301:
 *   0 → Data Direction Register (DDR): each bit selects pin direction
 *       (0 = input, 1 = output); DDR writes are NOT bank-selection writes.
 *   1 → Output Register (PORTB): bank-selection register.
 *
 * "For external PIA emulation, you must not only save the data destined for
 *  $D301. You must also intercept and save writes to PBCTL $D303 bit 2 to
 *  enable writing to $D301 *only* when PBCTL bit 2 = 1. This further
 *  qualifies writes to the output register at $D301 (which is what you see
 *  externally on the PIA), not the data direction register at $D301, as there
 *  are two registers at the same location." — warerat, AtariAge forums.
 *
 * Ref: Motorola 6520 PIA datasheet; Altirra Hardware Reference Manual §8.
 * Initialised to 0x00 (bit 2 = 0 → DDR exposed at $D301); the OS sets bit 2
 * before using $D301 as the bank-selection register.
 */
static IRAM_ATTR uint8_t PBCTL = 0x00u;

static QueueHandle_t log_queue;

/* ===========================================================================
 * Bus Drive/Release Logic
 * =========================================================================== */

/**
 * Precalculate bitmasks for each possible byte to avoid runtime logic.
 */
static void build_drive_lut(void)
{
    for (int v = 0; v < 256; v++)
    {
        uint32_t m = 0;
        for (int b = 0; b < 8; b++)
        {
            if (v & (1 << b))
            {
                m |= (1UL << DBUS_PINS[b]);
            }
        }
        lut_drive[v] = m;
    }
}

/**
 * Drive the data bus with a byte value.
 * GPIO.out covers Bank 0 entirely; writing lut_drive[val] sets D0-D7 (bits 4-11)
 * and zeros the remaining bits, which are all input-configured and ignore GPIO.out.
 * This saves one APB write compared to the w1tc+w1ts pattern.
 */
static inline void IRAM_ATTR bus_drive(uint8_t val)
{
    GPIO.out = lut_drive[val];
    GPIO.enable_w1ts = DBUS_MASK;
}

/**
 * Release the data bus (set to High-Z).
 */
static inline void IRAM_ATTR bus_release(void)
{
    GPIO.enable_w1tc = DBUS_MASK;
}

/* Enqueue a log event without blocking (drops if queue full). */
static inline void IRAM_ATTR log_send(uint8_t type, uint8_t offset,
                                      uint8_t data, uint8_t flags)
{
    LogEvt evt = {(uint64_t)esp_timer_get_time(), type, offset, data, flags};
    xQueueSend(log_queue, &evt, 0);
}
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
void loop(void)
{
    /* Shadow of VERA_CTRL DCSEL bits [2:1]; updated on every write to $D105. */
    static uint8_t dcsel = 0;

    LogEvt evt;
    while (xQueueReceive(log_queue, &evt, pdMS_TO_TICKS(10)) == pdTRUE)
    {
        uint32_t sec = (uint32_t)(evt.ts_us / 1000000ULL);
        uint32_t us  = (uint32_t)(evt.ts_us % 1000000ULL);
        if (evt.type == EVT_LATCH)
        {
            bool enabled = (evt.flags & 0x02) != 0;
            Serial.printf("[%5lu.%06lu] [VCS ] Latch %s ($%02X written to %s) MPD=%s EXTSEL=%s\n",
                          sec, us,
                          enabled ? "ENABLED " : "DISABLED", evt.data,
                          VERA_BOARD_IS_PBI ? "$D1FF" : "$D5FF",
                          (evt.flags & 0x04) ? "LO" : "HI",
                          (evt.flags & 0x08) ? "LO" : "HI");
        }
        else  /* EVT_REG */
        {
            /* Track DCSEL so muxed registers ($09-$0C) resolve correctly. */
            if (evt.offset == 0x05 && (evt.flags & 0x01))
                dcsel = (evt.data >> 1) & 0x07;

            Serial.printf("[%5lu.%06lu] [D1%02X - %-20s] %c $%02X  MPD=%s EXTSEL=%s\n",
                          sec, us,
                          evt.offset,
                          vera_reg_name(evt.offset, dcsel),
                          (evt.flags & 0x01) ? 'W' : 'R',
                          evt.data,
                          (evt.flags & 0x04) ? "LO" : "HI",
                          (evt.flags & 0x08) ? "LO" : "HI");
        }
    }
}

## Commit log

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2025-07-31 Added a selector for disabling the TXB0108 during the ESP32 USB Programming. They can interfere with the bootloader signals
    [busdecoder.sch, powersupply.sch, vera-fpga-flash.sch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]
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2025-09-11 DB15 VGA Replaced by another with a better support.
    [vera-fpga.sch]
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2025-09-17 Modified the 1.5V LDO to 1.2V LDO as in X65 and Vera Module projects. Added a 3.5mm audio jack stereo. To check if there are issues with the ATARI connected AUDIO Mixer
    [VERA-MODULE-RBL-XE-v0.1a-JLCPCB-BOM.csv, VERA-MODULE-RBL.csv, VERA-MODULE-RBL.sch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]
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2025-09-30 Missing TITLE
    [VERA-MODULE-RBL.sch]
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2025-10-23 Corrected a TearDrop manually
    [VERA-MODULE-RBL-B_Cu.gbl, VERA-MODULE-RBL-B_Mask.gbs, VERA-MODULE-RBL-B_Paste.gbp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]
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2025-10-27 Date correction
    [VERA-MODULE-RBL.sch, busdecoder.sch, cartridgeInterface.sch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]
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2026-05-08 Typo and missing includes
    [main.cpp]
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2026-05-28 Added for Address Decoding. Needs to be updated with the correct components HCT components
    [addressdecoder.sch]
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2026-05-28 Updated with the correct logic for RESET. Firmware needs to be adapted
    [busdecoder.sch, cartridgeInterface.sch, vera-fpga.sch]
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2026-06-08 TODO: (does not work now) Changing the pin mapping
    [busdecoder.sch, cartridgeInterface.sch, vera-fpga.sch]
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2026-06-09 Migrate MCU from ESP32-PICO-D4 to ESP32-S3FN8
    Replace all pin mappings, firmware defines, and documentation to target
    the ESP32-S3FN8 (QFN56, 8 MB Quad SPI flash, dual-core LX7 @ 240 MHz).
    Key mapping changes:
    - D0-D7 : GPIO18-27 (scattered) → GPIO4-11 (consecutive, DBUS_MASK=0xFF0)
    - A0-A5 : GPIO32-39 → GPIO33-38 (bank-1 bits 1-6, consecutive)
    - A6-A10 : GPIO16,17,14,12,13 → GPIO12-16 (ordered)
    - R/W_ : GPIO15 → GPIO17
    - D1XX_N : GPIO5 → GPIO18
    - ROM_SEL_N: GPIO4 → GPIO21
    - DEV_SEL_N: GPIO3 → GPIO1 (GPIO3 is floating strapping pin on S3)
    - UART TX : GPIO1 → GPIO43 (S3 UART0 hardware pin)
    - UART RX : GPIO3 → GPIO44 (S3 UART0 hardwa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
    [main.cpp]
2026-06-09 Add dual-MCU support (ESP32-S3FN8 + ESP32-classic) with QFN56 pin mapping
    - Rewrite main.cpp with #if MCU_ESP32_S3 / MCU_ESP32_CLASSIC blocks: separate
    pin defines, DBUS_MASK, DBUS_PINS[], decode_addr/data/offset_cctl, and
    gpio_config bitmasks for each target; build_drive_lut and Serial.begin use
    the MCU-specific constants at compile time
    - Add 4 PlatformIO environments in platformio.ini: nodemcu-pbi, nodemcu-cctl,
    esp32s3fn8-pbi, esp32s3fn8-cctl; all pinned to espressif32@6.6.0 to avoid
    broken tool-esptoolpy@2.41100 install on this host
    - Extend PIN-MAPPING.md with QFN56 physical pin numbers (from Table 2-1 of
    datasheet v2.2) in every signal table; add GPIO15/GPIO16 = XTAL_32K_P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
    [main.cpp]
2026-06-09 Update technical analysis doc: dual-MCU, QFN56 pin table, BUS_MODE, timing
    - Add table of 4 PlatformIO build environments (nodemcu/esp32s3fn8 x pbi/cctl)
    - Replace generic pin references with GPIO + QFN56 physical pad numbers (from
    datasheet Table 2-1); warn on GPIO15/16 = XTAL_32K pads and 60 µs glitches
    - Replace old high-level pseudo-code listing with actual register-access code
    (GPIO.in / GPIO.in1.val / GPIO.out_w1ts/w1tc) and MCU_ESP32_S3 ifdef block
    - Update timing analysis: use 279 ns PHI2-high window (~67 ESP32-S3 cycles)
    instead of full 559 ns cycle; add IRAM_ATTR and LUT rationale
    - Regenerate PDF
2026-06-09 PBI firmware: add MPD, RAM_SEL_N, and bus contention fix
    - ESP32-S3FN8: add PIN_RAM_SEL_N (GPIO40/MTDO) and PIN_MPD (GPIO42/MTMS)
    - Assert MPD before bus_drive() for all PBI reads (ROM, RAM, int_regs, VERA)
    to prevent bus contention when the Atari MMU has not tristated its buffer
    - Add 512-byte ram_pbi[] IRAM buffer served at $D600-$D7FF when VCS latch active
    - MPD_ASSERT/DEASSERT use GPIO.out1_w1tc/w1ts (bank-1 GPIO32+ registers)
    - DECODE_IS_RAM reads GPIO40 from g_hi (bank-1 snapshot)
    - MCU_ESP32_CLASSIC: add #warning for GPIO12/A9 VDD_SDIO strapping risk
    and missing RAM_SEL_N / MPD pins (all GPIOs occupied)
    - MPD_ASSERT/MPD_DEASSERT are no-ops on MCU_ESP32_CLASSIC
    - PIN-MAPPING.md: ad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
    [main.cpp]
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2026-06-09 Fix: comportamento corretto EXTSEL_N e MPD nel PBI loop
    EXTSEL_N (GPIO0):
    - Non e' un segnale persistente legato allo stato del latch
    - Si asserta per-ciclo quando selected && ((is_d1xx && !is_d1ff) || is_ram)
    - Disabilita MMU/Freddie per accesso D1xx ($D100-$D1FE) e RAM $D600-$D7FF
    - Si deasserta sempre a fine ciclo insieme a DEV_SEL_N
    MPD (GPIO42, Math Pack Disable):
    - Si asserta SOLO quando selected && is_rom ($D800-$DFFF)
    - NON per letture RAM, registri interni o VERA
    - Disabilita la ROM interna Atari per far vincere la ROM servita dall'ESP32
    D1FF write: aggiorna solo il flag 'selected', nessuna manipolazione
    di segnali (EXTSEL_N e MPD sono per-ciclo, non persistenti)
    Aggiornato PIN-M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
    [main.cpp]
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2026-06-10 feat: sequenza di startup sincronizzata VERA/ATARI
    In setup() ARESET e CRESET vengono abbassati subito dopo il reclaim
    dei pin JTAG, prima ancora di Serial.begin, garantendo che Atari e
    VERA siano in reset durante tutta l'inizializzazione dell'ESP32.
    Nel MonitorTask, prima del for(;;), viene eseguita la sequenza:
    1. CRESET HIGH -> VERA FPGA inizia il caricamento del bitstream
    2. Polling CDONE (GPIO.in1) con timeout 5 s e log del tempo impiegato
    3. ARESET HIGH -> Atari esce dal reset con bus e FPGA gia' pronti
    [main.cpp]
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2026-06-10 docs: add crystal oscillator section (XTAL_P pin 56, XTAL_N pin 55)
    New PIN-MAPPING.md § 5 documents the mandatory 40 MHz crystal circuit:
    pin assignment, load capacitor formula, optional series resistor, and
    PCB layout rules. XTAL pins added to the excluded-pin table (§ 7).
    Sections renumbered 5→6 (Level Shifting), 6→7 (GPIO), 7→8 (QFN56 pinout).
    firmware/MCU/README.md intro now warns about the crystal requirement.
2026-06-10 docs: add ESP32-S3 40 MHz crystal requirement to README and LaTeX analysis
    README (EN+IT): separate VERA 25 MHz from ESP32 40 MHz crystal in specs
    table and BOM; add crystal note to ESP32-S3FN8 component description.
    Vera_Module_Analisys.ITA.tex:
    - Correct wrong claim "oscillatore RC interno a 240 MHz" (two occurrences);
    ESP32-S3 PLL requires an external 40 MHz crystal on XTAL_P (pin 56) /
    XTAL_N (pin 55) — without it the chip does not boot.
    - New subsection 3.x with crystal circuit (table, ASCII schematic, PCB rules).
    - Fix build-environment table: two separate envs -> single unified esp32s3fn8.
    - Fix RAMBO_EN note: GPIO3 is PIN_RAMBO_EN (pull-up/down), not a plain GND pin.
    - Regener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
2026-06-10 fix: add PBCTL ($D303) emulation; gate PORTB updates on CRB-2 bit
    The PIA 6520 exposes two registers at $D301 depending on PBCTL bit 2:
    CRB-2 = 0 → Data Direction Register (DDR) — writes must be ignored
    CRB-2 = 1 → Output Register (PORTB) — bank-selection writes
    Previously every write to $D301 updated PORTB, incorrectly treating DDR
    initialisation writes as bank selections. The fix adds a static PBCTL
    variable, snoops $D303 in the hot loop, and gates $D301 updates on bit 2.
    Also added documentation from verified sources:
    - PORTB: RAME (bit 4) name and meaning; bit-layout diagram; RAMBO manual
    reference (atarimania.com/documents/rambo_manual.pdf, p.14).
    - PBCTL: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
    [main.cpp]
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2026-06-10 fix: sostituisce BUS_MODE con VERA_BOARD_IS_PBI nel documento di analisi
    Aggiornati subsection title, intro e i due item PBI/CCTL (sezione 2.2):
    BUS_MODE=0 (PBI) → VERA_BOARD_IS_PBI=1 (default)
    BUS_MODE=1 (CCTL) → VERA_BOARD_IS_PBI=0
    Aggiornato anche GPIO0 → GPIO41 per EXTSEL_N in coerenza col pin mapping
    attuale. PDF rigenerato (13 pagine).
2026-06-10 fix: correggi overflow pagine nel documento LaTeX
    - Tabella pin principale: \resizebox{\linewidth}{!} per adattare alla larghezza
    - Equazione RAMbo: multline* per spezzare la riga troppo lunga
    - Tabella XTAL pin: p{8cm} sulla colonna Note per permettere il wrapping
    - Tabella componenti XTAL: \resizebox{\linewidth}{!}
    - Flowchart: scale 0.65->0.50, node distance 1.6/1.2->1.2/1.0, gap phi2_low 3.5->2.5cm
    - Tabella snooping: \resizebox{\linewidth}{!}
    - Paragrafi overflowing: \begin{sloppypar} nei punti critici
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2026-06-11 fix: correggi VHDL e PCF per rispettare i 39 pin dell'UP5K-SG48
    - Rinomina RNW_ in RNW (GHDL 2008 vieta identificatori che terminano con _)
    - Riduce DIP_SEL da 3 a 2 bit (40 pin -> 39, entro il limite SG48)
    - PCF: sostituisce tutti i pin non validi per SG48 (1,7,22,24,29,30)
    con pin validi (6,26,37,38,39); rimosso DIP_SEL[2]
    - Bitstream generato con successo: 102 KB, fmax 62.72 MHz @ 25 MHz clock
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2026-06-11 docs: aggiunge sezione reset sequencer 74LVC1G08
    - LaTeX: nuova sezione 5 "Reset Sequencing" con boot sequence,
    equazioni logiche, schema ASCII circuito, tabella verita',
    spiegazione 74LVC vs 74HC (5V tolerant inputs), BOM (U1 + R1-R4)
    - README: nuova sottosezione hardware "Reset sequencer" con tabella
    fasi, equazioni, schema ASCII, note 74LVC, BOM compatta
    - PDF rigenerato: 12 pagine, 231 KB
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2026-06-19 fix(mcu): remap A14/A15 from non-existent GPIO47/48 to GPIO45/46
    GPIO47 and GPIO48 do not exist in the ESP32-S3FN8 QFN56 package; physical
    pins 53 and 54 are XTAL_N and XTAL_P respectively. A14 and A15 are
    remapped to GPIO45 (pin 51) and GPIO46 (pin 52), the last available GPIOs.
    Without this fix decode_addr() always read A14=A15=0, making every
    address comparison against $D1xx/$D5xx/$D6xx/$D8xx fail silently.
    Also document XTAL pin numbers (53/54, not 55/56 as previously stated),
    the strapping pin boot behaviour for GPIO0/3/45/46 when connected to the
    Atari address bus, and add amssymb to the LaTeX preamble for \checkmark.
    [main.cpp]
2026-06-19 docs: fix PIN-MAPPING.md — GPIO45/46 are A14/A15, not unused; correct XTAL and VDDA pins
    - A14/A15 remapped to GPIO45/46 (pin51/52) throughout: section header,
    descriptive paragraph, A12-A15 table, firmware decode snippet, U4 table,
    "GPIO disponibili" note, QFN56 full pinout
    - Critical Boot Warnings: GPIO45/46 now show A14/A15 signal with correct
    strapping description (pull-down → LOW; VDD_SPI from LDO ~1.8V; ROM msgs
    disabled — both safe for FN8)
    - XTAL_N/XTAL_P corrected to pins 53/54 in section 5 table and ASCII art,
    "Pin esclusi" table, and QFN56 full pinout
    - Pins 55/56 identified as VDDA1/VDDA2 (analog power, not GPIO) everywhere
2026-06-19 fix(docs): correct VDD3P3_CPU at pin 46, EXTSEL_N (GPIO41) at pin 47
    The KiCad symbol confirms pin 46 = VDD3P3_CPU (power), not GPIO41/MTDI.
    GPIO41 (EXTSEL_N) is therefore at physical pin 47, not 46.
    Updated pin 46→47 for GPIO41/EXTSEL_N in:
    - firmware/MCU/src/main.cpp: PIN_EXTSEL_N comment
    - firmware/MCU/README.md: dedicated GPIO table, signal mapping table
    - firmware/MCU/Vera_Module_Analisys.ITA.tex: U3 signal table, lstlisting #define
    - firmware/MCU/Vera_Module_Analisys.ITA.pdf: recompiled
    - PIN-MAPPING.md: control signals table, dedicated GPIO table, U3 table,
    QFN56 full pinout (pin46=VDD3P3_CPU, pin47=GPIO41/EXTSEL_N)
    GPIO numbers are unchanged; only physical QFN56 pin numbers in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
    [main.cpp]
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2026-06-29 fix(6502): set fillval=$FF in linker script; fix vera_reg_name IRQLINE/Layer0; load PBI ROM from pbi_driver[]
    - pbi-driver.ld: add fillval=$FF so padding matches EPROM-erased value
    - Regenerate vera_pbi_handler.{bin,h} and pbi_rom_pkg.vhd with correct fill
    - main.cpp: add VERA_IRQLINE_L ($08) and Layer 0 registers ($0D-$13) to vera_reg_name()
    [main.cpp]
2026-08-27 docs(esp32): fix GPIO3 JTAG-source strap polarity; note why decode stays in software
    Corrected GPIO39-42 vs USB Serial/JTAG polarity per ESP32-S3 datasheet Table 3-5
    (was reversed), and noted the default unburned eFuse row makes GPIO3's level
    moot for JTAG source selection. Also documented in PIN-MAPPING.md why hardware
    chip-selects (/D1XX, /S4, /S5, /CCTL) are not used: no free GPIO on the
    ESP32-S3FN8, and RAMbo 256K emulation already requires full A0-A15 decode plus
    PORTB snooping.
    [main.cpp]
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2026-09-03 Fix eeplot PDF export: keep each schematic sheet's own page size
    eeplot forced every page of the exported PDF to the size of the largest
    sheet, anchoring smaller sheets top-left instead of keeping their native
    paper size. Patch record_wipe()/cr_pdf_end() so each page is sized and
    offset from its own bounding box, and wire patch application into
    output_job.sh's eeplot build/update steps. Regenerated VERA-MODULE-RBL.pdf
    with the fix.
2026-09-03 deleted all tracks and imported from schematics. It seems the load section from NETLIST has broken contents
    [VERA-MODULE-RBL.kicad_pcb]
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2026-10-06 firmware: VERA registers always decoded, IRQ sense on GPIO0, updated PBI ROM
    - main.cpp: DEV_SEL_N/EXTSEL_N for $D100-$D11F regardless of the $D1FF
    latch (the OS deselects the card after INIT and the driver never
    reselects it); latch uses only its own bit (data & 0x80); per-register
    trace only with -DVERA_TRACE_REGS=1 (it cost ~1 us inside the bus loop);
    optional -DVERA_HAS_VIRQ_SENSE=1 drives D7 on $D1FF reads from GPIO0
    - platformio.ini: esp32s3fn8-virq environment
    - 6502 handler and vera_common.inc synced from VERA_ATARI_PBI; regenerated
    vera_pbi_handler.h and FPGA/pbi_rom_pkg.vhd
    - docs: hardware requirements (open-drain IRQ stage, U19 OE gating, WR hold,
    reset sequence) and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
    [main.cpp]
2026-10-06 docs: link hardware notes, fix U6/U16 and GPIO0 in PIN-MAPPING, update firmware README
    - README: list PIN-MAPPING, VERA-ATARI-HW-REQUIREMENTS and HW-MOD-GPIO0-VIRQ
    - PIN-MAPPING: U6 is the Atari->board transceiver and U16 the board->Atari
    one (were swapped); GPIO0 is the BOOT0 net, not NC; ~mVIRQ is connected
    to U16/ECI (push-pull) and not a free channel
    - firmware README: VERA registers always decoded, $D1FF semantics, PlatformIO
    environments and VERA_TRACE_REGS / VERA_HAS_VIRQ_SENSE options
    [main.cpp]
2026-10-06 docs: update firmware analysis (74LVC4245 buses, always-on VERA registers, hardware checks)
    - replace the TXS0108E description with the current 74LVC4245/U23/U5 netlist
    (U6 Atari->board, U16 board->Atari were swapped)
    - PBI mode: VERA registers always decoded, latch uses only its own bit
    - PlatformIO environments and VERA_TRACE_REGS / VERA_HAS_VIRQ_SENSE options
    - GPIO0 is the BOOT0 net; optional ~mVIRQ sense
    - new section with the hardware findings from the driver/emulator work
    - regenerate the PDF
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2026-10-06 docs: VERA IRQ hook implemented and tested in the emulator
    The VIMIRQ hook is in VERA_ATARI_PBI (vera-tests/vera_irq.s, TESTIRQ.COM:
    13 PASS / 0 FAIL in NTSC and PAL); to be tested on the board after the
    open-drain IRQ stage is fitted. Link to the usage guide.
2026-10-06 firmware: wait 1 ms after CDONE before releasing ARESET; sync PBI ROM
    - VERA_POST_CDONE_DELAY_US (default 1000 us) between CDONE high and the
    Atari reset release, to cover the VERA internal power-on reset
    - 6502 handler synced (three beeps on WAIT_VERA timeout); regenerated
    - docs: requirements, firmware README, analysis .tex and PDF
    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
    [main.cpp]
2026-10-21 FPGA: fix RAMbo enable, write sampling and data bus tri-state; add simulation
    - RAMbo responds only with RAMBO_EN=1 and PORTB[4]=0 (was PBCTL[2], which
    the OS keeps at 1: internal RAM at $4000-$7FFF was never visible and main
    memory aliased bank 15); $D301 writes with PBCTL[2]=0 are DDR writes and
    are now ignored
    - latch, PORTB/PBCTL snoop and PBI RAM writes sample D on wr_strobe
    (200-240 ns after PHI2 rise) instead of phi2_rise (40-80 ns), before the
    6502 write data was valid
    - SRAM_WE_N is a registered pulse phi2_rise..wr_strobe, so the SRAM latches
    before PHI2 falls and the 6502 data hold time no longer matters
    - D[7:0] uses explicit SB_IO cells: the GHDL/Yosys flow does not i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
2026-10-21 docs: fix ESP32-S3 crystal pins in README (XTAL_P = QFN56 pin 54, XTAL_N = pin 53, per datasheet v2.2 Table 2-1)
2026-10-21 docs: fix ESP32-S3 pin table and VDD_SPI strapping against datasheet v2.2
    - PIN-MAPPING §8: pins 1-4 are LNA_IN, VDD3P3, VDD3P3, CHIP_PU (were
    GND, 3V3, EN, reserved); SPI function names of pins 28-35 per Table 2-14
    (GPIO26 = SPICS1, PSRAM CS, absent on the FN8; flash uses GPIO27-32);
    pins 36/37 are GPIO48/GPIO47 (SPICLK_N/P), not reserved
    - GPIO47 and GPIO48 exist and are free on the FN8 (memory uses them only in
    Octal SPI): §7, §3 and VERA-ATARI-HW-REQUIREMENTS no longer say that every
    GPIO is assigned
    - VDD_SPI strapping was inverted: GPIO45 LOW gives 3.3 V from VDD3P3_RTC,
    HIGH gives 1.8 V (Table 3-4). The FN8 needs 3.3 V (Table 1-1), so A14 HIGH
    at reset would stop the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
2026-10-21 docs: mark the project as WORK IN PROGRESS, not working
    Warning banner at the top of the English and Italian sections and a
    status badge: the board has not been built or tested, firmware and docs
    are verified only in simulation or on paper.
2026-10-23 This should be the latest schematic change before finalizing the PCB. ERC gives me NO ERRORS! Yeeeah!
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2026-10-25 firmware(esp32): bus loop critical path in inline assembly
    - settle wait, sampling, decode, control write and read-data drive in one
    asm block with every operand in a register and the constants loaded
    before the wait: control signals 11 cycles + 1 APB read after the wait
    (was 18), data on the pins 14 cycles later (was 22)
    - GPIO.out / GPIO.enable_w1ts / bus release as posted stores without
    memw (Xtensa keeps stores in order; the CPU no longer waits for each)
    - PHI2 edge waits in assembly: 3 cycles per sample on both edges
    - PIA copies and latch in a DRAM struct, pending write in two registers:
    no stack traffic on the critical path
    - $D1xx/$D5xx (CT_SLOW) leave the asm block and fin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
2026-10-25 firmware(esp32): decide the VERA register page in the bus loop assembly
    - bus_build_slow_tables(): second-level table bus_slow[selected][A0-A7]
    for the CT_SLOW page ($D1xx in PBI, $D5xx in CCTL), checked by the host
    test against bus_slow_ctrl() (16793861 checks, 0 errors)
    - the assembly block loads it on the slow page: DEV_SEL_N ~18 cycles +
    1 APB read after the settle wait instead of ~30; the C fallback is gone
    - settle wait kept as the simple loop (unrolling does not help the worst
    case: backward branch and taken-branch exit)
    - session notes: what is left needs measurements or the U19 ~OE gating
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2026-10-25 firmware(esp32): settle time from the predicted PHI2 fall, RAM stores in PHI1
    - the address settle wait starts from the earlier of the detected PHI2
    falling edge and the predicted one (PHI2 rise + BUS_PHI2_HIGH_MAX_NS,
    default 292 ns: PAL high phase plus 10 ns duty error): when register
    side effects run past PHI2 falling, the next sample moves by at most
    ~23 ns instead of the whole overrun
    - PBI RAM / RAMbo stores are queued (card.wr_mem) and done in the next
    PHI1 (~32 cycles with the rest of PHI1, within the 36-cycle settle
    wait): a memory write never delays the following cycle; latch and
    PORTB updates stay in the rest of PHI2
2026-10-25 docs(tesi): rewrite as the gated board with the current firmware
    - timing_model.py rewritten: initial (f311311) and current firmware,
    U19 ~OE gating, "outputs kept enabled" option, read after a register
    write; worst case limit NTSC 14.1 / PAL 14.5 APB cycles
    - thesis: hardware chapter with the 74LVC20 gating (schematic, truth
    table), new firmware chapter with the assembly listing, timing
    verification on the new disassembly, a chapter on the first version
    and its fixes, open issues, measurement plan; results stated as
    analytical, not measured
    - session notes: the "outputs kept enabled" option does not extend the
    worst case (write-cycle disable constraint at ~13-14 cycles)
2026-10-26 hw: U19 ~OE gating, ESP32 strapping, open-drain IRQ, spare channels
    No board has been built yet: these changes go into the first batch.
    - U19 ~OE = NAND(PHI2, NAND4(R/W, DEV_SEL_N, EXTSEL_N, MPD)) with two
    SN74LVC00A (U24, U25) instead of the unobtainable 74LVC20; U23 no
    longer drives ~OE.
    - ESP32 strapping: GPIO47 (~ABUS_OE) drives ~OE of U3/U4 with 10K
    pull-ups R7/R34, so GPIO45/46 (A14/A15) read LOW at every reset;
    R71 10K pull-up on GPIO3; C25 (CHIP_PU) 100 nF -> 1 uF.
    - VERA IRQ: U26 SN74LVC1G07 open-drain buffer with C69 replaces D1,
    which was mounted backwards.
    - U16 no longer drives ~HALT, RD4, RD5 from floating inputs: outputs
    unconnected, test points moved to the Atari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
2026-10-26 docs: align requirements, pin map and thesis with the revised board
    - Requirements: 2.1 gating with U24/U25, 2.3 IRQ with U26, 2.7/2.8
    fixed, new 2.9 (strapping), 2.10 (U16 HALT/RD4/RD5), 2.11 (no diode
    on the Atari 5 V: program the board only out of the Atari).
    - PIN-MAPPING: GPIO47 = ABUS_OE_N, strapping rows, 74LVC4245 A/B sides
    (A = Atari 5 V, B = 3.3 V), U16 spare channels, IRQ path.
    - Thesis: section 3.2 and figure 3.2 redrawn for two SN74LVC00A, new
    section 3.4 on strapping; timing_model.py counts four LVC00 gates
    from the controls and one from PHI2 (ESP32 data margin unchanged).
    - Analysis document, README and session notes updated.
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2026-10-29 output_job.sh: run on Debian 13 and the KiCad 5 AppImage too
    Keep working on older Debian (system KiCad 5, Python 3.9, cairo 1.16) and
    also run where KiCad 5 is only the AppImage:
    - generate_bom.py replaces xsltproc + bom2grouped_csv_jlcpcb.xsl, which
    was missing; plain Python 3, same output byte for byte as the XSL
    - run_generate_cpl.sh uses the system pcbnew when there is one, otherwise
    "kicad5 --python" (AppImage v2.2.0+), and reports a failure instead of
    going on with stale CPL files
    - eeplot is rebuilt when its binary misses system libraries (e.g. after
    a Debian upgrade) and the build checks fig2dev too
    - KiCad 5 symbol libraries come from /usr/share/kicad/library or, when
    mi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
2026-10-29 output_job.sh: KiCad 5 3D models in the export, eeplot fixes
    - kicad-cli (KiCad 7+) has no .wrl models, so every ${KISYS3DMOD}/...wrl
    model was missing from the STEP/VRML: run it with KISYS3DMOD on the
    KiCad 5 models, the system ones or a copy taken once from the AppImage
    - eeplot-kicad5-schematics.patch: find the symbols of a library given
    without a directory (e.g. the -rescue.lib) and skip embedded images
    instead of stopping on them
    - apply every patches/eeplot-*.patch and rebuild eeplot when they change
    - copies from the AppImage go through a .partial directory, so an
    interrupted copy is not taken as complete
    - kicad_virtual_cleaner.py: a board without virtual parts is not an er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
2026-10-30 tools: add unmeander.py to strip length-tuning meanders
    KiCad 5 meanders are plain track segments, so pcbnew can only delete the
    whole track. The script replaces each meander on the selected nets
    (default ^m[AD]\d+$) with one straight segment and leaves the rest of
    the routing alone.
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
